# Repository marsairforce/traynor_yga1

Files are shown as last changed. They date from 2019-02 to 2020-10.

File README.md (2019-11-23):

# Traynor YGA1 Guitar AMP

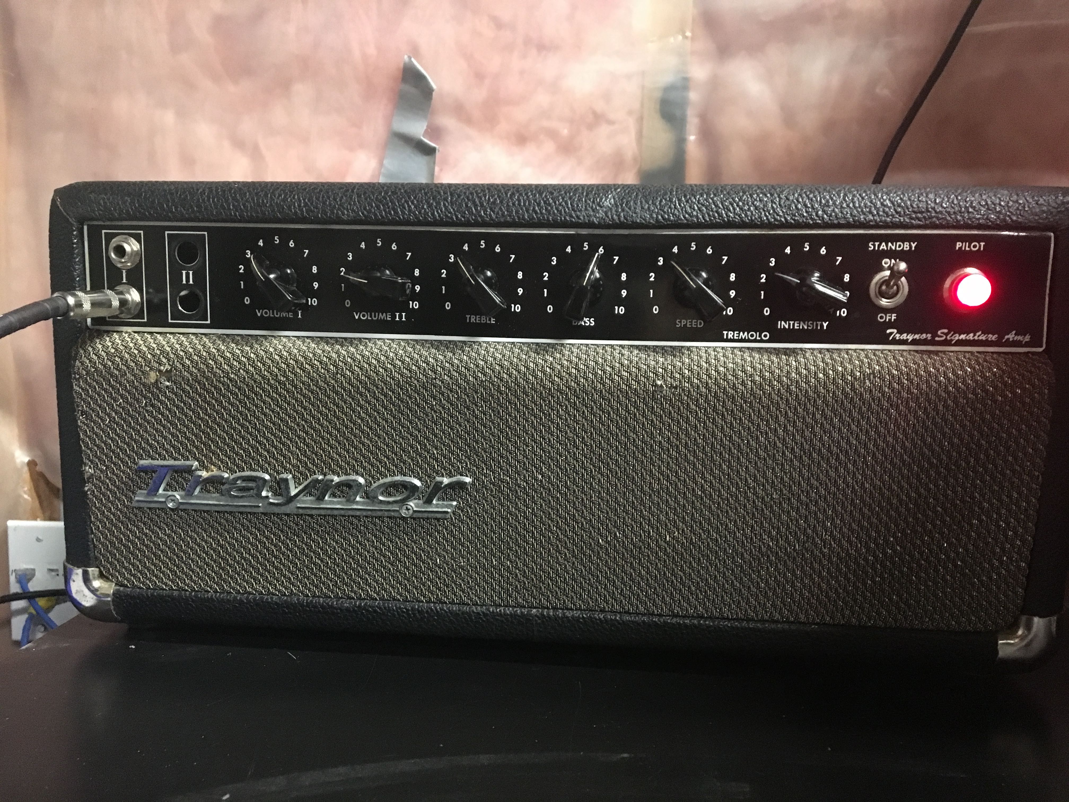
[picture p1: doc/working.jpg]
Working again


This is a project where I restored this old Traynor Signature guitar amplifier.

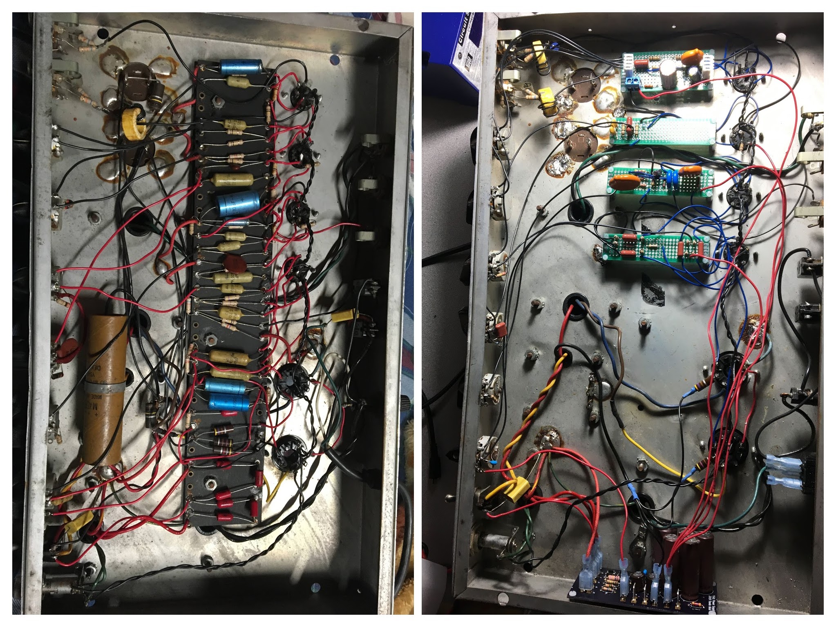
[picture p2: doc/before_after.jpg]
before and after


It was an adventure in learning how vacuum tube circuits work, some history of Canadian music and equipment, humility, nostalgia, and appreciation of finer things.

## Background

I got this in mid 1990's from my boss's nephew, Chris. It had caught fire and burned. The original wires were those 1960's cloth kind of insulation.

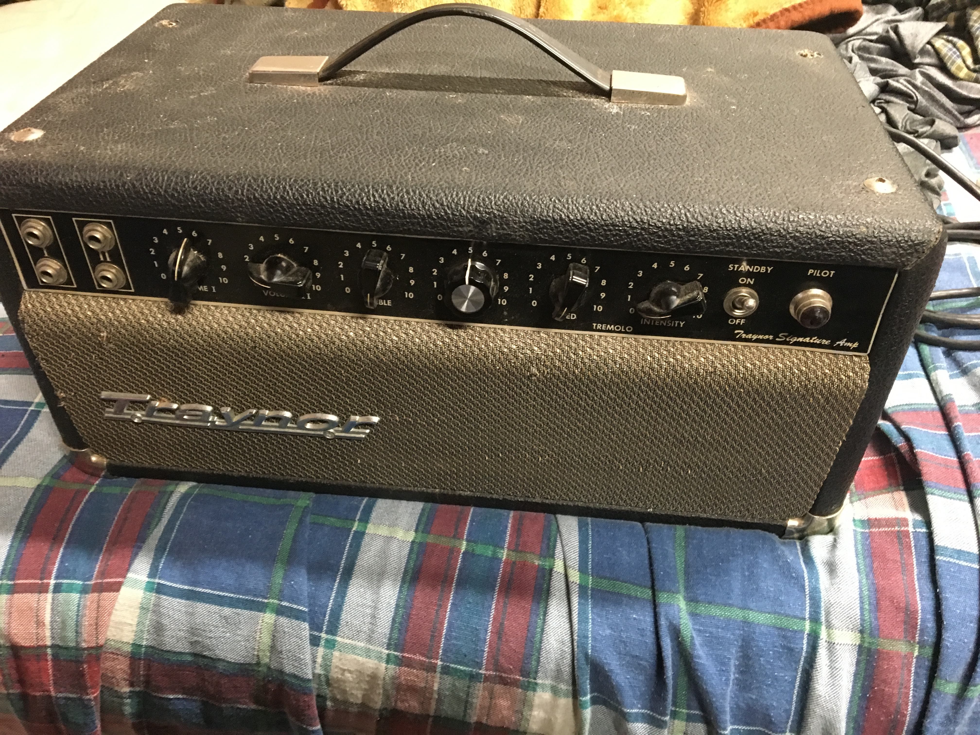
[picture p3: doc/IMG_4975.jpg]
Amp head


I did not understand vacuum tube electronics in depth. Other than they were metal in glass. No moving parts or semiconductors here. Just resistors and capacitors. If I replace all the burnt wires it should just work again right?

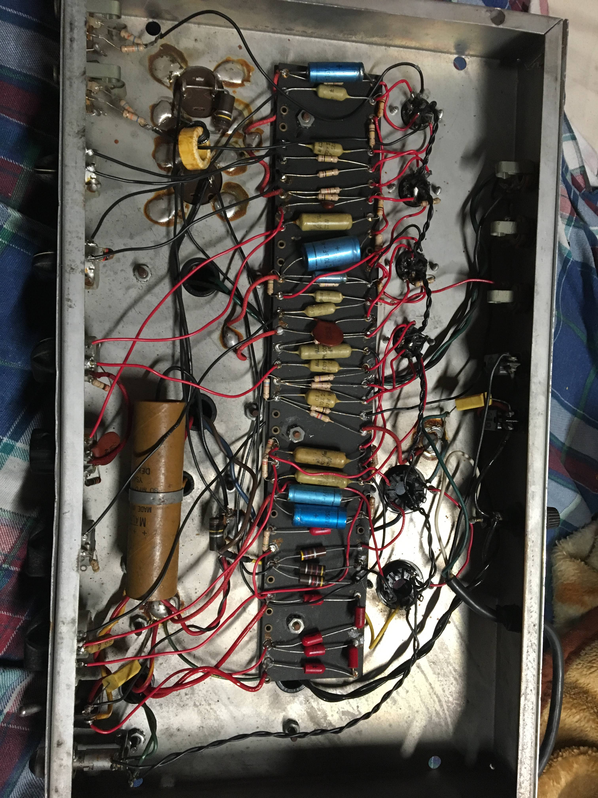
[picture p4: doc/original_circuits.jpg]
original circuit


I used modern wires (for 1990's) to rewire it.

A tube socket was missing a pin so I made a loop of wire and jammed it into the hole. Close enough.

Looking at the wiring I am a bit uneasy with the high voltage DC wires right there beside the input high impedance wires. The old point to point or ladder circuit construction is a lot different than anything I would consider to be a safe design today.

Recent research shows these amps are [basically indestructable](https://reverb.com/ca/news/a-guide-to-vintage-traynor-amps).

I only stopped using it when I stopped playing guitar when busy with university work. I moved away for internship and never returned home. My mom had it burried in the clutter at the house. She passed away, her friend Sandy who handled the estate shipped it to me.

But this is now 20 years later. Now that I am aware of old devices with the old paper style capacitors becoming electrically "leaky" I am afraid to even plug it in, thinking there could be a short and it would just burn the power transformer. Or something else would catastrophically fail.

## My gear

The amp worked well for me. I used it mostly with that Kramer guiter I custom painted to look like Franken Strat. It just sounded good.

I used it with discrete effects pedals to get the tone. And the built in tube tremolo feature was cool sounding. I remember having a Boss compressor pedal, the Boss HM2 pedal. :ater on I had an ADA microtube 200 with a Boss ME-10. I later sold the ME-10 to Chris Davis. Still have the ADA MT-200. That is probably a project in itself to see if that still works.

I had a yorkville bass amplifier. It went with the Ibanez 5 string bass I donated to the highschool when I graduated. But I remember using this with the bass because I had the speaker cabinet to go with the amp.

Unfortunately I did not get the speaker cabinet back.

## Ethics

Do we maintain everything as "all original", preserving the vintage electronics style of the day (the ladder construction).

Or do we create a modern PCB modules, connectors.

Or something in between.

I was amused with the [ship of Theseus](https://en.wikipedia.org/wiki/Ship_of_Theseus) thought experiment here.

At what point does it matter to continue to use this same chassis. I could go all the way and order new power transformer, choke, output transformer, tube sockets, tubes, and discrete components and build a fresh new amp on a new chassis.

Reading into the history of [Traynor amplifiers](https://en.wikipedia.org/wiki/Traynor_Amplifiers). They were originally hacked together by a tech at Long and McQuade to be a cheaper option for their equipment rentals. So less expensive but good enough.  Do I really want to build based on this? Or should I learn what a high end amp design looks like.

In any case at this time I really do not need to mass produce tube amplifiers. Even if I could get good prices on the components, there is no compelling reason to build one as it is at least as expensive as buying one already made and well packaged.

The amp was labelled as "ideal for modifications". It is in the herritage. And being a Canadian, I feel very special to have a piece of Canadian music history to play with.

And then some discussion from [Mr Carleson's Lab](https://www.youtube.com/watch?v=7VBVSEevXaY) sais to replace all the old capacitors, because they are all basically garbage when they age. And this will hurt the reliability of the amp over time.

Since this amp was created to be a regular amp at the time, and is kind of in rough shape. I think I will do my best to make it look nice on the outside (new chicken foot dial).

But for the inside I will replace the power supply circuitry with updated construction.

## Inputs

This amp has 2 input channels. They are mixed after the first preamp stage.

Each input has 2 1/4" mono audio Jacks. They are configured as

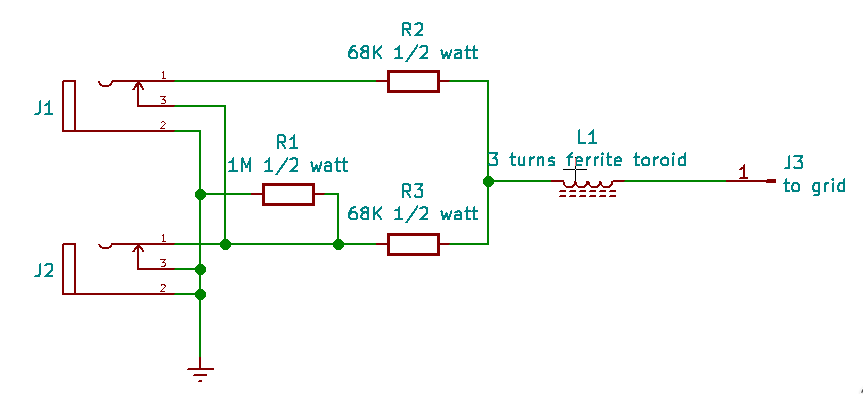
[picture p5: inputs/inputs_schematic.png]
inputs


Some thinking about this:

If we plug something into only J1:

* R1 is removed from switch on J2
* Signal is 1/2 of input because of R2, R3 resistor divider.

If we plug something into J2 only:

* R1 is in use.
* R2 is connected in parallel to R3, because switch in J1 is closed.
* Vo = 1M / (1M + 32K) or 97% of input voltage.

So here J1 is a "LO" inpedience, or line input, and J2 is a "HI" impedience, like microphone.

In our Amp, I put the HI inputs on the bottom.

## Preamp

The preamp stage uses a single 12AX7A, one half for each input channel.

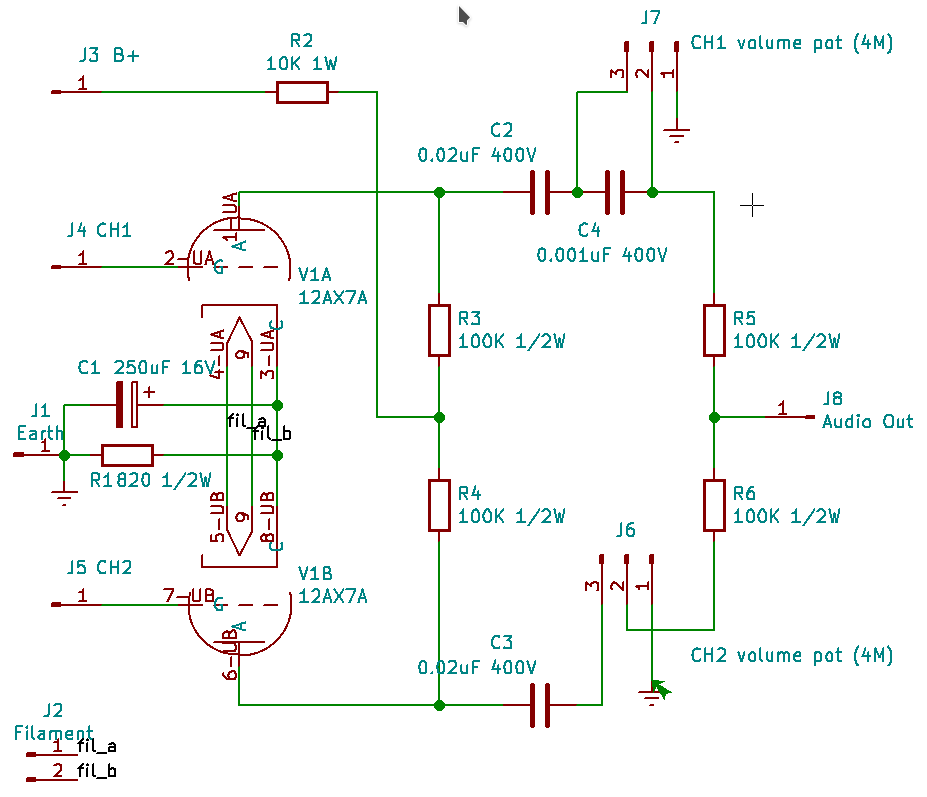
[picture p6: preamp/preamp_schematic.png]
preamp


This configuration is what is referred to as a [common cathode triode amplifier](http://www.aikenamps.com/index.php/designing-common-cathode-triode-amplifiers).

* We can see Channel 1 has the extra 0.001uF capacitor in parallel with the volume potentiometer. This will have the effect of a high-pass filter, or at least it will cut out a lot of the lower frequecies.

> This is actually channel II. At this time when reading the schematic I assumed to be channel I, but on the chassis it is labelled as Channel II.

Using a [cathode bypass calculator](https://www.ampbooks.com/mobile/amplifier-calculators/cathode-capacitor/calculator/), we can see for the values used here on the cathode (250uF, 820 ohm), that the gain is nearly uniform for all frequencies of input.
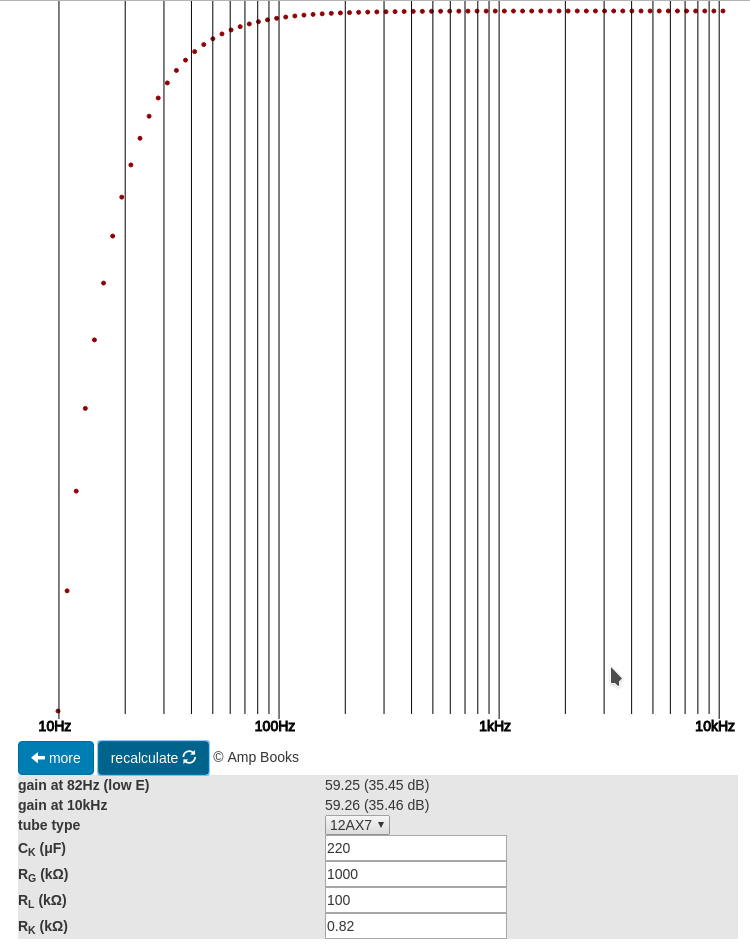
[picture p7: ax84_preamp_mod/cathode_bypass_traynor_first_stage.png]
traynor preamp stage


## Tone

The tone control circuit uses a 12AX7 as another intermediate amplifier stage.

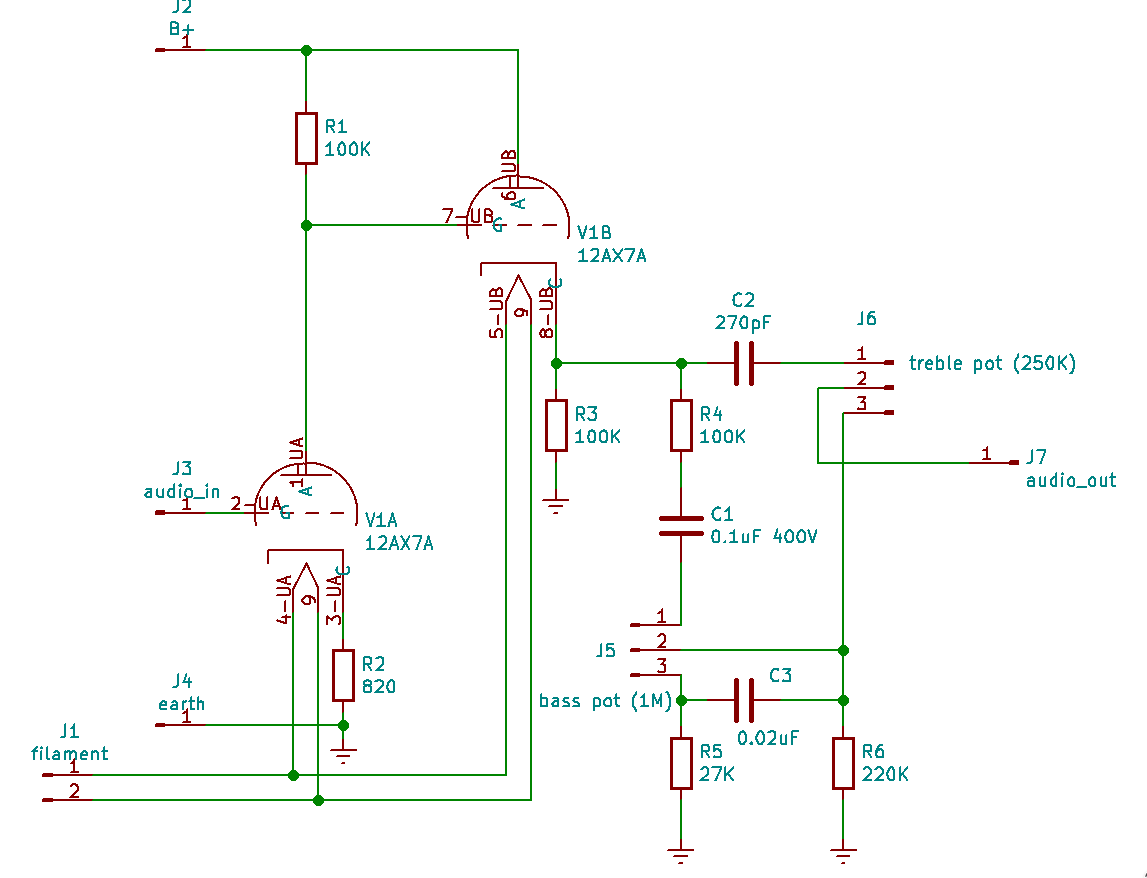
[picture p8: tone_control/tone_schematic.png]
tone stack


This configuration of the two triodes is called a [DC-coupled cathode follower](http://www.valvewizard.co.uk/dccf.html) It is by design built "badly", but this creates a low impedance output to drive the RC network or "tone stack" that manipulates the tone.

## Power Stage

This am is a push-pull amplifier.

Here a 12AX7A is used as a [Schmitt phase inverter](http://www.r-type.org/articles/art-123g.htm)

It also mixes the audio imput with the negative feedback from the output transformer.

The 7027A tubes are used here because they are higher power versions of the 6L6 tubes.

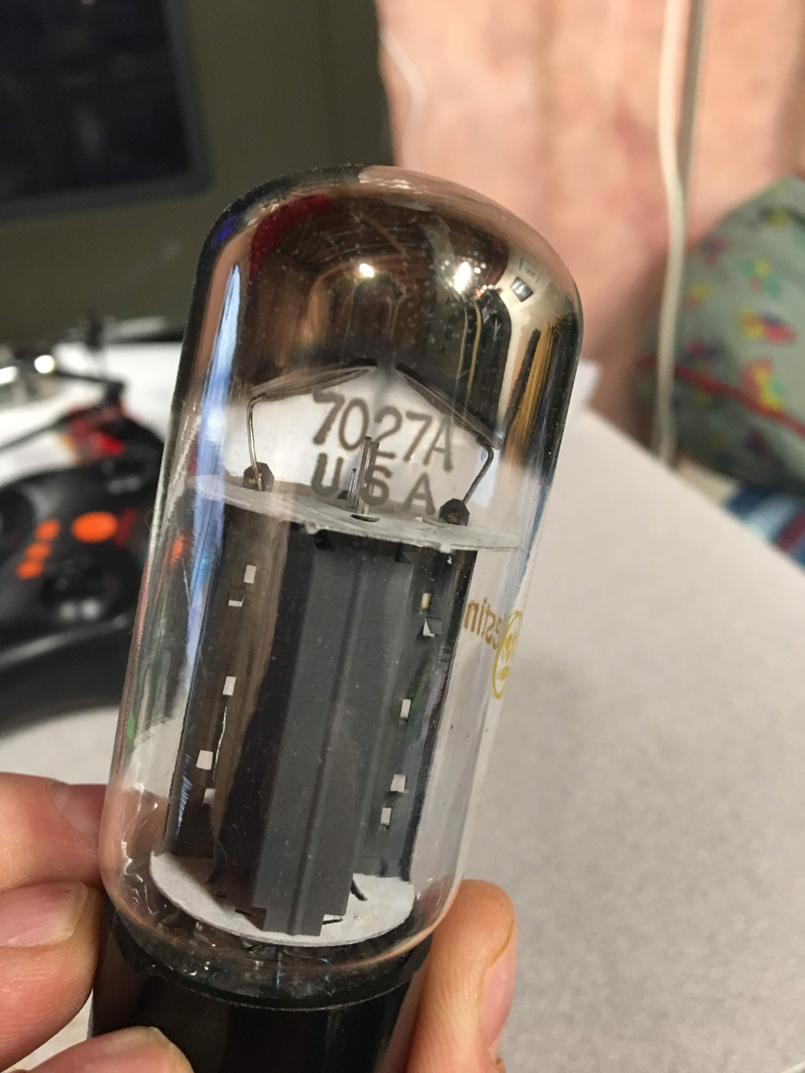
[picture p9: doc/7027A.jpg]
7027A


The 6L6 tubes are beam power tetrodes. They were created to circumvent patents in the pentode design. So beam power tetrodes have the function of penodes, but have a lower transimpedience, which works to make them more linear and have less distortion.

The output from the 7027A tubes is high impedence, so these feed the windings of an audio transformer. Because of the push pull design, the transformer center tab is connected to B+.

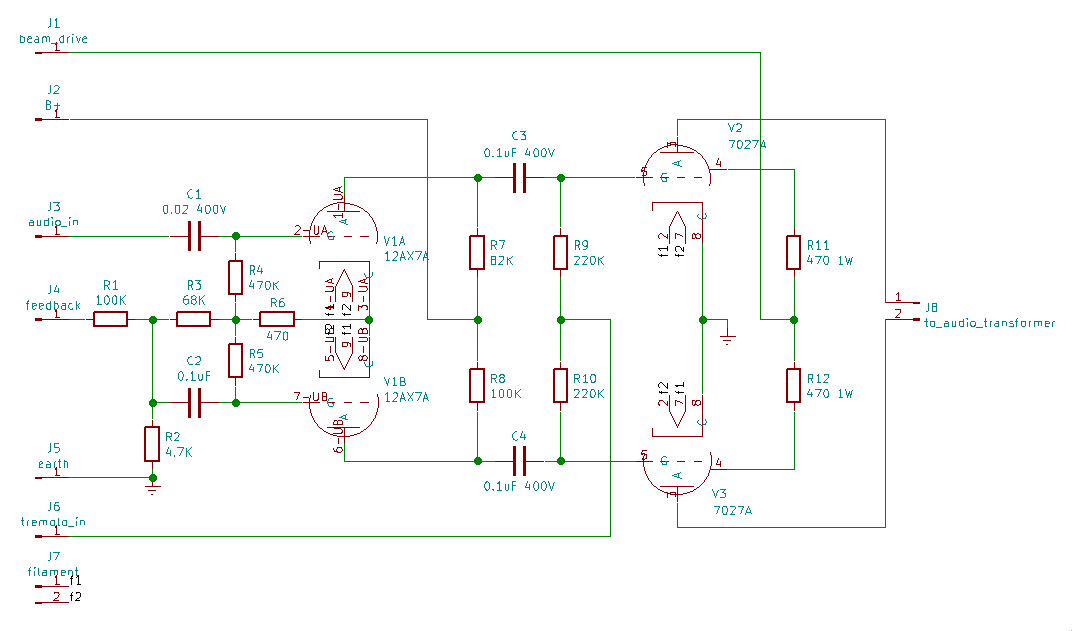
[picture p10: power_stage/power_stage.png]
power stage


* It drives the two 7027A through a capacitve coupling.
* The input from the tremolo oscillator circuit is mixed in.
* Why is R8 100K when R7 is 82K?  The small difference here of 18K?

## Tremolo

The tremolo uses a low frequency oscillator to modulate the audio volume in the power stage.

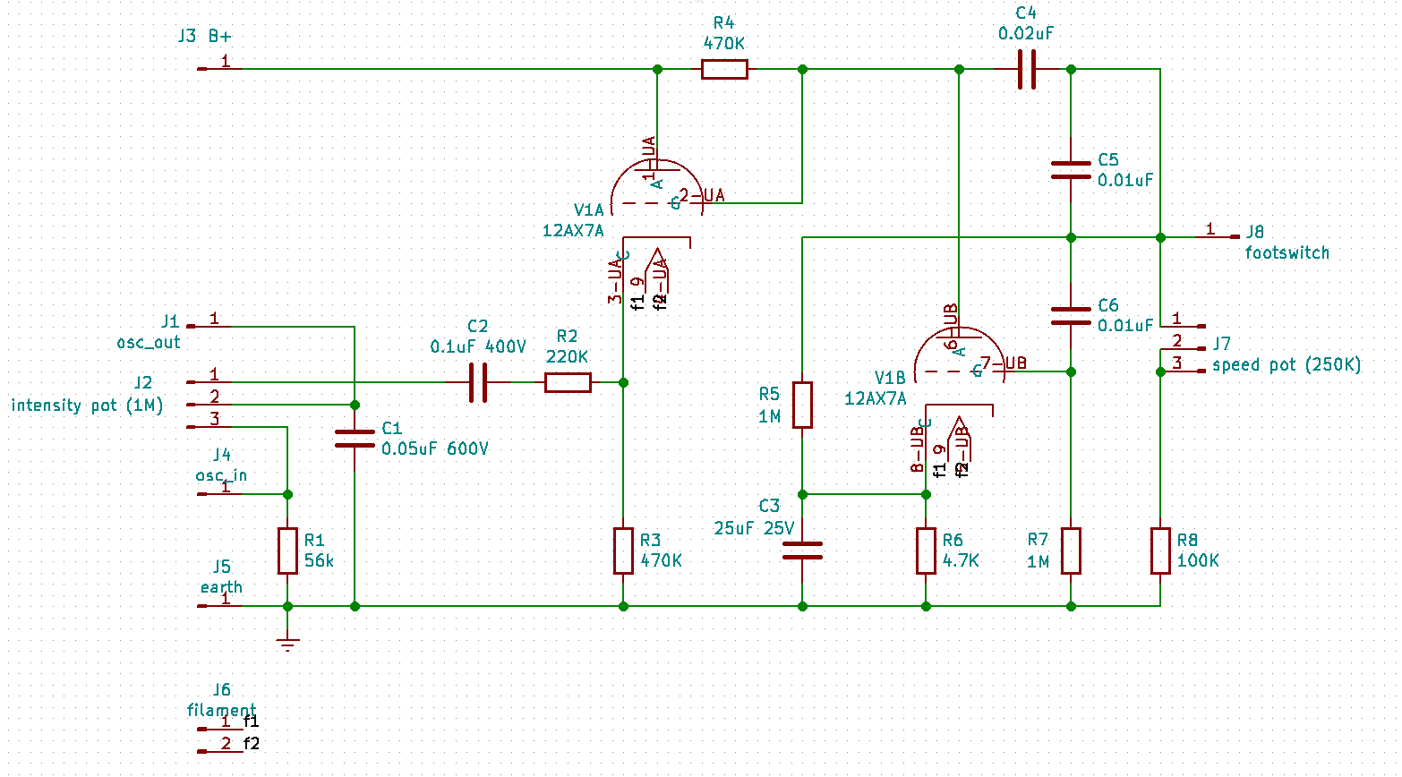
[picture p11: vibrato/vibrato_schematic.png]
vibrato


* I actually put R1 onto the power supply board too.

This looks a bit like this schematic from [popular electronics](http://www.rfcafe.com/references/popular-electronics/build-your-own-vibrato-dec-1957-popular-electronics.htm)

## Power Supply

This is a linear power supply with DC smoothing capacitors and a choke, but no regulation.

The power supply produces about 400V DC at the output of the diode rectifier.

The voltage that gets to the anode of the 12AX7A in the preamp stage is about 320V

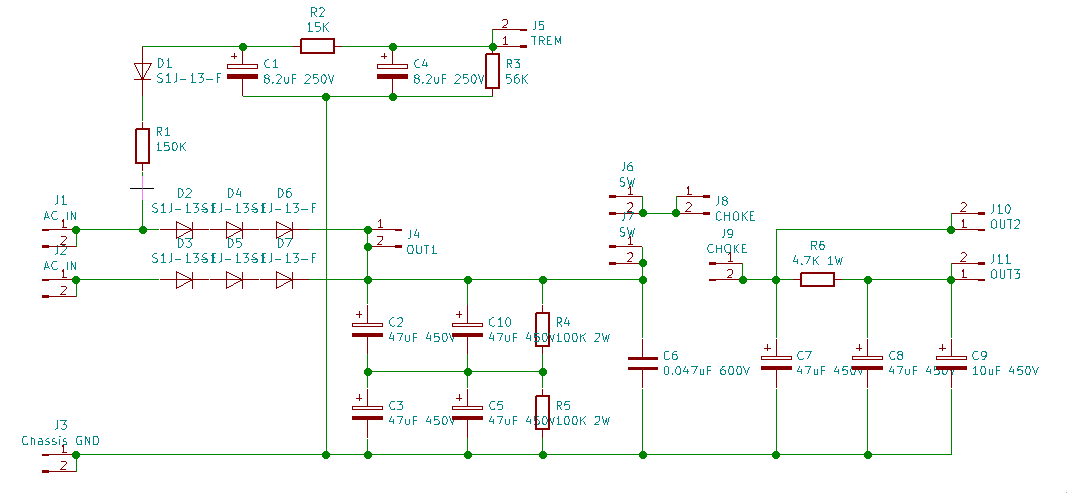
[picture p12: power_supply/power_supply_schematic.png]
power supply


* Why in this schematic is the power to the output audio transformer not after the standby switch. As it is in the original schematic this means the tubes would still be live when in standby with power on. - I later fixed this in my amp.

### Voltages

To measure the voltages I turned on the amp and waited about a minute for them to warm up. Initially the voltages were highter but they stabilize once the tubes are loading the circut. No audio input during the measurement.

* After the choke: 400V DC; 3V AC ripple (This ripple is probably because the capacitors are bad?)
* After the 4.7K resistor, B+ into the tone stack and vibrato: 340V DC ; 0.2V AC ripple.
* At the input preamp after the 10K resistor: 216V DC ; 0.2V AC ripple.
* Voltage into vibrato circuit: -40V; 0.2 V AC ripple.

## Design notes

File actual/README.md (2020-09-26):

# Schematic of current state of the amplifier

I will try to update this to be as current as possible to how the amp is actually wired up.

> Refer to the original schematic PDF when needed.  Where possible component reference numbers were reused.

## Preamp

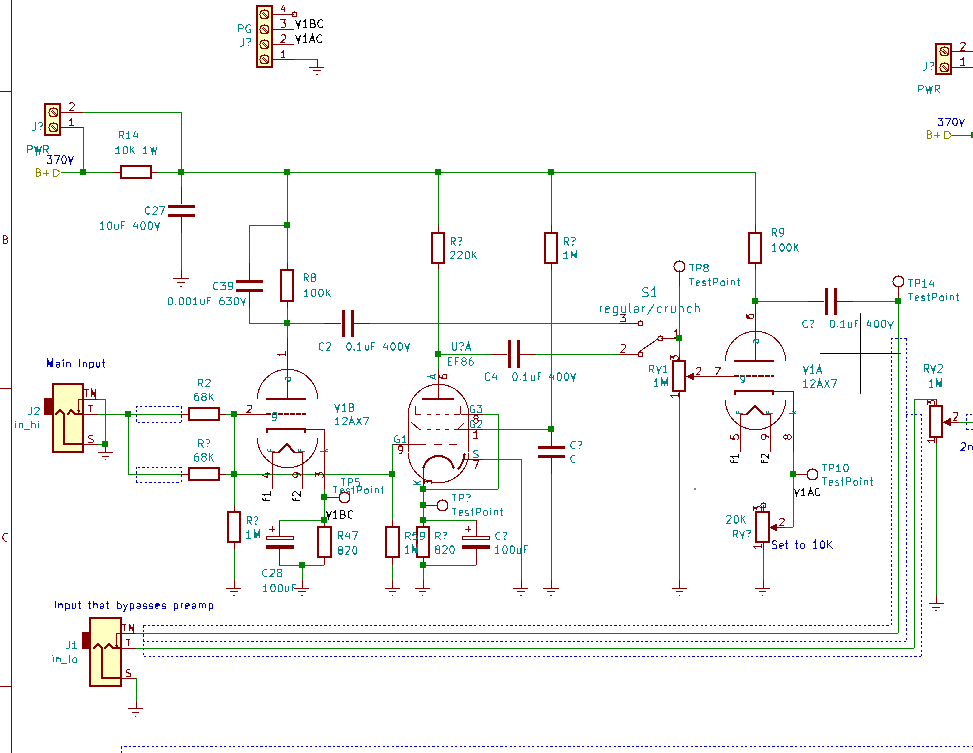
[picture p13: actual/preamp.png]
preamp


Notable changes:

* The input stage is no longer two parallel channels, but only one channel.

* You now have your choise of first stage preamp
  * A 12AX7 based on the original schematic. I added a plate bypass cap to help make it warmer (less high frequencies).
  * An EF86. This has a bit more gain and is a lot brighter sound to it.
* The second gain stage is a cathode clipper type configuration. The adjustable position lets me change the bias on the tube to allow it to distort more. I currently have this at about 2K
* Stock 2M pots for volume were changed to be 1M, mostly because this is all I could find. But also the old values seemed to do cause the amp to do oscillating or squealing when turned up.
* Added 1M grid stop resistor to be right before the input to the tube, instead of before the 68K resistors from the input jack.
* Using RG-178 coaxial wire for sensitive signal paths.

The power supply now supplies 4 additional tubes than the amp originally had. It seems way over sized for what it was designed to handle.

## Tone Stack

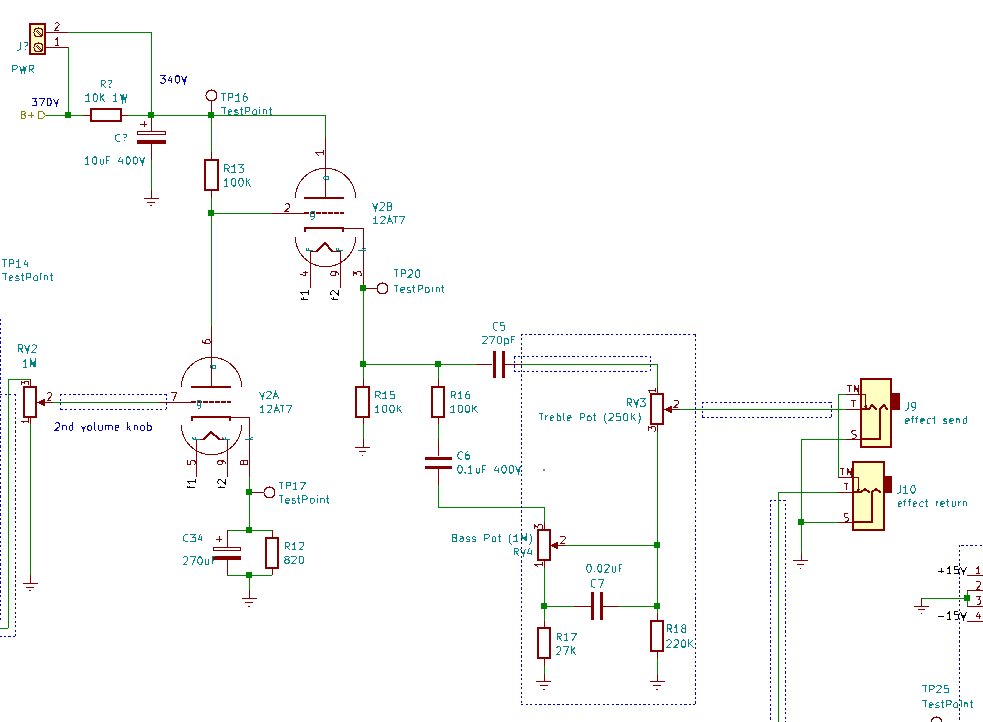
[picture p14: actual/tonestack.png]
tone stack


This is the most part the original tone stack. I just like how it sounds.

* The powr to V2 has been moved to go through a 10K resistor and a 10uF capacitor. I discovered by measuring with the scope there was a to 300mV 120Hz ripple on the power supply. This is as far as I can tell how the amplifier always was. It always had a small AC hum to it. I found I could swap out different tubes in this socket and make it get a bit better. But really what made the hum go away was the extra power supply filtering I added.
* The tube socket had pins 2 and 6 soldered together at the socket, under the filament wires. I was thinking this was picking up some of the noise from the AC filament wire that was right there. Sure enough, just rewiring this socket makes a little bit of improvement on not hearing hum on the speaker. This was another original assembly artifact or bug that I fixed with thea mp.
* There is now an effects send/return jacks. This amplifier did not have his. I like to use it a lot to add a noise gate, or digital delay effects after the preamp.
* The output of the tone stack (effects loop jacks) now goes to the reverb unit instead of the phase inverter.

## Reverb

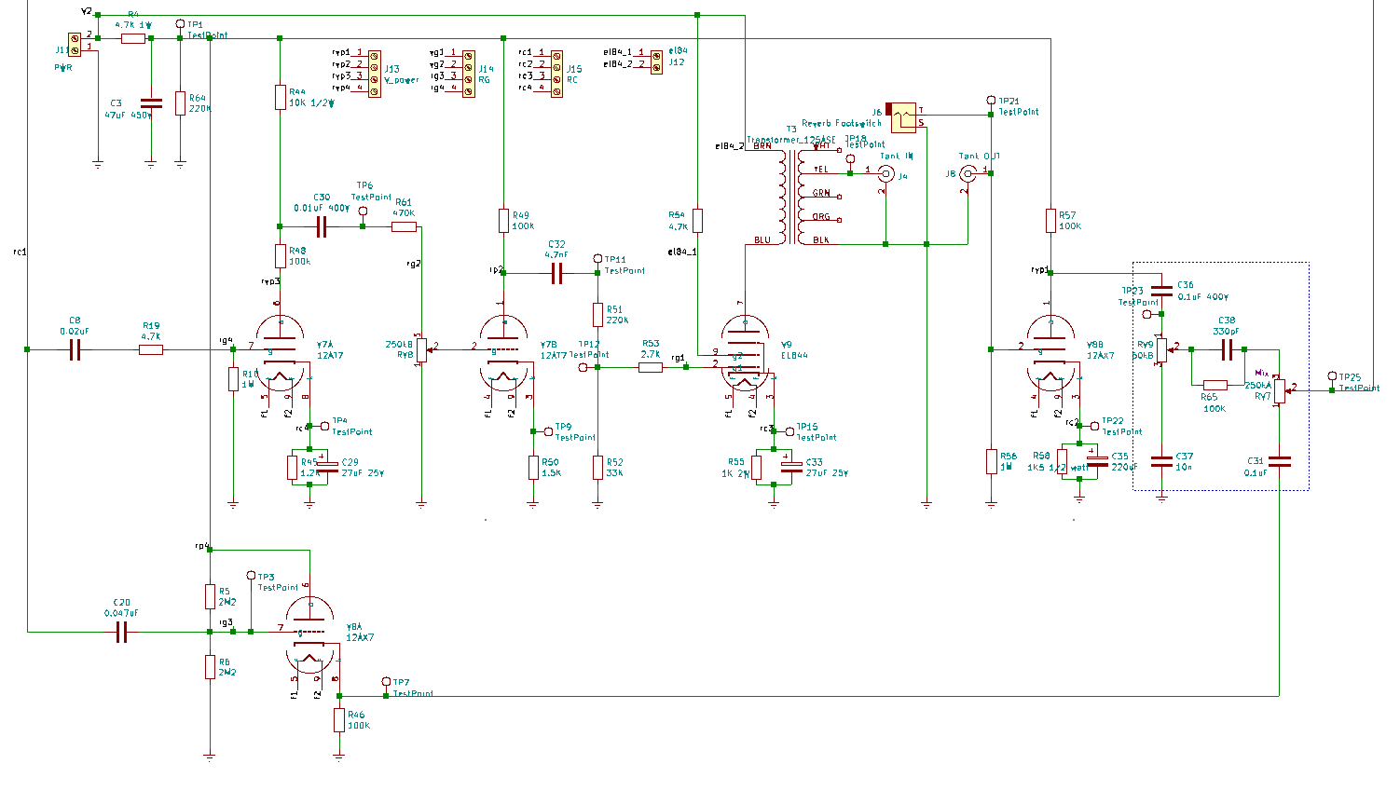
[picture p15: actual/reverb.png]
reverb


This is an entirely new component. The amp originally did not have reverb effect.

I ordered a mod reverb tank from NextGenGuitars. They are right here in Ottawa, great service for having stuff shipped. It's almost as fast as DigiKey.

This circuit is based on a reverb circuit schematic I found on the internet. I think from "Tube Town Reverb Kit".  They specify to use an EL844. I tried an EL84 for fun. I can't really notice a difference. But it kind of feels like the EL84 can overdrive the reverb output transformer, so you can get some intereting sounds with that. For now I will stick with the EL844.

The power transformer in this amp seems to be way over sized and does not even blink when I add 3 more tubes. Which is convenient.

I took some time to wire up the discrete components on its own circuit board module, like the other parts of the amplifier. It is now a hairy wires mess inside. But it works. After some preliminary testing and tracing all the component connections before powering it on, it worked for me right out the door.

I am amused by the complexity. To add reverb, you basically build a mini amplifier, inside your amplifier. I can see why the modern amps use digital modelling circuits.

Though I really appreciate having a tube driven real spring reverb effect. It is so much better to me than a reverb effect pedal anyway.

* using RG-178 shielded wire for the sensitive audio paths, like return from the reverb tank to the regeneration triode.
## Output

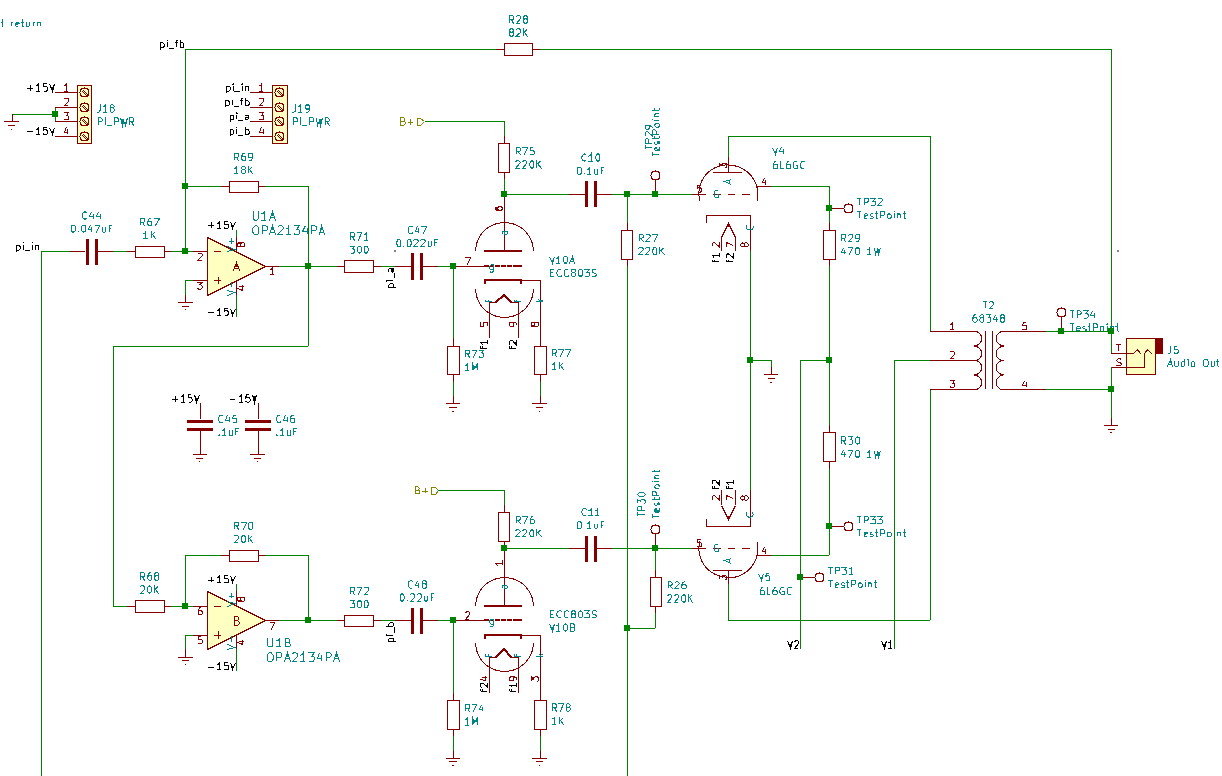
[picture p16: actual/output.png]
output


* Replaced the "long tail pair" tube based phase inverter with a solid state op-amp phase inverter.
  * This required a +/-15V DC power supply. I achieved this using a small DC-DC converter and diode rectitifer attached to the filament supply.

I was having some of that terrible buzz that means the phase splitter is not tracking opposite phases like it should. The values are all the right ones and it appears to be working. But It is likely stray capacatance, or magic that is letting it not operate properly. I am tired of the magic of this too. The op-amp phase inverter is a lot more precise than the long tail pair circuit.

* The annoying buzz or background hum that was always there is now gone.
* Fixed the squealing when gain knobs or tone knobs are up.

> I was chasing several high frequency oscillations since adding the reverb circuit. Having the gain up a bit past mid point, or having the tone control for the reverb on would cause screeching or loud hum and buzzing. Like the phase inverter was not working properly from being loaded.
> I have a feeling some of the noise is coming from stray capacitance from the terribly arranged and too long unshielded wires everywhere.  It is a side quest to make the wires as short as possible.
> It would appear the op-amp phase inverter has helped a lot of these demonic problems now as well!

One thing I do worry about, is if the audio signal is ever hundreds of volts like it may have been in the tube amplifier, that would be ok for the tube phase inverter. But the op amp would get roasted.

I measured the input voltages, and it seems to be the order of a couple volts. So this is likely ok for the levels I plan on using the amplifer.

## Power Supply

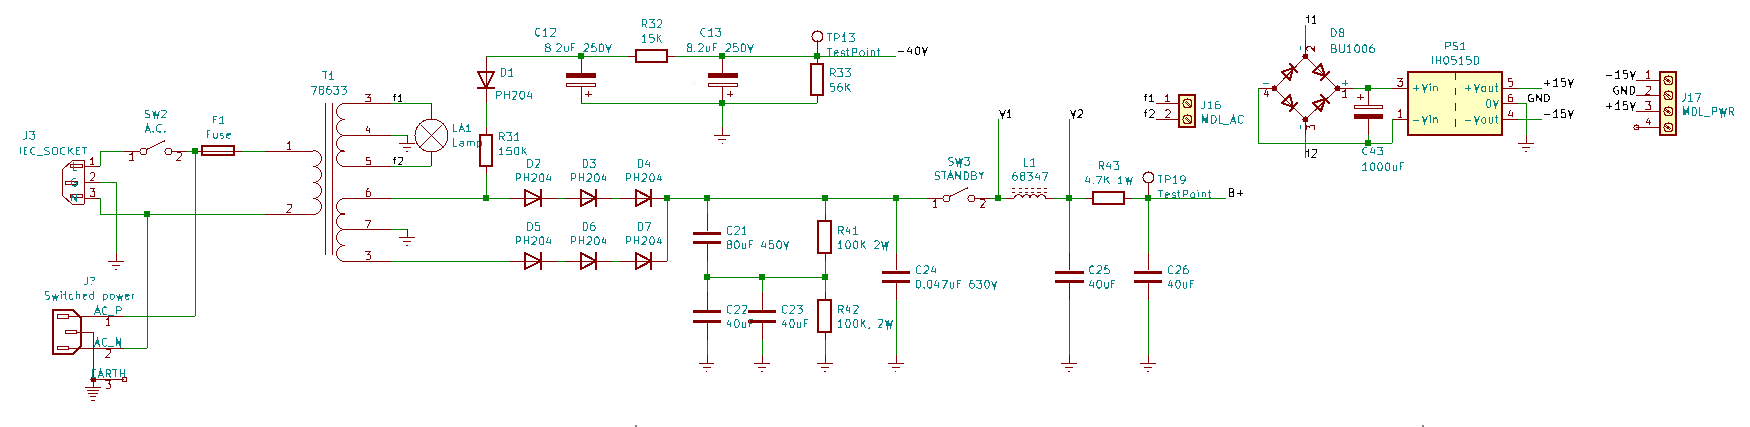
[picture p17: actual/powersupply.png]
power supply


* Removed the "death capacitor"
* Now having the V1 voltage to the output transformer switched. Before it was not switched by the bypass switch.
* I built a convenient custom circuit board, so these high voltage parts are safely tucked off to the side. This was among the first enhancements. The old turret board and chassis mounted capacitors had high voltage wires spread everywhere.
* Added a new module to use the [Recom RS-0505D](https://www.digikey.com/product-detail/en/recom-power/RS-0515D/945-1543-5-ND/2321270) to provide the +/-15V DC for the op amp in the phase inverter, by using the filament supply.
* Moved all the power entry chassis components to one corner. Before they were kind of sprawled over the back of the chassis.
* Added an IEC outlet after the power switch. This will allow me to switch the power to my pedal board from the amp switch now.

## Tremolo

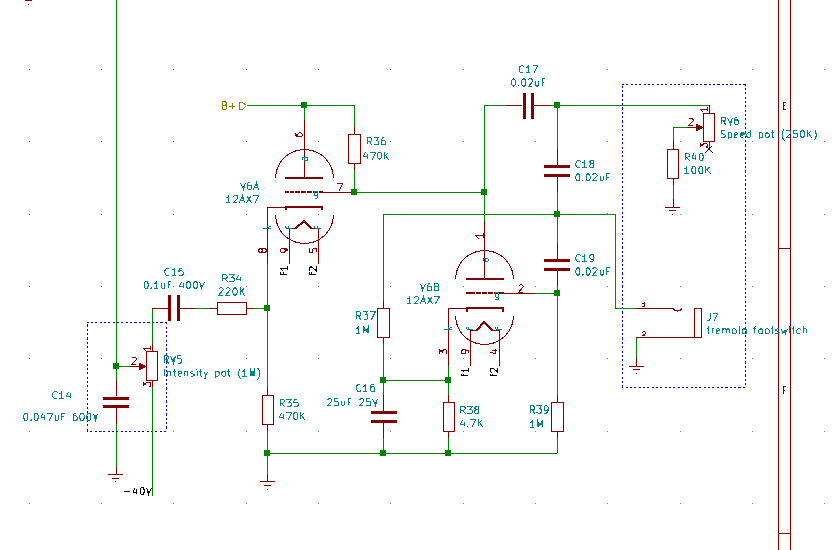
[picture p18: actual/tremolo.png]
tremolo


This circuit has not changed much from the original. I replaced all the parts with new parts of the same value. Except for

* Changed C18 and C19 from 0.01uF to 0.02uF. This has the effect of making the oscillator operate a bit slower. I found before it was entirely too fast to be usable.

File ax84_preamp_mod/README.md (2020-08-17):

# Experimental preamp  

I tried to use the values from the AX84 amp site. 

Where changing the module of the preamp circuit could run each stage of the V1 in series (instead of having the two stages in parallel like it was in the YGA1)

I found this sound to be thing and weak. It went straight from clean tone to undesireable to much clipping and buzzing overdrive, like how an op-amp would sound almost.

This could be a lot because at the time I did this experiement I did not understand the rest of the circuit, and how the way the tone stack and power stage are set up before to work under a high head room clean amp setting.  The large capacitor and small resistor on the cathode of the preamp stage before worked well with this setup.

I ended up taking this module out and putting back the original circuit. I later did do a cascaded input stage option, but with a switch to change it, and then using the existing cathode bypass resistor and capacitor for the second stage.  I still get some oscillations at high gain settings, but it is for the most part usable. 

I kept this folder around for reference and amusement.

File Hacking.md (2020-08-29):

# Hacks and mods

Some of this stuff is ideas. It is anywhere between a wishlist and a blog. See the [status](CHANGELOG.md) file for the a blog kind of list of what was done.

## Test Plan

Before and after making any change I would like to power up the amp and listen to it in different modes to see how the change sounds.

I would like to have some quantative test measurement. Set up a signal generator. Sweep through different input frequencies. Measure the output at different stages.

Connect an oscilloscope at different points of the circuit to see how the wavesform or phase changes would be very educational as well.

> The challenge is to make sure we understand what the circuit components are doing so as to not destroy expensive test gear or get electocuted.

Another challenge is lack of budget for test equipment. Efforts will be needed to design and build a signal generator.

## Differences from schematic

The schematic I found on the web is not exactly how my amp was built.

* C27 is actually after the 10K 1W resistor in the preamp module area. It is not attached to the C26 40uF in the power supply as the schematic shows it is. I believe this is wired correctly and the original schematic is wrong.

## Power cord

The chassis has a power cord coming out the back of it. The end of the plug is all corroded.

But why have a cord attached to it when the style these days is to use [C13/C14 connectors](https://en.wikipedia.org/wiki/IEC_60320#C13/C14_coupler) to accept an IEC cord.

* Update 2019-02-03: done.

## Power Supply

My first project was to replace the capacitors. But to also not worry about preserving the vintage interior of the things.

The power supply schematic:

power supply

Here I included the input part to the tremolo circuit, because it uses the AC line from the transformer with the diode as a half  wave rectifier to create a voltage reference to be passed into the vibrato circuit. It could have gone into vibrato (module). I just wanted to have all of the high voltage things in one spot. Technically this is power supply stuff, as these parts work to provide a -40V source to the oscillator circuit.

The schematic shows those 2 pins per connector because I am using these male metal spade connectors, and this was a hack to have the circuit board render the net list to have me include copper connection to both pins for the connector.

In hindsight I should have placed the beam power 4.7K resistors onto the power supply module.

### Voltages

To measure the voltages I turned on the amp and waited about a minute for them to warm up. Initially the voltages were highter but they stabilize once the tubes are loading the circut. No audio input during the measurement.

* After the choke: 400V DC; 3V AC ripple (This ripple is probably because the capacitors are bad?)
* After the 4.7K resistor, B+ into the tone stack and vibrato: 340V DC ; 0.2V AC ripple.
* At the input preamp after the 10K resistor: 216V DC ; 0V AC ripple - this was measured after I replaced the preamp components with modern ones. But there probably was a bit of ripple before, because there used to be a noticable hum in the output before.
* Voltage into vibrato circuit: -40V; 0.2 V AC ripple.

I would think we want no AC ripple anywhere. I will work to replace the capacitors in the power supply.

I designed a circuit board to hold all of the capacitors and resistors and rectifier diodes. This can be made small enough to put off to the side in the case. Here is a paper print out of the board layout.

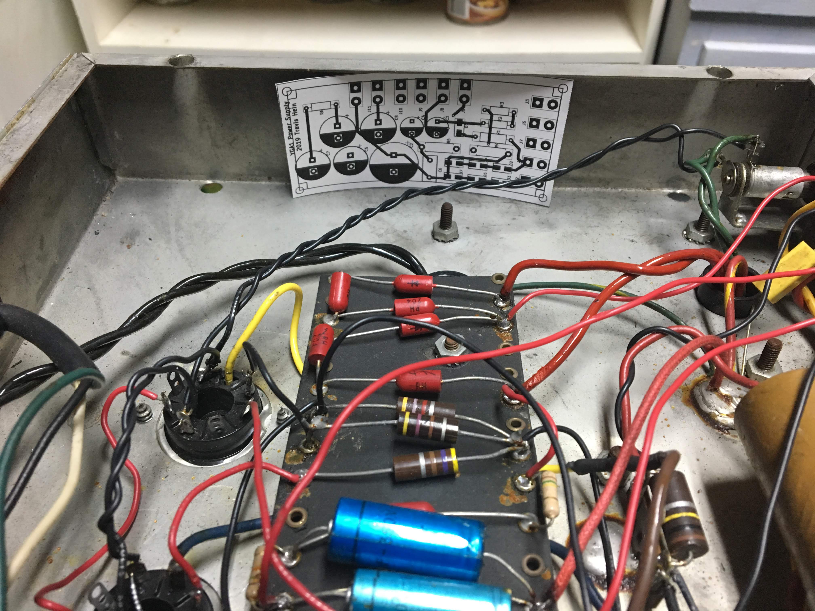
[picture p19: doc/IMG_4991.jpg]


I can then remove the original components. The idea was to leave the rest of the amp in this original construction.

Working more in kicad to get a 3D model:

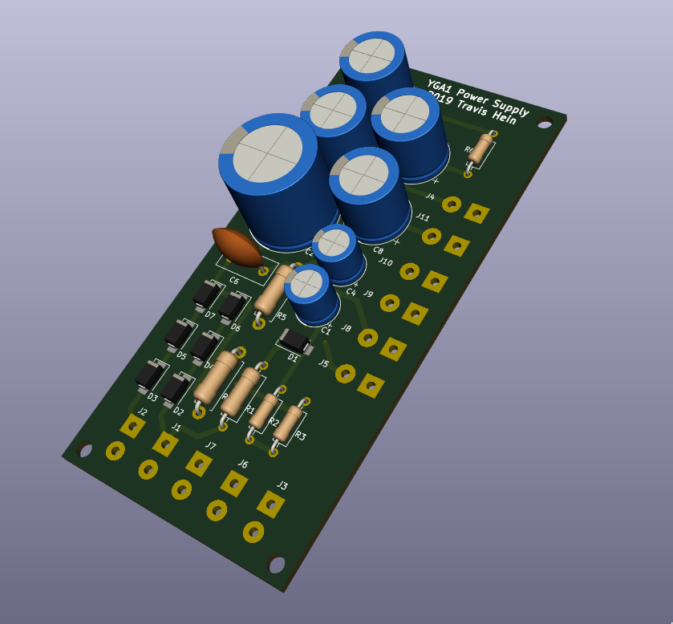
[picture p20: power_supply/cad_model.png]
power supply model


## Preamp grid bias fix

After reviewing the [common cathode triode amplifier theory](http://www.aikenamps.com/index.php/designing-common-cathode-triode-amplifiers), I am questioning why the inputs do not have a 0.02uF capacitor to decouple the grid input, and the 1M resistor on the tube-side of the capacitor for grid bias.

Also these 68K input stage [grid resistors](http://www.aikenamps.com/index.php/grid-resistors-why-are-they-used) should be soldered onto the tube socket, not the input jacks. And the 1M grid bias resistor should be on the tube side of the input, which it also is not.

With this in mind, I created a v1.1 of the preamp circuit:

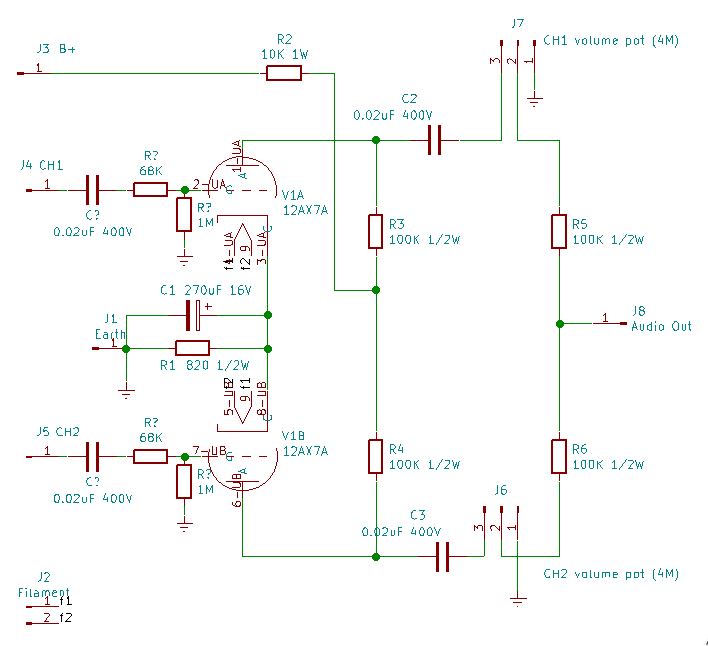
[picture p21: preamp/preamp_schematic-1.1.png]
preamp v1.1


* Added grid capacitor to decouple DC component from input.
* Moved the 1M and 68K resistors from input jack to be soldered onto the tube socket leads (or like super close).
* Removed the 0.001uF tone cap on the Channel 1 signal path. I don't have a need for one channel to sound different from the other channel.

This means the 2 jacks for each channel will go away, We only have a single jack now for each channel. Which is ok really. We never would plug more than one thing into the same channel. And we don't need to have a low/high impedence input.

Testing is needed with effects processor devices. Maybe we keep the two jacks and leave a 68K resistor dividor on the input of the LOW jack,

### Results

I tried this modification.

It sounds ok. There was sound and it was clean. But it had no personality or feel to it. Like there was a bit less gain.

I changed the inputs for channel 2 only. So switching the guitar back and forth to channel 1. the 0.02uF ceramic capacitor I have takes a lot something out of the sound.

Rolling back to the original input for channel 2.

## Preamp input module

Create a small circuit board for the discrete components of the preamp circuit. The green board on the left inside the chassis.

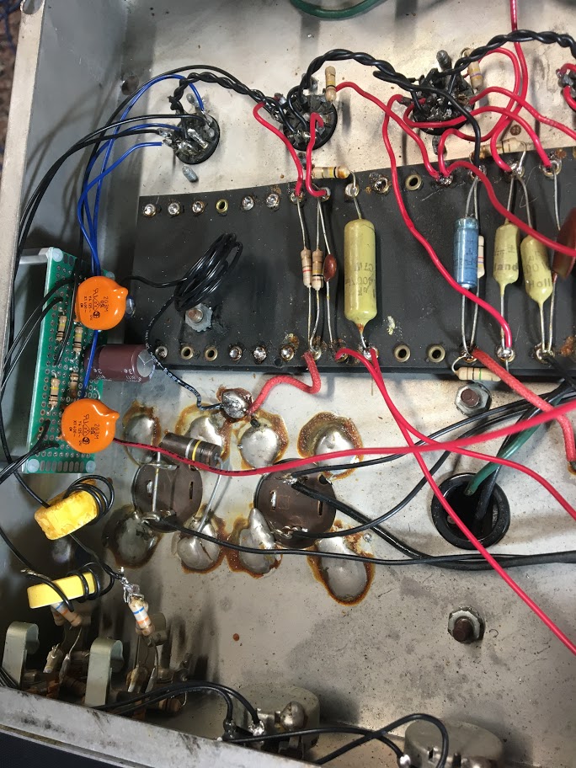
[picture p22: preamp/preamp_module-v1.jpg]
preamp module v1


* grid bias capacitor (250uF) and resistor (820 ohms)
* 10K 1W resistor from B+
* 10uF capacitor.
* 2x 100K resistors to the anodes.
* 2x 0.02uF capacitors to volume pots.
* 2x 100k resistors to audio out.

Assemble the circuit board. Using the usual crude point to point soldering on the solder side of the board. Just the leads of the components to each other here.

Screw it to the inside of the case using standoffs and nylon screws. Use 100 watt solder iron to attach ground wire to chassis.
The extra black wire is in case I want to run this over to the power supply board later.

Connect the grid bias capacitor and resistor. Then power up and test. It continues to sound ok. Not broken anyway.

Power it off. Wire up the rest of the resistors and capacitors. Wires going to the 1st 12AX7A tube and the volume pots.
Remove the old parts and wires from the ladder construction.
Placing the wires neatly as close to the chassis as possible, keeping the wires as short as possible as well.

I depopulated the old components from the ladder board. These are those empty rivets on the entire left end of now. I removed 12 components today.

Turn the amp on, plug it into my computer and test it as a speaker for a bit. It isn't catching fire. So thre is that.

Measure the voltage into the 12AX7A again. It now has 0V AC ripple. Before it was 0.2V AC ripple, which was probably why we were hearing the hum on the output. I think the ripple went away because we have the new 10uF capacitor there.

## Tone Control

The tone control in the amp is pretty basic.

I found this neat looking one http://www.angelfire.com/electronic/funwithtubes/Amp-Tone-A.html#Amp-Tone_Control-3-A-back
More discrete parts. I would need a way to make the tone control modular. To swap out the original  ones with a new one. But I don't see how to do this in this chassis. This mighe be a good project for a new amp design.

## Add a reverb

Actual spring reverb.

## Effects Loop

There is no convenient way to connect the GSP1101 effects processor to this amp using the 4 wire method because there is no effects loop. All I can do now is have the guitar go into the GSP1101 and then the output of the GSP1101 go into the amp inputs.

More thought is needed if we need  this.
I think, yes. because if we want to have the preamp overdrive things to have tube distortion, but have reverb added after the preamp from an effects loop.

# A JCM800 style preamp

See [discussion](https://robrobinette.com/Tube_Guitar_Amp_Overdrive.htm), where having a biased triode to create a "cold clipper" causes more asymetric distortion. The grid resistor of 10k without a bypass cap.  Though this would require another valve than I have. It is not a simple rewire the preamp like I did with the AX84 mod. This is perhaps better suited for its own project, like a stand alone stomp box that can be used with other things too.

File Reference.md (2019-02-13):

# Other sites of interest

* [Aiken amps](www.aikenamps.com) Small guitar amp company.
* [TubeLab](http://tubelab.com/) Dedicated to advancing the state of the art in affordable high end audio.
* [The Valve Wizard](http://www.valvewizard.co.uk/index.html) Website and book on tube amp theory.
* [R-type](http://www.r-type.org/) Vacuum tube history, theory, and museum.

## Calculator tools

* [Plate Bypass Calculator](https://www.ampbooks.com/mobile/amplifier-calculators/plate-bypass-capacitor/)
* [Coupling Capacitor Calculator](https://www.ampbooks.com/mobile/amplifier-calculators/coupling-capacitor/)

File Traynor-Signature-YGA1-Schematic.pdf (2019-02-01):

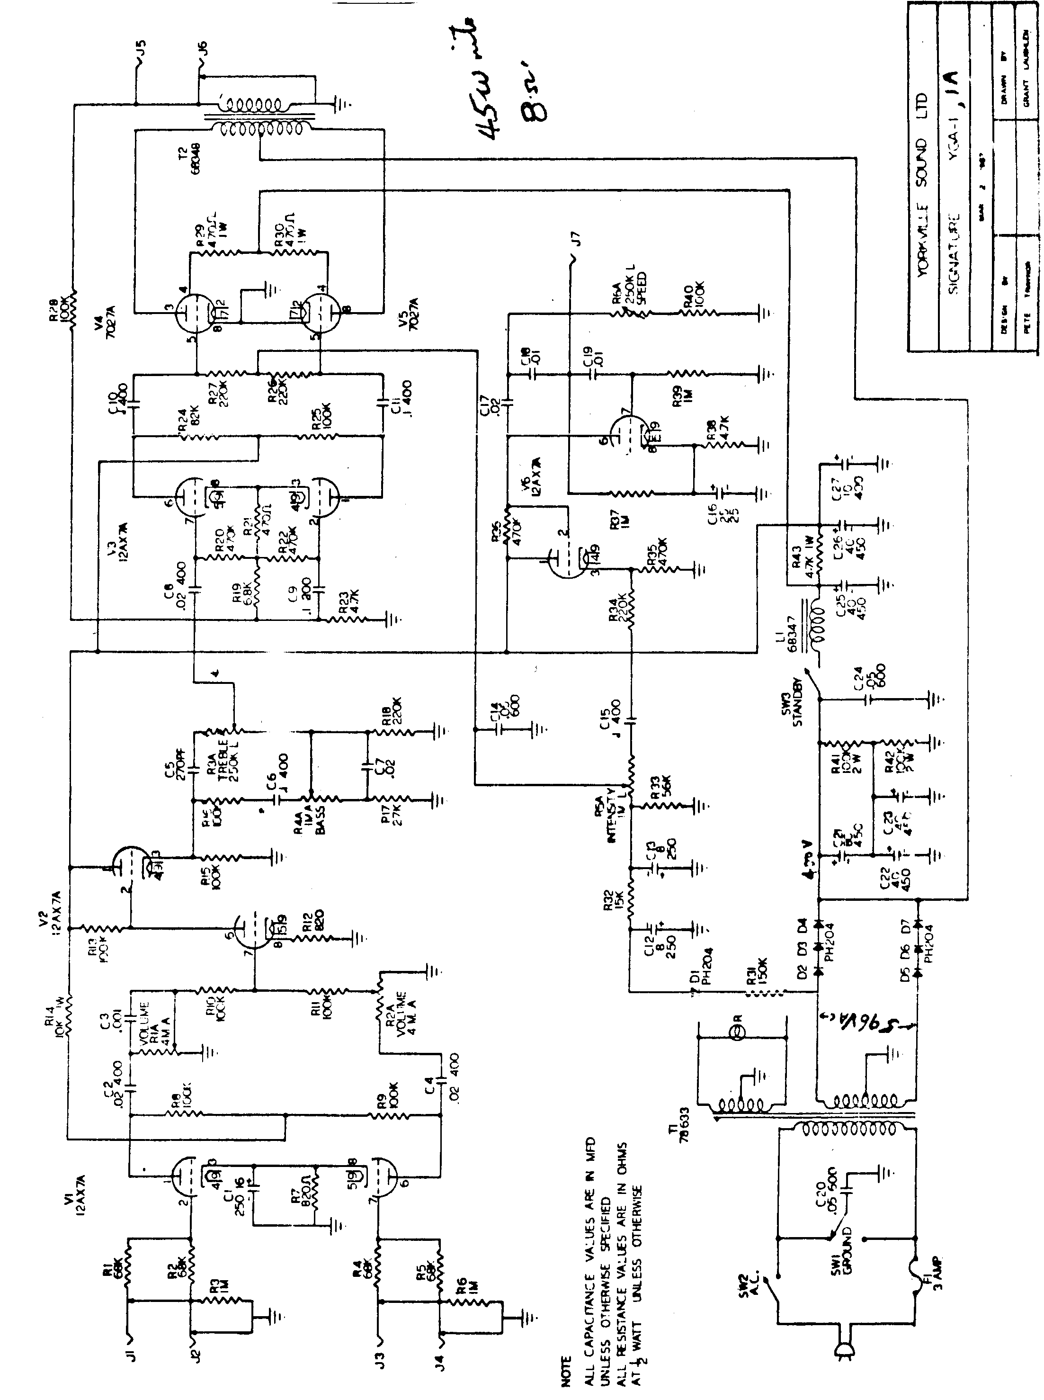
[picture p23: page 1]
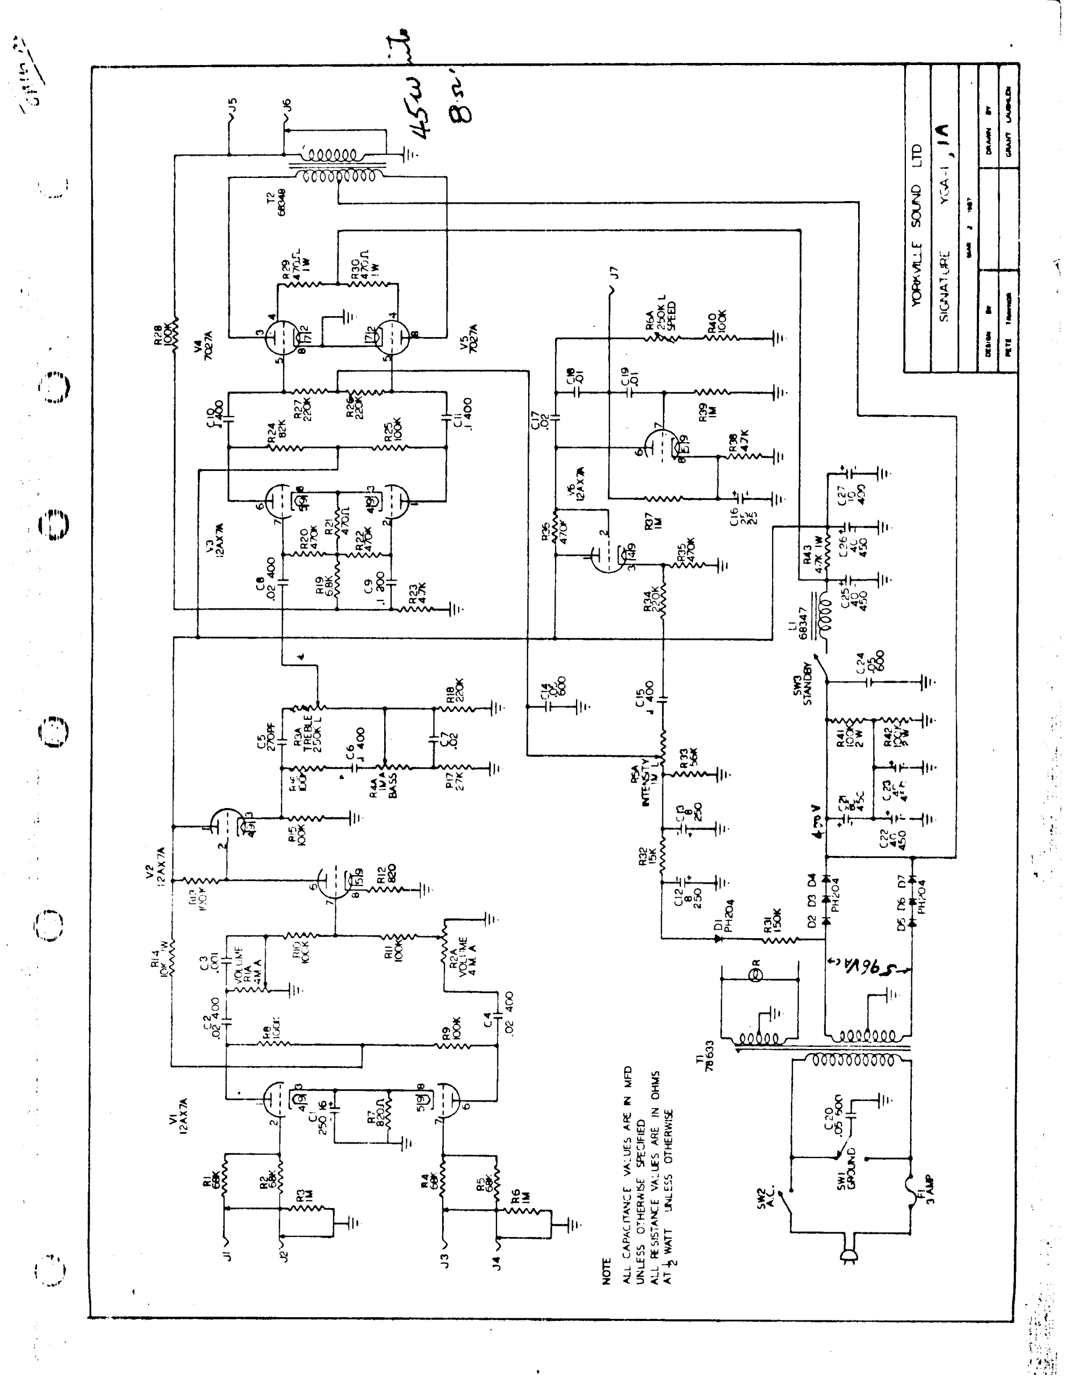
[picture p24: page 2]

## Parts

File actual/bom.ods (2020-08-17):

Component | Value | In Circuit | In Stock | Order#
C1 | 270uF 16V | Y
C10 | 0.1uF 400V | Y
C11 | 0.1uF 400V | Y
C12 | 8.2uF 250V | Y
C13 | 8.2uF 250V | Y
C14 | 0.047uF 630V | Y
C15 | 0.1uF 400V | Y
C16 | 25uF 25V | Y
C17 | 0.02uF | Y
C18 | 0.01uF | Y
C19 | 0.01uF | Y
C2 | 0.02uF 400V | Y
C21 | 80uF 450V | Y
C22 | 40uF | Y
C23 | 40uF | Y
C24 | 0.047uF 630V | Y
C25 | 40uF | Y
C26 | 40uF | Y
C27 | 10uF 400V | Y
C28 | 1uf 16V | Y
C34 | 1uf 50V | Y
C4 | 0.02uF 400V | Y
C5 | 270pF | Y
C6 | 0.1uF 400V | Y
C7 | 0.02uF | Y
C8 | 0.02uF 400V | Y
C9 | 0.1uF 400V | Y
D1 | PH204 | Y
D2 | PH204 | Y
D3 | PH204 | Y
D4 | PH204 | Y
D5 | PH204 | Y
D6 | PH204 | Y
D7 | PH204 | Y
F1 | Fuse | Y
J1 | in_lo | Y
J10 | effect return | Y
J2 | in_hi | Y
J3 | IEC_SOCKET | Y
J5 | Audio Out | Y
J7 | tremolo footswitch | Y
J9 | effect send | Y
L1 | 68347 | Y
LA1 | Lamp | Y
R1 | 68K | Y
R11 | 100K | Y
R12 | 820 | Y
R13 | 100K | Y
R14 | 10K 1W | Y
R15 | 100K | Y
R16 | 100K | Y
R17 | 27K | Y
R18 | 220K | Y
R19 | 68K | Y
R2 | 68K | Y
R20 | 470K | Y
R21 | 470 | Y
R22 | 470K | Y
R23 | 4.7K | Y
R24 | 82K | Y
R25 | 100K | Y
R26 | 220K | Y
R27 | 220K | Y
R28 | 100K | Y
R29 | 470 1W | Y
R30 | 470 1W | Y
R31 | 150K | Y
R32 | 15K | Y
R33 | 56K | Y
R34 | 220K | Y
R35 | 470K | Y
R36 | 470K | Y
R37 | 1M | Y
R38 | 4.7K | Y
R39 | 1M | Y
R40 | 100K | Y
R41 | 100K | Y
R42 | 100K 2W | Y
R43 | 4.7K 1W | Y
R47 | 2.7K | Y
RV10 | 100R | Y
R7 | 820 | Y
R8 | 100k 1/2W | Y
R9 | 100K 1/2W | Y
RV1 | 1M | Y
RV2 | 1M | Y
RV3 | 250K | Y
RV4 | 1M | Y
RV5 | 1M | Y
RV6 | 250K | Y
S1 | regular/crunch | Y
SW2 | AC | Y
SW3 | Standby | Y
T1 | 78633 | Y
T2 | 68348 | Y
V1 | 12AX7 | Y
V2 | 12AX7 | Y
V3 | 12AX7 | Y
V4 | 7027A | Y
V5 | 7027A | Y
V6 | 12AX7 | Y
R10 | 1M | N | Y
R59 | 1M | Y | Y
C30 | 0.01uF | N | N | 65452621
R50 | 1.5K | N | N | 65452621
R58 | 1.5K | N | N | 65452621
R46 | 100K | N | Y
R48 | 100K | N | Y
R49 | 100K | N | Y
R57 | 100K | N | Y
C31 | 100nF | N | Y
C36 | 100nF 400V | N | Y
R44 | 10K 1/2W | N | Y
C37 | 0.01uF | N | N | 65452621
T3 | 125ASE | N | Y
V7 | 12AT7 | N | Y
V8 | 12AX7 | N | Y
R45 | 1.2K | N | Y
R55 | 1K 2W | N | N | 65452621
R3 | 1M | Y | Y
R56 | 1M | N | Y
R53 | 2.7K | N | Y
R5 | 2.2M | N | N | 65452621
R6 | 2.2M | N | N | 65452621
C32 | 4.7nF | N | Y
R51 | 220K | N | Y
C35 | 220uF | N | Y
C29 | 22uF | N | Y
C33 | 22uF | N | Y
RV7 | 250KA | N | N | 65452621
RV8 | 250KB | N | N | 65452621
C38 | 330pF | N | N | 65452621
R52 | 33K | N | N | 65452621
R54 | 4.7K | N | N | 65452621
R4 | 4.7K 2W | N | N | 65452621
C3 | 47uF | N | Y
R61 | 470K | N | Y
C20 | 47nF | N | N | 65452621
RV9 | 50KB | N | N | 65452621
V9 | EL84 (socket) | N | N | #27574 (nextgen)
J6 | Reverb footswitch | N | Y
J4 | Tank in | N | N | 65452621
J8 | Tank out | N | N | 65452621

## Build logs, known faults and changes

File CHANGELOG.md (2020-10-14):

# Status Log

This is the documentation of the amp state.

## 2020-10-14

* Remove the anode bypass capacitors from preamp tubes.  I felt it sounded too dark. It did not have that sparkly crispness I had come used to hearing.
* Adjust RV9 to 2.6K

## 2020-10-11

* Change C20 (capacitor into cathode follow of reverb module) from 0.047uF to 0.1uF.
* Change C44 (capacitor into phase inverter) from 0.047 to 0.1uF.
* Change R1 (resistor into phase inverter) from 68K to 33K resistor.

Hoping to allow more lower frequencies to pass through.

* Change R1 and C44 into phase inverter to be switchable with dual SPDT toggle switch, to use the Hammond 107V audio transformer to couple the reverb stage to the op-amp phase inverter stage.

Investigating how this sounds.

It seems to make it sound a little bit louder. I hear a bit less low end, because the frequency response of this transformer is 300Hz bottom end. I sort of hear a bit of buzzy sound. This transformer is sensitive to magnetic interference from other transformers and AC signals in the chassis. Moving it and touching it changes the noise I get out of the amp.

And the tremolo does not sound as nice. Oddly it cuts abruptly in and out. Like there is less drive or loading to the stage.

Sometimes experimentation does not make a result we like.
Roll back the attempt to try to switch the coupling capacitor to the phas inverter with a transformer.

But leave the shielded wire section from the reverb out to the phase inverter in. Slowly converting all the signal path o shielded wires.
Recycle some of the shielded wires I took out from tonight's experiment to the reverb dwell pot too.

While on the tremolo, it is too fast for me still

* Replace C17 from 0.02uF to 0.047uF. It is a bit slower now. Good.
* Replace the otehr C18 and C19 with metal film caps. I am sure the ceramic ones worked ok. But they were super large and brittle, i broke one before moving things. And I think they are suceptable to temperature changes. I notice the temolo runs a bit faster when the amp is warm.

Tremolo definitely sounds more useful to me now. A bit slower.

* Investigate changing out R9 (anode resistor on V1A, cold clipper valve). Wanting to see if I can help reduce it's headroom a bit.
* Experiment with setting RV9 (cathod clipper adjust) from 2K to 5K.
* Add a 0.001uF capacitor to bypass R9 to try to take down the high frequency shrill a little bit., But now I am worried it sounds a bit too dark.

I attempted to try to put the 107V transformer as the output stage of the 12AX7 tube on the reverb. It is too quiet. Of course, this is only 25K primary. I need ore power, or higher impedance to make this work properly. Oh. well. I was hoping the transformer would better filter out lower reverb frequencies.

* Replace R20 and R21 (network out of reverb unit into reverb mix) with a 1M pot on the back. This lets me fine tune the level. I think this helps me find that spot to get better balance of volume of full reverb but without the small hum sound I was getting. Whatever. I had a hole there in the chassis anyway. And its less hacky than having the resistors and capacitor on the wire. Install another shielded cable. This one goes under the reverb circuit board. Good to get it in while I had it

Put back in the 6l6GC tubes. Figure I don't run it loud enough to burn the nice 7027 ones. These are those Ruby tubes I pulled out of the Traynor YBA-300.

Going to try to use amp for a bit to see if I like having that C41 in there on the cathode clipper tube plate.

## 2020-09-26

Wanting to try an EF86 as the preamp stage. Follow a design from various google.
The thing is, I have 350V going in, so a 10k voltage dropper resistor, that is still 340 ish volts. Which is more than all these designs seem to say 250V.
Probably 250V because that was mains power? The tube seems to be rated for 550V max. so I guess it i ok.
It turns on and doesn't burn up right away. But it is late at night now so I can't evaluate it in all the settings without the attenuator. I swear this attenuator makes fake buzzing sounds on the speaker, so it sounds distorted when really it is not distorted.

Having the ida to wire back the 12AX7 tube, with one element as the original traynor preamp circuit, and the second to be a cold clipper style setup, Where I have a larger cathode resistor. I put in a variable pot, tried it at 20k, 10K.  I am not really a fan of how it sounds. Set the resistance to 2K and will come back to this later.

I put back in the clean / crunch switch, so that I can select between EF86 and 12AX7 preamps. There is a lot more brightness and clarity and gain on the EF86. The plate bypass cap I put on the 12AX7 also helps remove its brightness a bit too. But I am sure the EF86 has more sparkliness to it.

Really happy to have a flexible preamp option.

Put the amp back in its chassis and test it out.

I really do not like the bypass the tone stack switch. I worry that it will cause a higher voltage to reach the op-amp phase inverter, and that will just damage it.
There is not much good tonal gain by not having the tone stack either. It just gets louder. If I had an all tube path, ok, maybe that would be interesting. But I kind of threw out the tube phase inverter feeling the op-amp way is superior.

Take apart the amp and remove that bypass the tone stack switch again. That hole on the bezel is cursed to never get filled I guess.

Put the amp back together. It sound so silent on its own when no sound is coming out. No AC hum from the rectifier diodes bleeding out any more.
Turning the knobs to all the modes. There is a little bit of background hum when I have reverb all the way over. But practically this doesn't sound good and I won't use that.

Only bug I know about is if you turn it off it sort of chirps a couple times. BUt that is not a big deal problem I think.

## 2020-09-25

I have concerns, as I have seen the audio level output from my guitar to be a few volts.

Set up a signal generator and test measure points in the circuit:

* at TP14 V2 (output) of gain stage

Right away I see a bit of 120Hz noise. About 200mv peaks. and the signal oscillates slowly up and down. to have apparent 40 hz.
Ok, what is causing this noise?
Test disconnect the boost converter, pull the op-amp, pull the phase inverter driver tube (amp was oscillating without the op-amp in there)

Still see the noise. Ok, I will have to fix this.

But it looks like when I have an input signal of sine wave, 10mV peak to peeak,
Wait. the usb scope sias the ch2 is 34mvpp. i disagree. Time to get out the Tek scope. I have doubts for the accuracy of this usb hantek scope...

Set up tek scope. When signal generator is set to 25mvPP, i measure 28mmPP. Ok. that is closer at least. Maybe this is very low on the sensitivity for my gear.

Measure TP14 at different amplitudes. Notice I seem to have a gain about 30 with this stage. But not able to make it saturate. I went up to 13v on input, and this was creating 304V to output. Not wanting to burn out my scope, it is rated at 300V on inputs.

Ok, moving on

* at TP17 (output from cathode follower)

I notice this seems to track same voltage, phase, amplitude as TP14. Not surprising I guess, this is what cathode follower is supposed to do.
There is a DC bias of about 150V

* at TP3 (input to cathode follower in reverb)

I connected onto the treble tone knob pin 2 here.

Was able to drive in up to 6v input before this caused the waveform to start to distort.

* at TP25 (input to op-amp phase inverter)

I notice this tracks up pretty high when reverb is off. When reverb is higher it is even higher, like into hundreds of volts. but it must be super high impedance, as the op-amp here loading the circuit, the resulting voltage is about 0.4v when the op-amp is installed.

* at TP23 and TP24 (inputs to driver tube)
* at TP29 and TP30 (inputs to 6L6GC)

I will come back to this.

While set up, I might as well attempt to do a frequency sweep. I have a good load box now, last time I tried this I just had a power resistor.

Had an idea, the noise is likely coming from the power supply, and its poor filtering.
Add a 10K resistor and a 10uF capacitor to the power into V2.
This drops the voltage from 370V to 340V. So the V2 uses about 3mA. or 1.5mA per triode. Yep. That makes sense.

There is now a lot less hum on the speaker. And when I use my scope to probe (after C37) I don't see that 120Hz ripple any more too!!.

Yay for power supply filtering.

## 2020-09-24

Notice the signal wires from the input from the reverb tank to the preamp tube in the reverb circuit. That should also be a shielded wire. Which is also the wire to the chassis for the reverb switch. And finally the wire from the tone stack to the trebble knob.  I now have replaced a few feet of unshielded wire with this RG-178 for the sensitive high ipedance and low signal runs, where noise is likely to be picked up from.  And it seems to have helped. It is a lot less hum than it was before!

Continued learning. Before when I put in the ECC803 as the driver following the op-amp phase inverter, I used

* Rl=220K
* Rk=1K
* Ck=27uF

So. Why these values?  Most likely because I saw some schematic, or used the tube gain calculator. But I did not consider voltages or currents here.  Lets measure stuff.

* The voltage at the plates is 145V.
* The voltage at the cathode is 1V.
* For the 1K cathode bypass resistor, this is 1mA.
* From the voltage drop from B+(370V) to 145V  (225V) over the 220K resistor, also 1mA

Read the [ECC803S datasheet](https://www.jj-electronic.com/images/stories/product/preamplifying_tubes/pdf/ecc803s.pdf). That one is terrible. here [is another one](https://drtube.com/datasheets/ecc803s-jj2005.pdf)

* Nominal voltage is 250V
* A 100K resistor should give a voltage drop of 100V here, and then it should be around 245V.
* Now measure 216V on the plate and 1.45V on the cathode. So about 1.5 mA idle now.
* The max current for these 12AX7 tubes is about 6mA.
* To drive the tube with 5mA, I would likely need a 30K resistor here instead of 100K (a resistor that takes the 370V B+ and drops to 250V, would need 5mA over that resistor).
* I wish I understood how to interpret load line charts to see where we are operating.

I [think](https://robrobinette.com/Drawing_Tube_Load_Lines.htm) having the slightly warmer bias here should help to improve the headroom, by having the operating point more in the middle of the linear ranges. I think having a slightly higher voltage at the plate should help to drive the output tubes a bit harder too.

Investigate, powering the ECC803S from the same supply as what goes into the output transformer.

* Measure this supply to be 400V.
* Va=238V
* Vc=1.58V
* current is about 1.6mA now.
I don't hear any difference in volume.

Actually when I turn the amp out of standby there is an audible "electrical buz noise. Likely as tube is coming up to voltage it creates a few cycles of out of phase signal to the power tubes so we hear the hum.  But we do not hear this when this tube is powered by B+. So put it back for now.

But good to know I can run this tube off the 400V going into the output transformer.

Thinking outloud. The preamp stage will send an audio signal into the op-amp phase inverter. This currently has a gain of 20. The limit of the op-amp is 30Vpp.
The max voltage out of the drive tube will be the gain of this driver stage over 30V.
The 6L6GC tube has a max grid voltage of what the negative bias voltage is, because if it is greater than zero volts, it might enter instability? So this might be about 40V?

But also of interest, the maximum audio frequency input to the phase inverter (output of the reverb stage then), is about 1.5Vpp. And if it is more than this, then we would start to clip at the op amp right. I wonder if this was happening before with the old preamp, where chaining the input stages might cause too much signal to get into the phase inverter.

I guess now with the way it is wired i have the RV2 as the "master volume" to control what gets into the rest of the amp circuit.

## 2020-09-23

I was not really happy with the way the preamp sounds. The original preamp circuit as it was sounds ok. But the crunch mode I put in to feed the two stages together just does not sound good to me. When the gain is turned up it sounds harsh and shrill. And when I use it with the gain lower to get clean tone, I am able to get a bit of that nice "glassy" sound I like. But It also sounds very thin. This is likely because the way I have the first stage wired currently with the 1uF capacitor and 2.7K resistor to bypass the cathode, that Is most likely because it gets more gain after 1KHz.

* Convert the J1, the "lo" input to be a direct connection to input of RV2 (2nd volume knob), that goes directly into V2A (the 12AT7 preamplifier before cathode follower for tone stack.). This will allow me to bypass the preamp circuit all together. RV2 is now a "master volume"
* Wire in the RG-178 cable as the path from output of preamp, through J1, and into RV1. The idea is to have as much shielding from noise as possible in the early stage here. Since we kind of have a bit more signal path length here now.
* Change C34 (cathode bypass cap on V2A for tone stack preamp) from 1uF to 270uF. This is now the same effect as what the first preamp stage used to be. Looking for more gain here, as well as a flatter frequency response.
* Change C4 from 0.02uF,400V to 0.1uF,400V. Looking to have better passsing of all frequencies here.

With this, we are able to completely de-populate V1 (preamp stages.) Completely remove the preamp module and V1 for now.

Going to work on designing a good preamp circuit on a breadboard for a bit.

I noticed before when using the amp, when I turn the reverb mix knob over all the way it causes amp buzzing, like power loss and oscillations.

* Add 68K resistor between the pin 3 of RV7 (reverb mix) and the existing 36K resistor. - I guess I can just make this a 100K resistor. But interested in seeing if this fixes the problem...

That seems to solve the oscillations.

But I notice, when I have the mix knob over on all the way to dry amp, i hear buzzing sound. When I move it all the way wet reverb, i hear a different kind of hum sound.

Disconnect the audio intput to the op-amp plase inverter. It is indeed super silent.

Test jimpering the input from J1 now direct from guitar into the op-amp input. I hear pristine clear sound.

So the part from the phase inverter through power stage is perfect.  The noise is coming some where in the tone stack, reverb.

Connect the guitar into the effct return connector. This bypasses the tone stack and goes straight into the reverb section. Reconnect reverb output to the op-amp phase inverter. Ok. that also sounds really good.

So the buzzy problem is coming from the tone stack?
Replace the 12AT7 with a 12AX7. Ok. In this circuit this seems to work a lot better. No crazy loud hum / buzzing. I wonder if this 12AT7 tube went bad. Will test in my desk audio amp later..

Though this showed me I have a lot less problems without the tone stack. Maybe I should work on replacing this with an op-amp driven EQ as well?
We need V2 in there, that is the only preamp we have with the volume control there.

What if we try to jumper pin 3 (output of cathode follower) of V2, to J9 (effect send). This keeps the valve preamp, but bypasses the tone stack.
No, still hear the hum and buzz. And it still changes when moving the reverb mix knob.

Notice the pin 6 and pin 2 are wired together, but go under the filament supply. Maybe this is just too close to this AC signal and it is picking up the hum from that? This was the original soldering of the socket, I had not changed it all this time.  Disconnect these two pins, wire a wire around them. Also remove the on-socket resistor. Make this be in a wire now. It was also the original 100K resistor. Replace this with a modern metal film resistor.

Leave the 2nd half of V2 disconnected. Jumper a 0.1uf capacitor to pin 6, so it can be connected directly to J9 (output of the tone stack). This bypasses the tone stack all together.
Still wretched hum.
Try swapping V2 with a different tube. Same.
Pull V2 out all together. Ah still lots of hum.
Plug in the effects return. hum goes away. ok something is wrong here.
Finish rewiring the other half of V2. Maybe the floating grid is causing some instabilities here.
Ok, the hum seems to have gone a lot more away.
If I turn the reverb mix all the way over, there is a very faint hum now. But this is likely the lack of quality of signal going to my reverb unit.
But wow, way less hum than I had.  That fucking tube socket wiring was causing a bit of this hum the amp has always had!!.
Any how, no more oscillating or squealing when reverb knobs are turned all ways.
Put back the 12AT7 tube. It seems to work well here.
Continue to add more RG-178 wire along the signal path, from the tone stack components, tube socket to the pots.

At the moment there is entirely no preamp circuit. Guitar into the input works, but is not very loud, even on max volume. This is now like a 500mw bedroom amplifier.
But, I can work on experimenting with preamp designs with the amp not ripped apart, and with the assumption that this amp as it is, is now a clean power amp. At least at lower volumes like i am testing now. That is the tonal character needs to come from the preamp.

From the testing tonight it became clear how I could more effectively bypass the tone stack. By placing a 0.1uF capacitor onto pin 6 of V2 and adding a toggle switch after RV3, before J9 effects send. Go ahead and put that in. Use more RG-179 back to the capacitor on the tube socket.
I don't always want to bypass the tone stack. But at least I can now if I do want to.

## 2020-09-06

While trying to solve an unrelated problem with a bad patch cable I thought the problem was the bug with the missing resistor to ground. Take apart the amp and add an 820K resistor. So that spot on the reverb blend knob is like a fixed gain pot after the reverb recovery tube.

I guess that is it for bugs for now.

## 2020-09-05

* Notice the volume output gets reduced a lot when I have the reverb mix towards the wet reverb signal. I suspect the 50k reverb tone control is attenuating the output from the 12AX7 that recovers the signal from the reverb tank too much. Also this tone knob does not seem to do anything to the tone, except cause undesired oscillations somtimes when it is all the way over. Try to replace the reverb tone stack with a single 1M pot to ground, like the output pot on the gain stages.
* Taking it out all the way does help. But I find I can't turn it up all the way, I get distorted sound. From experimentation find that about 36K is a good resistor to use. This lets me completely remove the pot. That works. I only need dwell and mix.

Happy. This fixed the duck in volume when the reverb was on all the way, and the random oscillations on high gain settings when reverb tone knob was in some not ideal position.

Dammit. Just get it together and notice when the reverb blend is maximum it makes farting oscillations. I guess I need a resistance to ground coming out of the reverb recovery stage to drop the level a bit.  So a new bug to fix next time I take it apart.

## 2020-09-04

* Change the feedback resistor (R28 from 82K to 200K). Before it had helped things when this was lower. But now with the op-amp phase inverter I guess the feedback is different. I felt tha amp was not loud enough, or it lacked in detail and articulation a bit.  I first tried to add in a resonance control, make this a 1M pot. But I found that it does not really make a noticable change in sound. And that 150K is the lowest we can go before it starts to do oscillations at high gain settings.
* Attempted to add a presence control to feedback path. But this caused high pitch oscillations. Undo.
* Change phase inverter op amp feedback resistor (R69) to 20K. I don't know why I had 18K. I think I experimented to find this was about right setting on the gain knob. But I have 20K resisters everywhere else there right. So try it to see if it still works. It does.  This stage now has a gain of 20 instead of 18.

Setting the feedback resistor seemed to help stop the squeal at high gain settings. I need to play more with the settings and see, but it does feel a lot better now.

* Remove the S1 (clean / crunch switch) from the signal path. I basically like having two tube gain stages in series all the time. So I now have 2 volume knobs all the time as well.
* Investigate using the crunch swith to engage some [clipping diodes](https://warpedmusician.wordpress.com/2014/01/23/adding-diodes-to-tube-amps/) after the first gain stage then. I tried them on their own and it was ok. But I don't like how it sounds with my usual guitar sound setup. It almost sounds like a fuzz pedal. Not my thing. Remove the diodes. Something to revisit some other time with something else. At least we tried.
* Delete R62 and R63 (360K between output of  gain stage and volume pots ). This was attempt to stop that whacky oscillations at high gain settings.
* Not entirely happy without that S1 (clean/crunch) switch to allow me to use one preamp stage like it originally was. Or both in series. I feel sometimes the single stage is warmer and has better bass response.  So. undo taking that out.

Kind of a day where I try things and then undo them. I guess a small bit of tidy ups from previous hacking attempts.

For now the amp is really good at clean channel sounds.

## 2020-08-30

Realize I did not put in cathode bypass capacitors to the tube gain stage following the op-amp phase inverter. I don't need these, but any bit more gain that is possible is a good thing I think.  Take apart the amp quickly and put them in and then put the amp back together.

## 2020-08-29

It felt like the reverb signal was still clipping too often. I hear crunchy or distorted sounds coming out when I want clean tone. I think it is the super overdriven reberb signal.
Add a 0.02uF capacitor and a 4.7K resistor in series to the input to the 12AT7 of the reverb drive circuit.
This seems to help it a bit.

Take a look at the reverb tank input signal on the Hantek scope. Observer there is no clipping there under various level settings.

I am now super excited about how this amplifier sounds.
Words to describe it include articulate, superb clarity, excellent responsiveness. It is picking up nuances of my fingers or picking I have not heard before. So now I need to work on improving my playing abilities to make use of these new features.

Put the amp back together into its case.

## 2020-08-28

* Install female IEC power connector after the switch, so I can plug in my pedal board to the amp and have it controlled by the amp power switch. One less stupid cord on the floor now.
* Remove the variable resistor I had in series with power tube screens. It was not doing anything.
* Remove the variable resistors I had to the power tube grids to attempt to bias them. They do not do anything.
* Remove the high voltage test points. Repurpose 2 of the jacks as sensors for the grid to the power tubes, so we can analyze the phase inverter output.
* Try to put in 6L6GC tubes, instead of the 7027A ones that I had in there. Yep, they seem to work Ok. I am interested to see if the slightly lower power ratings of the 6L6GC help them to enter break up a bit easier.

Maybe it was the cleaning up the wiring and the adjustment pots that did nothing, but it feels a bit less buzzy now again!

Have the idea to try to build a solid state phase inverter using op-amp. This will require a +/- DC power supply. Have the idea I can use the small DC-DC converter I have with a bridge rectifier and filter cap to get this from one of the tube filament supplies.

Assemble a small module board that is this op-amp DC power supply from tube filament. It seems to work as expected.
Use a signal generator of 1kHz and 5Vpp I am able to see the output waveform using the Hantek USB oscilloscope, and it is indeed inverted phase and the same amplitude. Experimentally I am able to drive this up to the power supply rails. I find that a 25K pot is enough to make the 5V signal not quite clip. The Traynor YBA-300 schematic used a 100K pot. Then again that was likely line audio level. I will have to measure this again when I get it into the amplifier.

Here I am using the OPA2134 op-amp. I believe it can provide enough current that I do not need to use a tube to buffer it to the power tubes. I guess we will need to try it to see. I added a 1K resistor in series with the outputs.

Trying to measure the waveform from the existing phase inverter on the Hantek scope. I find when I use capacitors on the same breadboard as the test op amp, the parasitic coupling is enough I hear the 1kHz test signal in the amp. Neat. And because I am tapping into the power tubes, I can basically drive output out of the amp independently of the volume controls. Try a separate bradboard. I need to use capacitors on the end of the probes because the Hantek apparently does not have an AC coupling option. And the amplifier has a -40VDC bias on these connections from its phase splitter into the power tubes, so i need to use funky scale on the screen to see the scope trace.
But having a hard time to see a good signal. I can see one half of the guitar signal, but not the other half. It is almost a flat trace. It might be the power tubes are loading it too much to see it?  Try pulling the power tubes and measuring again.
Still only seeing the signal going into V5 (2nd power tube), not V4 (1st power tube). Check the wiring in the amp.
Check the connection. Use a probe on the signal generator on pin 6 of V4 (output from phase inverter tube) and see the signal is getting to the pin5 of V4.
Odd. It must be the tube is loading the circuit so I can't even measure a voltage change?
I am having a hard time getting a good signal. But when I turn up the tremolo I can see two sine waves of different amplitude and not shifted 180 deggrees at all. This is consistent with what I hear with my hears, the terrible buzzing problem. I have no interest in trying to investigate or adjust this long tail pair circuit.
I have a feeling some of the squealing and oscillations I am having are due to the stray capacitance and resistor networks in this tube phase inverter schematic.

Try to connect my op amp phase inverter by wiring the output from the reverb to the input to the op amp circuit on breadboard. Then wire outputs to the plug connectors. Disconnect the pin 5's from the old phase inverter that was going to power tube.
I don't like having wires coming out of the chassis, but this op amp circuit is still on a breadboard. And it is all audio level signals here.

It works!. Getting distortion at high gain, but this is because of likely not having the feedback connected. Lets test connect the feedback resistor.
It seems to be ok with feedback resistor in place. Doesn't not work anyway.
Put the tremolo oscillator tube back in. Tremolo seems to work ok too. And not having the terrible background buzz. There is a tiny bit of course. but this is normal.

I have nice sound. I can see the phase and inverter phase things happening on the scope when I connect to the output from the op-amp. The audio signal is perfetly out of phase and same amplitude. There is a bit of random buzzing noise. But I think this is just noise in my room and computer and lights and test equipment. The long unshielded wires that carry the audio signal are coming out of the amp. They probably work like antennas to pick this noise up.

The only issue is now with just the op-amp phase inverter the amp feels "too quiet". Maybe we do need to have a tube buffer then?
Since we are this far into it, lets try to repurpose the old phase inverter tube for a driver buffer tube.  Remove the phase inverter module board I had in there before. So I can always undo this later if I need to. Rewire the phase inverter tube socket to be a pair of triode preamp. I again borrowed the values from the Traynor YBA-300 schematic. Here I think the setup is for a gain of at least 50. So moderate gain.

Discover the gain knob is not really useful or needed. I found through experimentation having it at 25K causes random oscillation effects. But keeping it around 18K at the most seems to be pretty stable and good enough volume. So replace the pot with a 18K resistor. I assembled the phase inverter module all with screw terminals as the reverb module. That is such a convenient and good idea. So i just stuff a resistor into the screw terminals that were to go to the pot.

Mount the power supply board into the chassis. At first I had a short circuit on the DC+ output from the diode rectifier. This is because I put the parts too close to teh edge of the board, did not consider standoff space. And I dumbly put the positive voltage pin in the corner. I should have put the ground around the perimiter of the board. Always something to learn. I just removed the one standoff. The board will be fine with three. The power transformer is a beast. It kept putting out about 4V when it was loaded up from a shorted out rectifier diode. The diode bridge got pretty hot. But i heard it making crackle sound and smelled it before i left it on very long. I think it is going to be ok anyway.

* Replace the 12AT7 in the phase inverter section for the ECC803S it was before. Now that I have the op-amp phase inverter I can benefit from having the slightly more gain in the output into the power tubes.

Test the amplifier now. It is whisper quiet. That buzzing and clicking I had intermittantly when it was on the breadboard is now gone. I figured it was just the wires working like antenna to pick up noise from the room.

This amplifier is now almost as quiet as my YBA-300 amplifier. And I have the same satisfaction I have when I fixed that amp. Really the phase inverter was likely problematic forever here. Replacing this is the biggest improvement to this amp so far.

And now I have a good size DC power supply in this amp to power op-amps. I can tinker to add other op-amp based circuits. Like active EQ. Though I am running very low on space. Stuff is going to have to start coming out before we can put any more in.

I am considering the work and changes for this amp to be complete for now. Though I am going to leave it apart this weekend, in case there is any tinkering ideas. Because lately every time I put it back together it is not even a day and I am ripping it apart again.

## 2020-08-26

* Try adding a 68K resistor in series between (output of reverb) and input to phase splitter. Trying to get rid of higher gain squeal problems. That seems to actually help a bit. But I just can't use the reverb tone knob at all. Might remove it later then.
  * Having this resistor in seems to make the amp sound like there is a blanket over it. Not liking it. Remove it.
* Try adding grid bias adjust resistors to inputs of V4 and V5, the [two bias adjustments configuration](https://www.apexmatching.com/why-should-i-match-my-tubes-technicians-explanation). This also will require us to put test plugs up on the HT wire. The things we do for science. Measure the resistance and then the voltage drop through the transformer to infer current.
  * This seems to be bad for this amp. It runs the tubes about twice as hot (you can tell by the smell too). And the tremolo circuit seems to bust. Undo the ground connection on the new bias resistors, so they are still in there in series with the 220K resistors, but I don't think they are doing anything. I might remove these pots later then sometime.
* Experiment with adding a 500K pot in the feedback loop from the output. It sounds a bit louder and crunchier when this resistor is larger. But I also like how nice it sounds when this value is low. I tried making the feedback small, 68K, and that even sounds good. So put it back to 82K and remove the pot. (R28 used to be 100K)
* Try to remove the reverb tone knob. Nope. It squeals more. The oscillations are somehow controlled when I adjust the tone stack. So maybe the feedback needs to go earlier into the amp stages.
* Experiment to add a 100K resistor in parallel with C38 (connecting to the reverb mix knob). It seems to help a bit. or do nothing. Which ever.

So a couple things that did not make a difference. But I guess this is how we learn too.

I hear when testing, it is possible to overdrive the reverb, and I am hearing a bit crunch from the reverb in clean tone. That is a neat effect.

* Try to swap out the phase inverter (which was ECC803) to a 12AT7. Lower gain to the power tubes. Trying to see if this removes squaling problem. It does not. but it seems to still sound ok.

## 2020-08-22

* Swap out the 12AX7 in V2 (tone stack buffers) for a 12AT7. I can't tell entirely if it is helping remove some of that squeal oscillations. But it doesn't not work and seems to sound ok. So going to try leaving it in there for a bit. I did have a JJ ECC83 tube in there before.
* Swap out the Sovtek 12AX7 in V1 (preamp) for the JJ ECC83 I took out from V2. That seems to again improve the sound character and reduce the squaling.

## 2020-08-20

Assemble the discrete RC components on the circuit board and where it makes sense on the chassis.
Using screw terminal connectors to interface between the board and the chassis. Update the schematic with these connectors.

Use a multimeter to probe the circuit and verify things are connected to where they are supposed to be.

Wanting to test the components rather than hooking it all up at once. Added 34 test points to the schematic. Can work on measuring and documenting voltages and observing and learning wave forms. Some are high voltage so need to be super careful.

* Test 1: Populate just the V8 tube of reverb unit. Hook up the audio from the FX return through V8A, through RV7 to power stage. Populate just V8 12AX7 tube. Expecting the amp continues to work and produce sound.
  * Ok. I do hear amp audio. When I turn up the level for reverb I do hear high frequency oscillating though. Pretty sure I should not. Notice when things warm up the squealing goes away.

* Test 2: Still with only the V8 tube populated, hook up a signal to the reverb tank return connection. Expecting to be able to hear that on the output.
  * Ok. Plugged guitar into the reverb tank return. Able to hear it and control its volume level with the reverb mix potentiometer.

* Test 3: Populate all tubes. Connect a speaker instead of the reverb tank. Expecting to hear the sound from the reverb circuit output.
  * Ok. I hear audio coming out! It is not overly loud or overly distorted. But I hear it. Kind of tinny. But it is there.

* Test 4: Connect the reverb tank. Expecting to have reverb effect work.
  * Ok. I hear sweet reverb sounds. Nice!

Mount the reverb tank. Put the amp back together.

While putting the kids to bed. Have the thought. Hm. Maybe the T3 reverb drive transformer should be connected directly to V2, instead of following the 4.7K resistor, so it operates V9 at a slightly higher voltage. And then the R54 (4.7K screen resistor) should also go to V2.  Dammit. How come I didn't realize that before. Update the schematic. Take apart the amp. Move (1) small wire a little bit over on my reverb driver circuit board. Test it. Ok. yea. There is a lot more reverb now! That is better.  Put the amp back together again.

Making small RCA patch cords to connect reverb tank to the amp chassis in the case. This is meaningful for me since I am using what is left of a RCA patch cord that I used to connect the Apple IIc computer to the television when I was a kid. I started to use it as shielded wire when working on guitars. So more personal history put into this amplifier.

## 2020-08-18

Digikey parts and NextGen Guitar tube sockets arrived today!

Rough in the parts on the chassis for the reverb circuit.

* Install V9 (EL84 in reverb circuit) tube socket.
* Move the fuze over closer to the power switch. The back panel now has more room to put potentiometers.
* Cut out a rectangle of sheet metal and screw it over the hole where one of the chassis can capacitors used to be.
* Install the RCA jacks to connect amp to the reverb tank on this new sheet metal plate.
* Mount J6 (reverb footswitch jack) into the hole where the power switch used to be.
* Mount the 3 reverb control potentiometers into the (old fuze hole, a new hole, old ground switch hole)
* Print label maker labels for the new knobs and connectors.
* Dry fit a small circuit board on standoffs to be used for the discrete components.
* Connect the driver transformer to the connector and to the tube socket.

## 2020-08-17

* Install tube sockets for the 12AX7 and 12AT7 tubes for the reverb circuit onto the chasis. Wire up the fillaments.
* The tremolo was "too fast". The slowest setting was about all I could use, but still too fast. Change C18 and C19 from 0.01uF to 0.02uF. It is a much usable range of speeds now.
* Change C8 (input to phase splitter from tone stack) from 0.02uF to 0.047uF. I think its a bit more "bassier" now.
* Experiment with a 500K pot instead of the fixed 100K resistor. Find the variability of the pot does not effect the sound as much. But having this value larger allows the sound to break up easier for sure. Change R8 from 100k to 220K.
* Update schematic. R24 and R25 are actually 100K trim pots in series with the resistors, I put in to get exactly 84K and 100K values.

Trying to reduce the oscillations I am getting when turning the gain knobs all the way up.

* Add 1K grid stop in series to input of 2nd stage preamp.
* Install a 360K in series with 1st and 2nd channel gain knobs. This seems to be the min resistance on the pot to prevent squealing when the pots are turned up more of the way. This didn't help.
* Try to install 0.001uF capacitors in parallel with the plate resistors on the preamp stages and cathode follow 100k B+ resistors.
* Swap the wires from the tubes to the output transformer (changing phase might change feedback properties?) That made it horribly worse. Put them back. And fix that scrap of solid conductor wire that was hacked onto the wire to be a tube socket lead.

I still get high pitch squeal when the gain knobs are turned most of the way up. Some kind of stray capacitance with my sloppy wires probably. But I think it is a bit better. It does not have that cut power and do a sort of hum effect, which was likely from very high frequency inaudible oscillations.
Ill leave this for now. Practically I won't crank out the gain knobs anyway right.

## 2020-08-15

Take apart the amp. Create a full updated schematic.

* fix the output transformer mounting. The bracket was bent since I got it so the transformer was kind of angled in how it was sitting. Loosten the bolt and bend the bracket. It sits flat now.
* Remove the old capacitors that were on the chassis. Wanting to make some space for the parts for the reverb circuit I am planning to add.
* Remove the switch to bypass the tone stack. It doesn't really work well or do much for me.
* Put in a separate cathode resistor and cap for the first crunch stage. I went with 2.7k and 1uF.
* That tube socket I replaced before is cheap Chinese crap. The bracket does not hold the socket very well. Find the nextgen.ca site has tube sockets. Get a bunch of these. I will need some 9 pin ones to mount the EL84 to drive the transformer to the reverb tank. I will replace the 7027 8 pin socket too when these come in. Feeling frustrated I didn't look at nextgen.ca before, that I found amplified parts.com in the US, where the cost after currency exchange, shipping, and duty, will be more than what it would have been to buy from canadian store. Also, the month or more it took to arrive. So pissed off and not going to buy stuff from US vendors any more.
* Update symbols on schematic to be more recent tube symbols.
* Update actual schematic to use part numbers of original schematic where possible.
* Draw schematic for reverb driver

* Test power transformer to see if it can power fillaments of 3 tubes (12at7, 12ax7, el84) for reverb driver circuit.
  * Wiring these 3 tubes up to my power supply, they draw 1.5A at 6.3V
  * It looks like the modern part number for the 78633 power transformer is the Hammond 291JX. This seems to be rated at 2.5A for the fillament supply.
  * There are currently 4x 12AX7 tubes. Each one of these seems to draw 0.17A each. A 7027 tube draws 0.93A each.
    So, (0.97*2) + (0.17*4) = 2.62A. That is already more than what this (modern) part is rated to supply.
    I would need this transformer to supply 4.5A fillaments. I think the new replacement part is not the correct one for this.
    Experimentally test jumpering the 3 tube fillaments to the power transformer. It seems able to turn them all on and able to make sound, not browning out. Not buzzing badly. Looking on digikey. Most similar transformers are rated at 3.5A
    I can't find a spec for this transformer. It is probably over sized for this application.
    I figure I can try to use it, and if I burn it out, it looks like [this](https://www.digikey.ca/en/products/detail/hammond-manufacturing/270FX/455411?s=N4IgTCBcDa4OwAYBiANEBdAvkA) is a repacement that is rated at 5A fillament.
* Add 1M grid stopper resistors to the inputs of V1A and V1B. Before these were on the input jack side of the 68K resistors. I feel these should be right up as close to the tube as possible. Also, because we now can switch which preamp stage the input is connected to, we now require a separate grid stopper resistor per tube.
* Change out the two 100 ohm screen current adjustment resistors. Notice on the schematic how the V+ kind of Tees into the middle of the two resistors. In practise I seem to have one of these all the way zero'd out and the other one about a third to mid way. So if I just have the wiper connected to V+ and one leg of the pot to each fixed resistor, Then I can achieve the same effect but with one knob. The pot is rated at 2 watts. I only use about 1 watt here, per tube, so this should be ok. If it breaks we can always put it back how it was before without the adjustment pot. I am not entirely convinced this makes an audible difference. Just having the same screen currents into the tubes allows the tubes to wear about the same, not having a slightly hotter tube.
* Compute a list of parts I need to build the reverb tank driver circuit, send off a DigiKey order.

## 2020-04-??

* Convert two input channels to a single input channel
* Use the second pair of inputs as an effects loop
* Add a toggle switch to allow us to cascade input stages in series if we want to
* Add toggle switch to allow to bypass tone stack
* Move the AC switch to the corner out of the way.

I know I took pictures. I can't find them now.

## 2019-03-11

Take apart the amp.

* Remove the trebble cap in parallel with the 220k resistor from the output of the first stage. I found it was just way too bright.
* Experiment with using a larger resistor, and a variable resistor for the cathode bypass resistor on the second stage. It didn't seem to make much of a difference, so take it out. End up leaving in the 820 ohm resistor i was playing with, instead of the 1.6k resistor for the second stage. It has the effect of moving up the frequency vs amplification curve a bit. So the amp continues to have a bright sound to it.
* Experiment with removing the resistors between the amp stages all together. This caused high frequency squealing, oscillation Put them back in. Really having these in here is a voltage divider, which halves the output from the first stage, which is likely why we can't get a strong overdrive with this.
* Put back the original preamp tube. I didn't like the hiss noise I was getting. it is silent again. Now I just can't crank the first gain up all the way.
* Notice the schematic for the ax84 preamp mod had the units of the tube backwards. It was not as I had built it, so it was confusing to read the schematic. Fixed.

Continue to be happy with the tonal variations I can get in clean tones with this amp.

## 2019-02-28

I changed out the preamp tube with one I had in my electronic junk bin. This one has slightly shorter plates. For what ever magic ass reason this other tube does not have the high frequency oscillations. I notice a bit more hiss and background noise like hum and crackles when the first gain is higher. I think perhaps trying different preamp tubes. I have some coming in from aliexpress. So wait and see. Maybe some good expensive ass one from tubedepot if that doesn't help. I hate the shipping though.

Changed out the 7027 tubes for a new set I ordered from tubedepot before. The new ones are a bit taller. So i can't have it mounted on my desk out of its case anymore I guess.

The new tubes are super shiny. And seem to operate not quite as hot as the old ones. I don't have any setup to check or adjust their bias. But they sound ok. And subjectively they both seem to get the same amount of hot, so not having one loaded harder anyway. Probably.

Decide the sound of the amp is good enough. It works. It plays very brightly. Sounds good for both guitar and bass guitar. Really to improve it more I would need some better speakers. I just have shitty old home stereo system "house party" speakers. Good enough for making noise when people don't care, but not a good speaker at all. When I can stop tinkering with the electronics in the amp I can focus on practicing to make music more too.

Put it back together in its chassis for now. Clear off a spot on a table for its new home.

working again

## 2019-02-27

DigiKey parts came. Happiness!

Assemble the preamp module
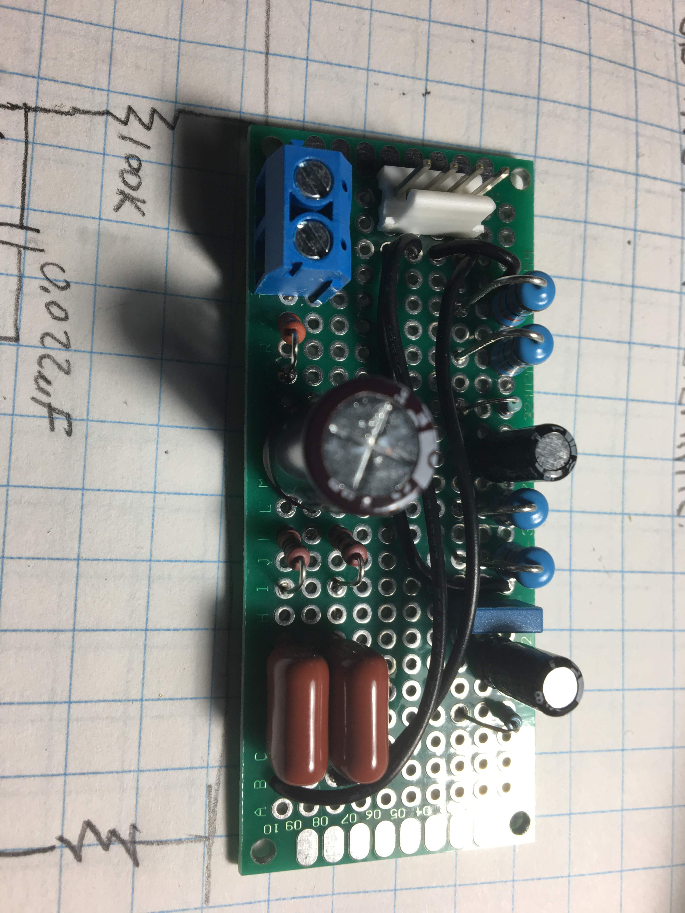
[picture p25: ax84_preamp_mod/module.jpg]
ax84 preamp module


Get it wired in nicely. Try it out a little bit (but it was after kids in bed so not very loud or long).
I just plugged the guitar directly into it.
It is a lot tinnier sounding, less whole bass sounding it was before. But I have a lot of variation with the tone controls on the amp and on the guitar.

I was able to get some crunchy overdrive sounds. I noticed the volume pot is a little scratchy. And there is a weird spot where it seems to be some kind of resonant spot. You hear it sort of cut out and very high pitch hiss.  I have theory this is because the pots are 4M and not the 500K the schematic called for. I just used the ones that were on the chassis, but maybe I should have replaced them. Something to add to the next digikey order. In the mean time I will try to play with this a bit and see if I can find some good settings from it.

## 2019-02-26

Have the idea to replace the preamp circuit with one based on the [AX84 High Occtane](http://www.ax84.com/hioctane.html) amp.

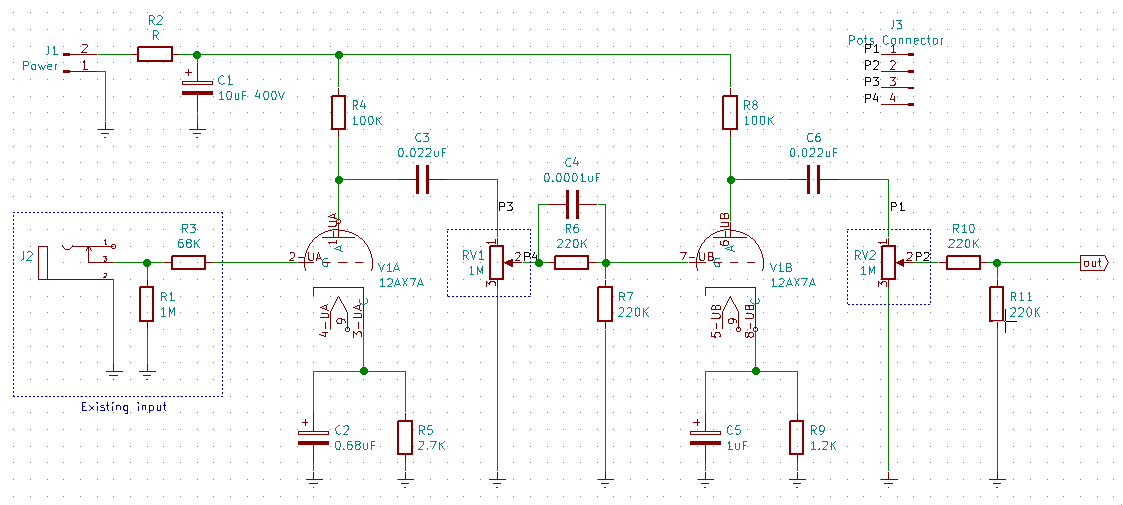
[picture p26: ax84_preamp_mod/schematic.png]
preamp mod schematic


Here I am just replacing the preamp part, up to the cathode follower before the tone stack.

It will

* Replace the preamp module board.
* Remove the channel II input.
* Add a 1 uF capacitor to the cathode of the tone stack cathode follower.
* The 0.68uF capacitor on the first stage of the preamp
* The 1 uF capacitor onthe second stage.

We will lose the two separate input channels. But I don't need thse anyway. The second channel becomes the second stage in this new single channel. The existing volume knob on the front of the chassis is thus used. We will have holes where the channel II inputs used to be.

The attempt to use a connector on the preamp module before to connect to the tube does not work.

* This did not consider the separate wire for each cathode. Before both cathodes shared a single resistor and bypass capacitor. But these now are differnt.
* It did not consider the second grid input, which used to be directly wired to the input jack.

No matter. Removing and replacing the module is still the order of changing 6 wires. If we ever decide this mod is not useful and wanted to go back to the original configuration we can just rewire up the old preamp module.

I need to 16 resistors and capacitors. Of course I do not have all of these. Place a DigiKey order.

I think this will have a higher amplification for higher frequencies, providing a treble boost type of effect.
Based on the [cathode bypass calculator](https://www.ampbooks.com/mobile/amplifier-calculators/cathode-capacitor/calculator/)
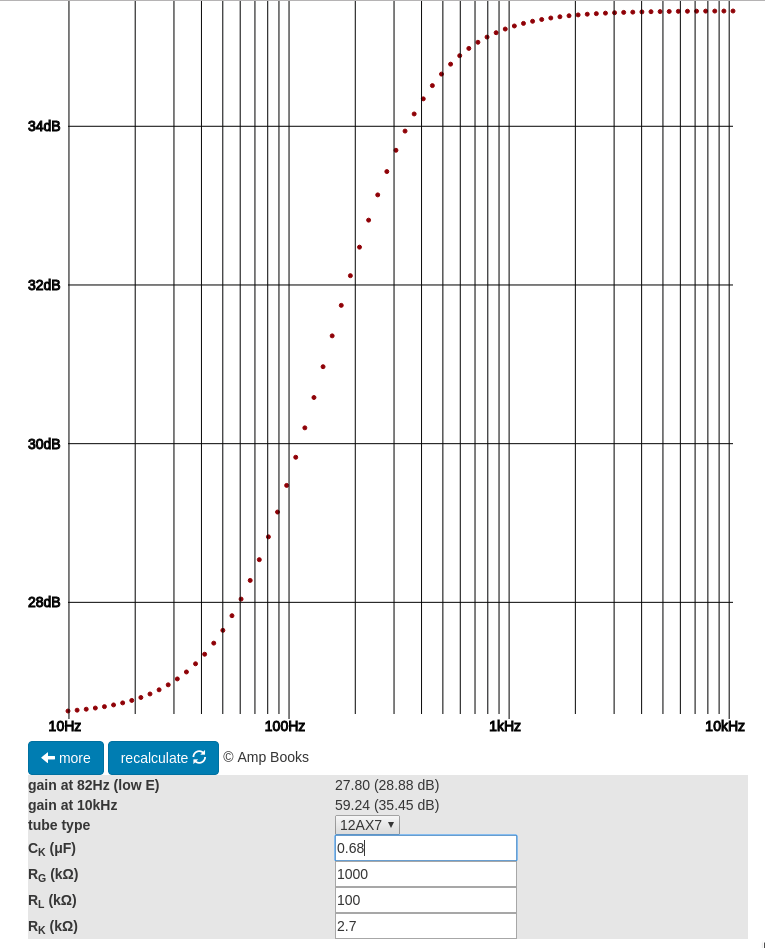
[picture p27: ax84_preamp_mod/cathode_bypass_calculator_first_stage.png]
first stage amplification vs frequency


The second stage has a similar curve, with the (1uF,1.2K) cathode bypass, but with a 83Hz gain of 36 instead of 27.

I believe this is why it sounded bad before when I experimented connecting the first stage of the two channels together in series. The configuration of the Traynor preamp is pretty flat amplification over all frequencies.

traynor preamp stage

So boosting the low frequencies as much as the highs makes everything sound just buzzy and muddy.  Some [youtubing](https://www.youtube.com/watch?v=wkhmDEKeaBU) I have done lately seems agree that a trebble boost is preferred for good overdrive sounds.

Unwire the old preamp module and install new wires to the tube socket to be ready to assemble the parts when they come in.

## 2019-02-22

* The power supply boards arrived from OSHPark in the mail today. Assemble the components onto a board and install the board into the chassis. Remove the rest of the old ladder circuit.
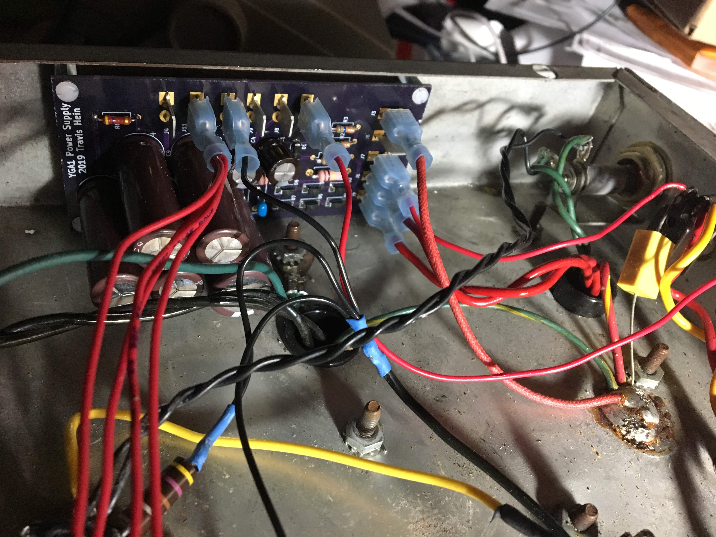
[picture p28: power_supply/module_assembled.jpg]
assembled power supply
 

There was a problem where I drew the schematic wrong. The polarity of the 8 uF capacitors was wrong. I put them in the correct way. Fixed the schematic.

I realize as assembling it some of the connection points did not take into account the chassis wired things.

* The second pole of the switch goes straight to the inductor and the centre tap of the output transformer.  The 400V out is also just off the return wire from the choke. So there are three spade connectors not populated here.
* The resistors to the output tubes should have been included on this circuit board.
* There should be more connectors for the 340V outputs. As there are four wires, one to each of the tube modules.

Update the schematic with these changes for next time

This is now all of the original circuit and components. We have modules for everything now.

## 2019-02-13

* Removed the "death capacitor". That 0.05uF capacitor between the mains hot and neutural. Left the switch in the chassis disconnected for now. Watched a bunch of Uncle Doug Youtube channel. He explained a bit that these capacitor and ground select switch are an artifact from before there were three wire ground wires. And I already have good low buzzing sound from the ground chassis.
* Change the configuration of the hot wire to go through the fuze, then to the switch. Instead of the fuze attached to the neutural.
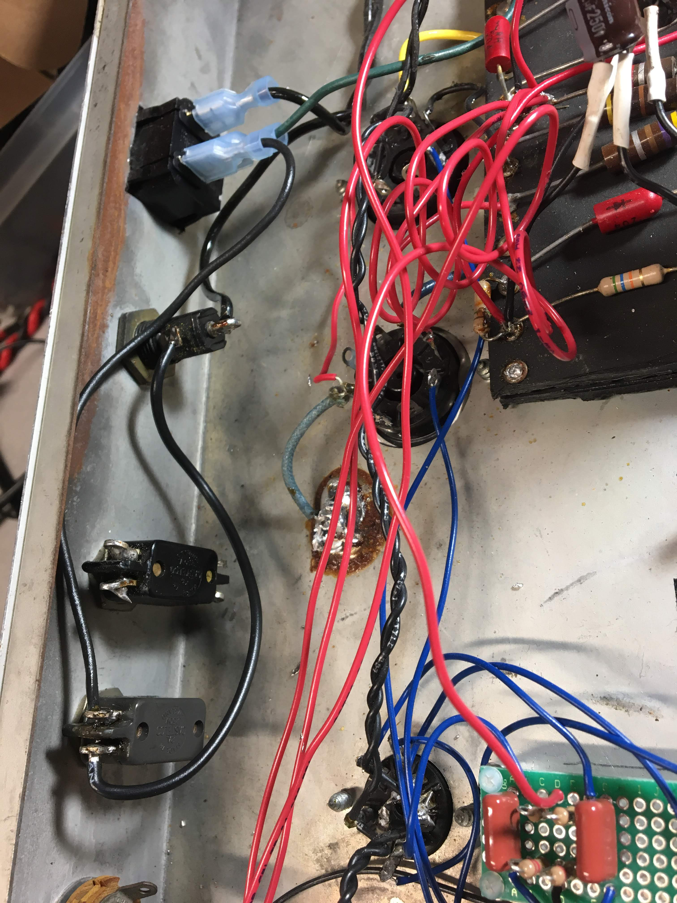
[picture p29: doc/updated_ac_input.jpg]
ac wiring harness
 
  Using the spade connectors on the IEC connector. The ground wire now goes to a round eyelet connector on a bolt with lock washer, instead of soldered to the chassis. The AC input now feels a lot less whacky to me.
* Updated the schematic for input module.
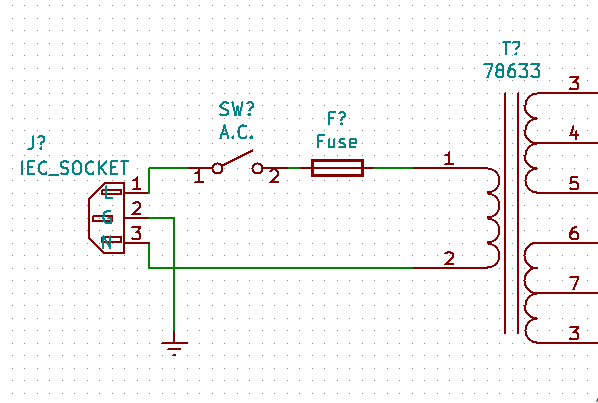
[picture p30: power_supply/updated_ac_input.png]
updated ac input
  
  I started a schematic to have all the parts on one sheet like the original schematic.
* Put some connectors onto the preamp module. Before it was just hard wired in.
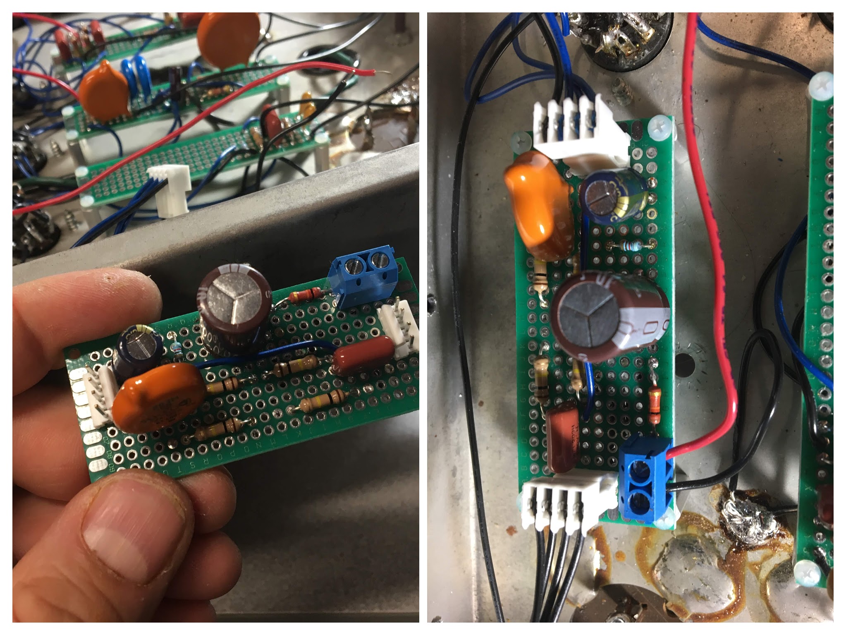
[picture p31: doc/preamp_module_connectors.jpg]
preamp module connectors
 
 This will allow me to experiement with different configurations of input preamps. I have some ideas to use both halves of the first 12AX7A tube in series to get overdrive sounds. But not wrecking the original configuration (allowing me to change it out for testing and put it back).

## 2019-02-07

* Replace the output stage with new components and a module.
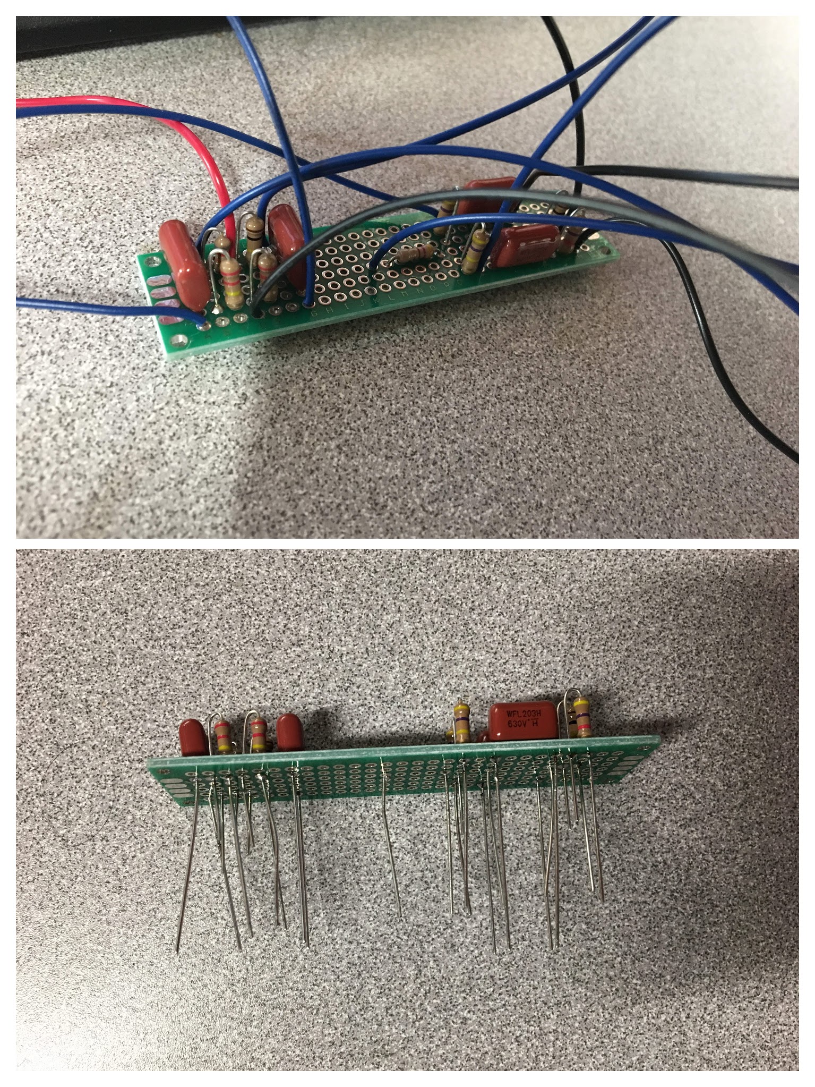
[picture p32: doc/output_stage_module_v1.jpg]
output stage module
  
  The only thing left now is the power supply. still waiting for the circuit board to come in from OSHPark.
* Replace the broken 7027 8 pin tube socket with the new one I orded from tubedepot.com.
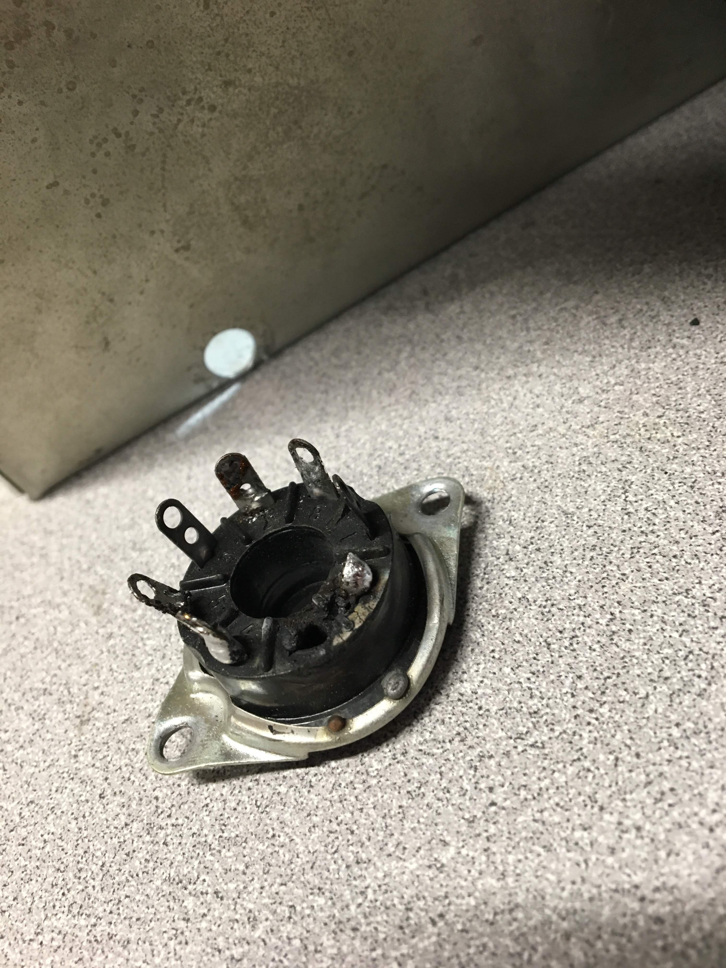
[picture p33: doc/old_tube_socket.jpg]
old tube socket
  

## 2019-02-06

* Build the tremolo circuit onto its own module board. New components of same values. Remove the old components and ladder board to make space.
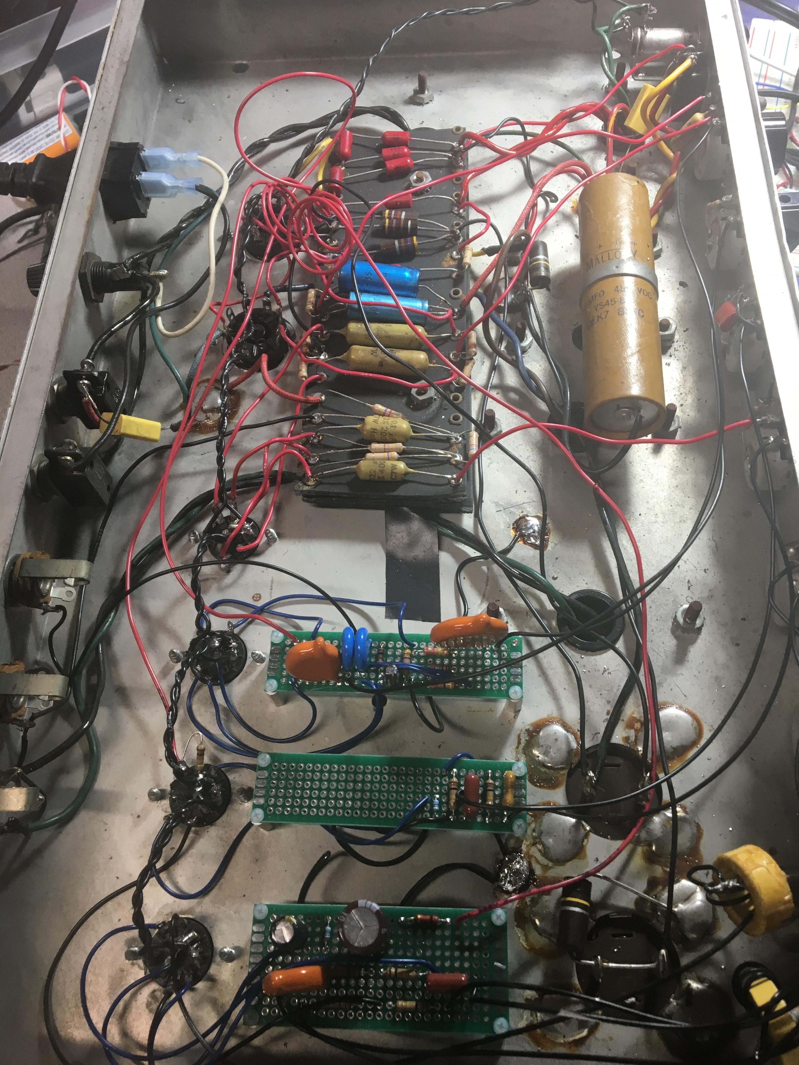
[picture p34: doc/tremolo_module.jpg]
tremolo module
  
  It is the third from the right (or the left most) green circuit board.

* Parts from TubeDepot arrived today. Had to pay stupid duty at the door. Something to remember. Have new tube sockets to put in sometime. And a new chicken foot knob.
* Install the chicken foot knob. Remove the round knob I had used since i got it as a place holder. Now all knobs are chicken feet. It is a little bit smaller but still of the theme I guess. i knew I should have ordered all new knobs to have them look the same!

## 2019-02-05

* Second order of parts arrived from DigiKey.
* Replace the 0.02uF ceramic capacitor on CH2 with the 0.02uF metal film capacitor. Leave CH1 as ceramic one for now. Wanting to see if I can notice any difference.
* Discover volume knobs are not lined up. The chicken foot handle is not the same orientation on CH1 as CH2. Adjust. I was thinking CH1 had more gain because it shows volume at 0-1 where CH2 needed 1-2.
* I do notice CH2 is still a bit scratchy when changing cables. Likely oxide or dirt on the connectors in the jack.
* Try to clean the input jacks with Q tips and alcohol.
* Notice the chicken foot knobs are super crusty too. Take them all off and clean around them with Q tip and alcohol.
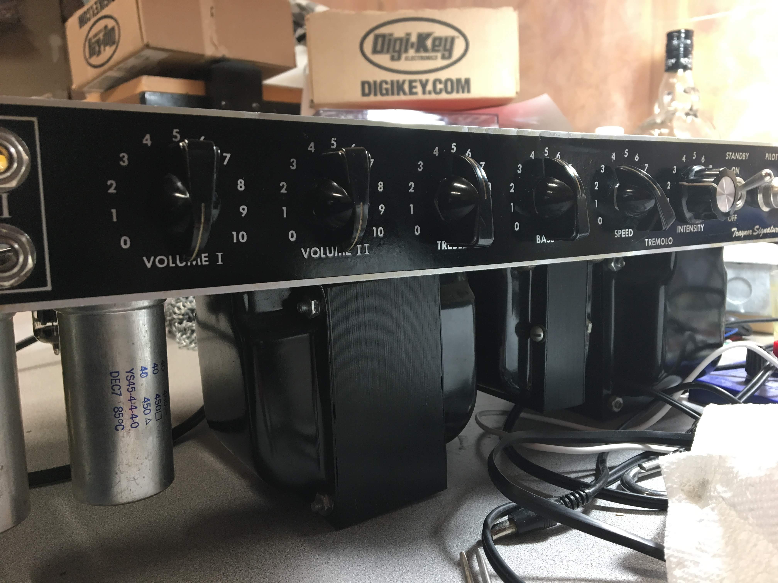
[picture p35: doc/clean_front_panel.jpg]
clean front panel
  
* The cleaning made the treble knob super hard to turn. Like the alcohol got in there I guess and made it sticky. Use a tiny bit of WD-40 on the shaft. Good to go again.
* Replace the ceramic cap I previously put onto the bass knob with a metal film cap. Also replace the resistors now that I have the parts.
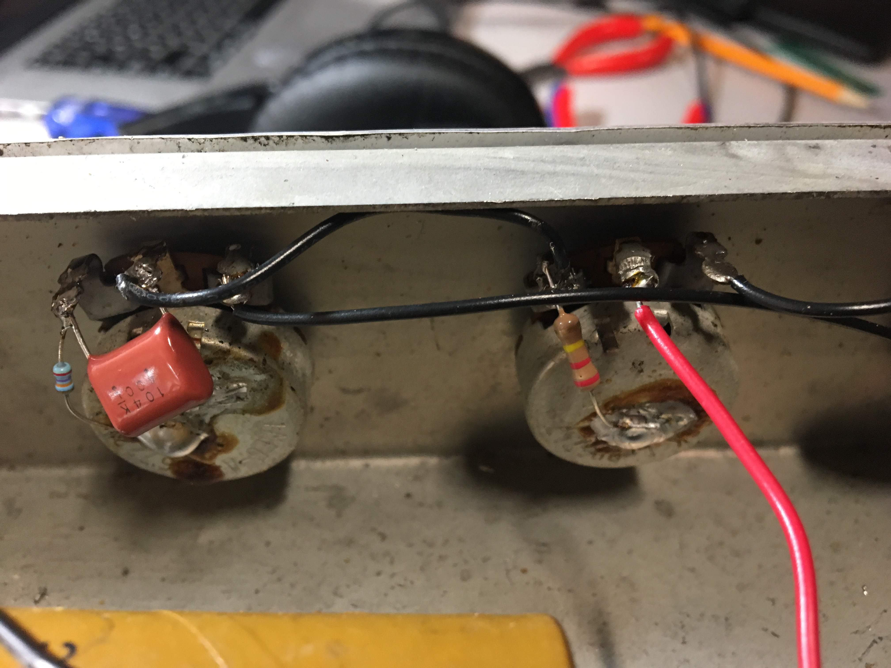
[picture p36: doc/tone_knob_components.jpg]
tone knobs
  
* Build the tone control components onto a circuit board.
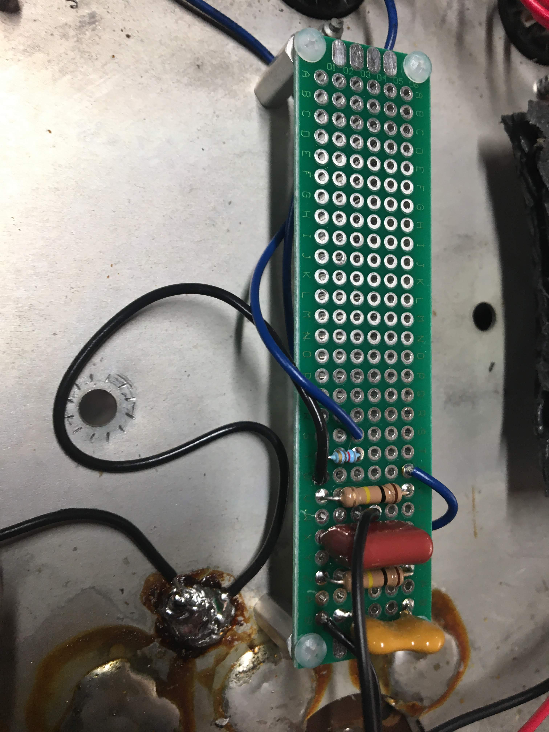
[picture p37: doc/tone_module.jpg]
tone control module
  
* Now we are at the point of needing to remove some of the original ladder board to make room to mount this.
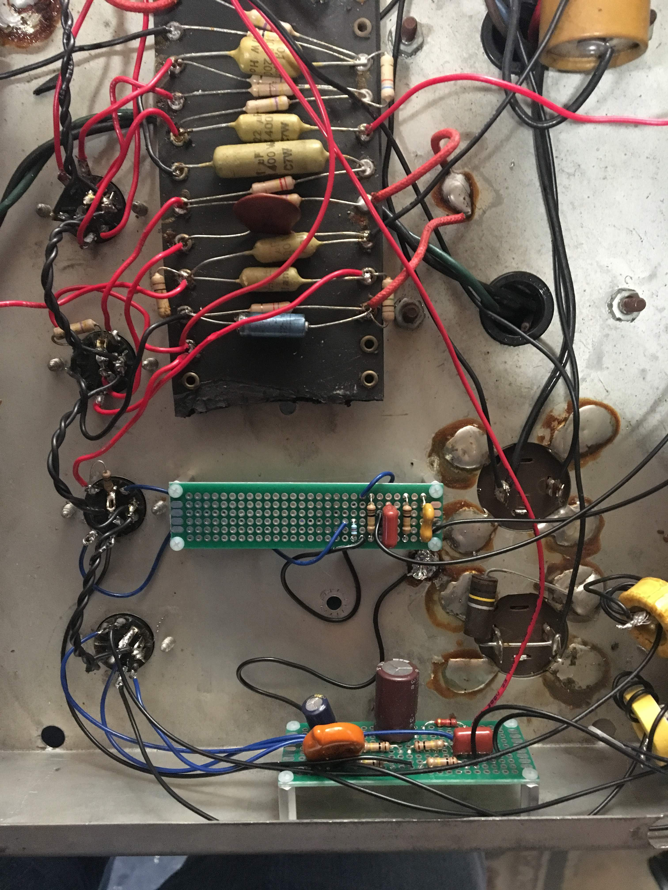
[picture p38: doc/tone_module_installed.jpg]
tone module installed
  
  Also of interest here we can see the metal film capacitor for CH2 on the preamp module.
* Test playing a bit. It continues to sound bright and warm. Have to stop to put the kids to bed.
* Move the preamp module from the side to the bottom.
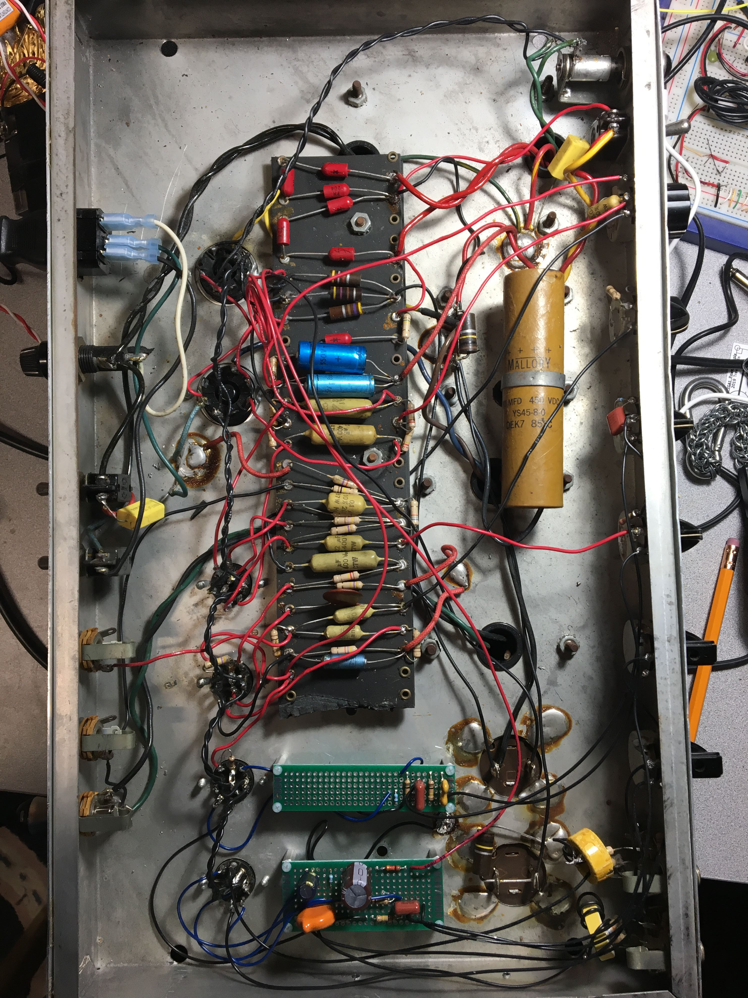
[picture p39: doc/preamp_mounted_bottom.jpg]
preamp on bottom
  
  I was worried sliding it into the case would break the screws on the outside of the metal chassis.
  Also it kind of looks all whacky haing circuit boards all different orientations.

## 2919-02-03

* Install the IEC power connector.

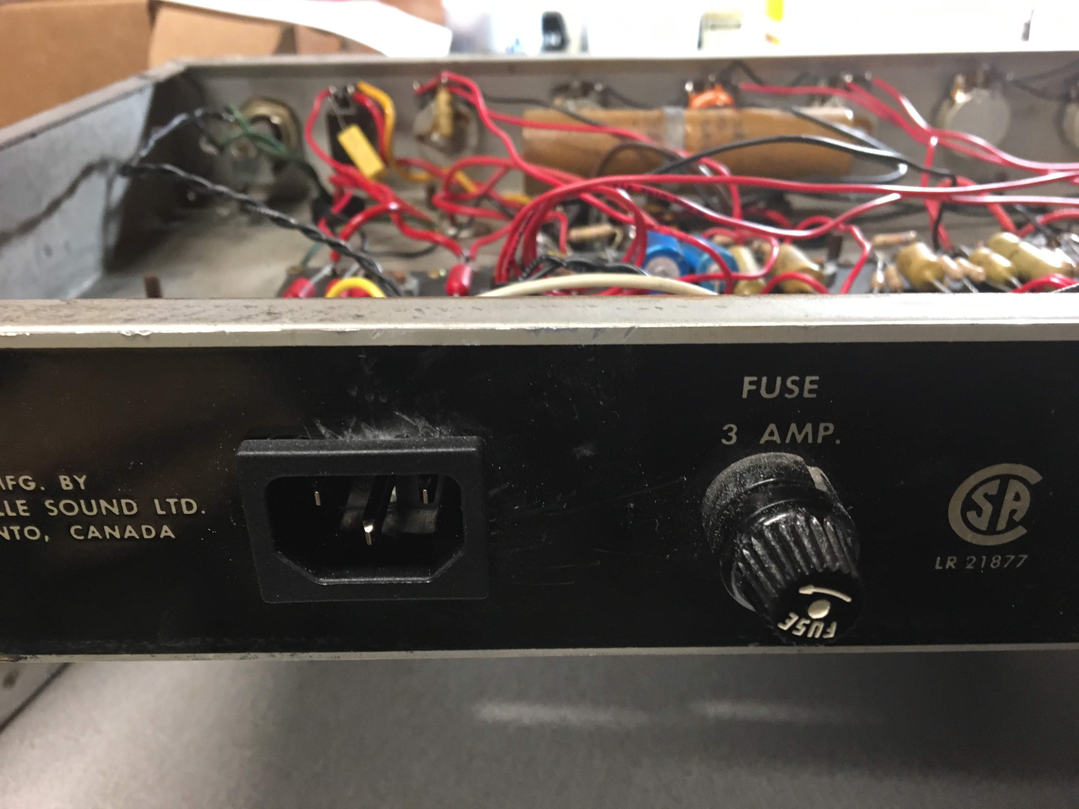
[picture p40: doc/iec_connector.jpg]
iec connector


## 2019-02-01

* Review schematic against actual construction in more detail. Discovery the switch was not wired correctly in my amp. Fix it.
* Start an "actual" schematic to compare what is in my amp vs the published schematic, and the individual module schematics I made for learning.
* Organize my thoughts for things to try to hack in a hacking.md file.
* Build a module for the preamp circuits.
* Fix the bass tone stack capacitor on the amp.
* Experiment with capacitor coupled input. I didn't like the sound, undo it.

I disconnected the power transformer from the diodes and hooked up a 12V AC power transformer. Wanting to test to see if there are any shorts in the capacitors. Or if there was any ripple on the DC voltage.

* The inputs to SW3 were wrong. It looks like the DC +V to the output audio transformer and C24 was wired up after the switch, instead of before the switch as it should be. The choke was wired up to the output of the diodes instead of after the switch like it should be. I believe this to be a manufacturing error. It is still functional the same. Only you end up having more of the circuit energized than you should. I fixed this so my amp matches the schematic.
* I now think the drive to the output audio transformer should be on the other side of the switch? I can change this from the circuit board I am planning to make by having the audio transformer center tap connect to the switch where the choke does. This just makes a lot more sense to me to have no high voltage in the circuit when in standby.

Things looked ok so I put the main transformer back in and plugged it in and turned it on. Plugged it into my room speaker and plugged guitar into it.

The amp works. Not nearly as buzzy as I would like it to be.
Some things to look into.

* Volume is scratchy. This is possibly because input jacks are loose still.
* I really don't like that brightness mod on chanel 2 (C3 on the original schematic).
* The 7027A's get pretty hot. It smells like dust burning after it has been on for about 15 minutes.

Turn it off. Put the younger two kids to bed. Come back. Test there is no left over voltage on capacitors. I think R41 and R42 help for this.

* Desolder the C3 tone cap. Discover the wire to the channel 2 volume knob was bad solder joint. That probably will help scratchiness too.
* Discover the C7 on the tone stack, on the back of the bass pot was broken. That is probably why the bass knob wasn't really working. Change this out for one of the new 0.02uF capacitors.

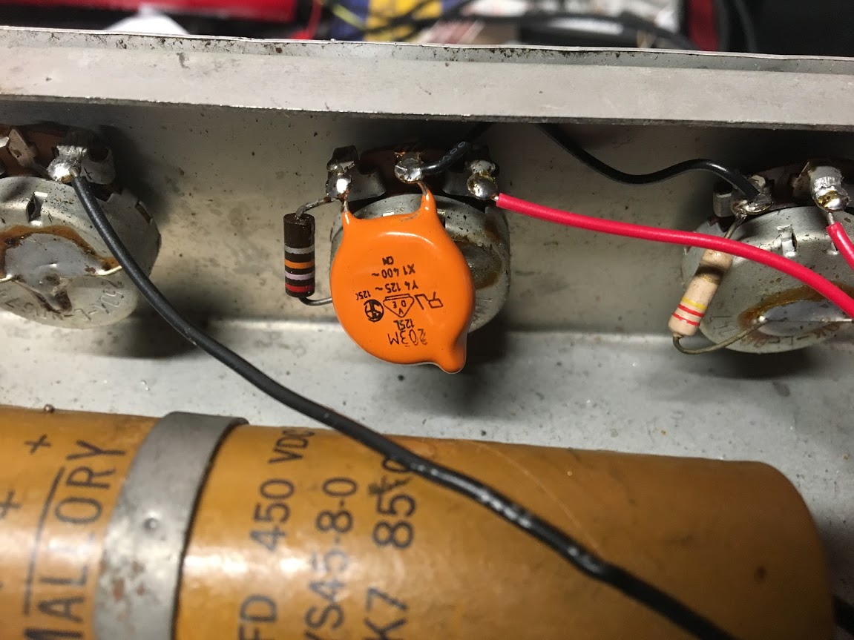
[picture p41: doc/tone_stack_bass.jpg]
tone stack bass


It sounda a lot better. Not as scratchy. And there is a lot of bass response now.

### Preamp input module

Create a small circuit board for the discrete components of the preamp circuit. The green board on the left inside the chassis.

preamp module v1

* grid bias capacitor (250uF) and resistor (820 ohms)
* 10K 1W resistor from B+
* 10uF capacitor.
* 2x 100K resistors to the anodes.
* 2x 0.02uF capacitors to volume pots.
* 2x 100k resistors to audio out.

Assemble the circuit board. Using the usual crude point to point soldering on the solder side of the board. Just the leads of the components to each other here.

Screw it to the inside of the case using standoffs and nylon screws. Use 100 watt solder iron to attach ground wire to chassis.
The extra black wire is in case I want to run this over to the power supply board later.

Connect the grid bias capacitor and resistor. Then power up and test. It continues to sound ok. Not broken anyway.

Power it off. Wire up the rest of the resistors and capacitors. Wires going to the 1st 12AX7A tube and the volume pots.
Remove the old parts and wires from the ladder construction.
Placing the wires neatly as close to the chassis as possible, keeping the wires as short as possible as well.

I depopulated the old components from the ladder board. These are those empty rivets on the entire left end of now. I removed 12 components today.

Turn the amp on, plug it into my computer and test it as a speaker for a bit. It isn't catching fire. So thre is that.

Measure the voltage into the 12AX7A again. It now has 0V AC ripple. Before it was 0.2V AC ripple, which was probably why we were hearing the hum on the output. I think the ripple went away because we have the new 10uF capacitor there.

## 2019-01-31

* Adjust board layout to give more spacing between mounting screws from power terminals.
* Submit v1.0 design of power supply board to OSHPark.
* Realize I didn't order enough capcitors. I need 2 more 47uF ones. I also realize one capacitor was missing its footprint on the schematic so did not get onto the board. Now I might have to hack this up, add a capcitor loose with wires or something.
* Fix the schematic to have the missing cap. Also replace the 100uF with 2x 47uF in parallel. This is symetric with the lower end of these.
* Create a schematic in kicad for inputs.
* Analyze the inputs. There is a HI and a LO impedence input.
* Create a schematic in kicad for preamp.
* Analyze the preamp. CH1 has a high-pass filter built into the audio path, but channel 2 does not.
* Create a spreadsheet to inventory the parts in my schematics and reference the original schematic. Also to keep track of what parts I need to order.

## 2019-01-26

* Capture power supply schematic in kicad.
* Add input part of tremolo circuit to the board, since this is 5 discrete components attached to the high voltage AC line from the transformer.
* Order discrete components from DigiKey

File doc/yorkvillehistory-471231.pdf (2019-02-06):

Yorkville Sound History
1963 to 1991
Published Feb 20,2002
Written by Mike Holman
Foreword
People have been hollering or beating or blowing on things for ages, and whatever passes for music at any point in time seems to be louder than last generation’s version. Things got very loud through the eighteenth and nineteenth centuries as orchestras grew, sometimes to immense proportions. But then came the nineteen-twenties and jazz. Small bands became de-rigeur and vocalists became strangely less vocal. Fortunately the “electric loudspeaker” had been invented just prior to the twenties as had the amplifier and microphone, hence was born the science of voice amplification, dubbed “public address” by person or persons unknown. So there was some relief for vocalists of the day, but not a great deal. Early PA systems weren’t much of an improvement on Rudy Valee’s megaphone, and they failed to get much better for the next three decades which flew in the face of improvements ongoing elsewhere - movie theatre sound systems for instance. It would be nearly fifty years before theatre-quality sound made its way to the live music stage.
Rescued from its home on the range by Gibson designer Lloyd Loar, guitar became a regular part of jazz in the nineteen-twenties. The instrument went through a brief growth process with new models getting progressively bigger and louder. But when jazz bands grew into orchestras and guitars could grow no more, they had to be amplified. At first this was done with a microphone and a modified radio, then with Adolph Rickenbacker’s magnetic pickups and a guitar amplifier. Thanks to lagging electronic technology, early guitar amps would also struggle to put out enough sound for a long time.
In the mid-nineteen fifties, rock and roll emerged and changed music technology again. Upright bass soon gave way to electric bass which begat the bass amplifier. The electric piano was born and it had to be amplified. Guitar amplifiers developed more power -these were high-voltage times.
I recall watching the Dorsey Brothers TV show one cold evening in January of 1956. Somebody named Alvin or Alvis - couldn’t make out the name - gyrated across our little black and white screen, hollering indiscernibly as I and countless other teens in front of countless other little screens watched in astonished bemusement. Eventually some of us picked up a guitar or bass or whatever and hordes of small bands were born. I was in one of them, Pete Traynor in another.
Jack Long was in his mid-twenties when rock & roll happened. A U. of T. music graduate and trumpet/bass player, Jack was already involved in music full-time. He and his wife Carol who plays piano and sings had been working together in nightclubs from Montreal to Hamilton. Now Carol was expecting their first child and it was time for them to settle down. Jack decided to retail musical instruments and that, as they say, is where our story begins.
Mike Holman

HIISTORY
1956 - 1958
Jack Long opened a small music retail/teaching operation in Toronto, J.E.Long Music Co., in 1956. A year later, he and his friend Jack McQuade - now his partner - opened a shop at 803 Yonge Street in Toronto and named it Long & McQuade Musical Instruments.
Despite Toronto’s vast urban sprawl, Yonge is still considered the city’s version of "Main Street" and has the distinction of being the world's longest such thoroughfare at around 1,400 kilometers (Yonge St. a.k.a. Highway 11). Back in the fifties, the southern stretch of Yonge was home to most of Toronto's hottest nightclubs and major music stores. Long & McQuade Music was thus a little off the beaten track, up on the east side of Yonge just across from the terminus of Yorkville Avenue and walk-in trade was somewhat limited at first, but that wouldn’t last.
While Jack McQuade concentrated on selling and playing drums, Jack Long shouldered the role of general marketer. One of his ideas was to stock a good selection of high-quality electric guitars and amplifiers, something the more established competition was slow to do. But then they were also slow reacting to the huge youth market that was springing up. Instead they stocked a majority of cheaper guitars and amps "for the kids" and kept a minimal stock of good stuff locked behind glass or adorned with Do Not Touch signs, presumably awaiting grownups bent on forsaking the mortgage payment in favor of a Les Paul.
Jack's abiding interest in young people - he and Carol have six children - would continue to guide his marketing approaches right up to the present. Back in the fifties when other music stores were cold-shouldering anyone under the age of twenty-one, Long & McQuade were spoiling them. This tended to leave youthful customers babbling about the place to anyone who'd listen then dragging them there to show it off. No wonder - Jack was like Santa. He’d even lend brand new, high-quality guitars and amps to aspiring musicians for try-outs - at home (no Hands Off signs here). Of course he also loaned things to friends who might be in a spot and needed the temporary use of something, so good will was being spread around evenly, just not very profitably.
1958 - 1963
Two years had passed and both Jacks were still playing at night, Long on trumpet or occasionally bass, McQuade on drums. Enjoyment aside, playing put food on their tables and roofs over their heads since whatever the store earned was going back into the business. Consequently Jack Long often found himself casting about for cash flow boosters, one of which was the idea of charging a few dollars for lending things out. The amounts would have to be small enough not to offend customers, but anything would help, and help it did. Jack had inadvertently sewn the seeds of Canada's first music equipment rental operation. In later years it would grow to mammoth proportions and affect the future of much more than this one operation, but for now things went slowly. Jack found himself frequently covering for Jack McQuade whose hectic playing career was now keeping him out of the store for much of the workday. This meant the good Mr. Long was putting in ten to twelve hours at the store and playing until late at night six days a week. And when the twins, Jon & Cathy arrived, he found himself getting home from the gig in time to help with the 2:30 AM feedings. Ah, parenthood.
All in all, life had become a serious grind for Jack. Things would have been a little more bearable if the store were paying off, but sadly it remained a profitless effort sponge. Tired and discouraged, Jack finally sold out his interest in 1960, hired a helper for Jack McQuade, a drummer named Fred Theriault, and left for a life of comparative normality in the real estate business.
Our story might end here but for the fact that Jack wound up back in the store regularly and in time concluded that working there would be more enjoyable than selling real estate if he could actually get paid for it. After a year or so he’d managed to save up some money and could buy back his portion of the business if a suitable financial arrangement were made. It was and thereafter Jack Long was back to stay.
Rentals had continued their gradual growth in Jack’s absence with amplifiers proving to be among the most popular items. In many cases, young guitar and bass players were blowing their meager bundles on instruments leaving amplification as an afterthought. Then all they could afford was a toaster-sized squawkbox suitable for practicing but not much more, so when they finally emerged from the basement or garage to play that all important first gig, the kids were making a bee-line for Long & McQuade to rent decent amps.
Reportedly the competition were becoming convinced that L&M was about to go out of business - “How can kids be trusted?”. But young musicians turned out to be very reliable renters. Many older guitarists and bassists gravitated to amp rentals as well, thus Long & McQuade's amplifier inventory was constantly becoming more substantial. Despite that, customers were sometimes being turned away because there was nothing left to rent, at least nothing that worked. Death, taxes and repairs, it seemed, were inevitable.
The store's electronic repairs initially went to an outside shop. Then in 1962, Jack was approached by a would-be serviceman who wanted to rent space at the back of the store to fix TV's, radios, etc. for residents of the posh Rosedale area nearby. He also agreed to help out with the store's non-functioning inventory as much as possible, although instrument amps were not really where he was grounded. Jack agreed and the arrangement continued for the next year or so.

1963
Although it soon became clear that an in-store repairman seemed ideal in principle, the man in question was having problems keeping up as dead amps and speakers began forming mute pyramids outside his room. Thankfully however the winds of change were about to blow.
Pete Traynor was a Long & McQuade customer in his early twenties. The son of an electrical engineer, Pete had been repairing amps for his friends and playing bass in local bands since highschool. He would hang around the store for hours, like many young musicians, and frequently mentioned to Jack that he could do a good job of fixing amps if given a chance, a claim which Jack recalled when the repairman eventually sought less frustrating pastures elsewhere.
It was agreed that Pete would perform the store's repairs on a piecework basis whenever he had time and Jack settled back, prepared to hold impatient customers at bay a little longer. But to everyone’s astonishment, nearly the whole mess - several month's backlog - was cleaned up in very short order. Pete continued to repair things part time for a couple of weeks, then he was hired full-time.
Pete Traynor proved to be a frenetic worker with little regard for "factory original" parts. More accurately he lacked the patience to wait for them. But so did the customers. If something wouldn't work with off-the-shelf components he'd modify it so that it did, a trick that required more than the average amount of technical acumen. But occasionally a power transformer had to be ordered from the manufacturer resulting in a long-term wait. This left Pete grumbling and vowing that if he were ever to design an amplifier, his power transformer would be virtually bullet-proof.
Pete was developing a growing list of retail parts suppliers - Alpha Arakon, Electrosonic, etc. - and eventually he even found a speaker manufacturer, Marsland Engineering, who would sell to him. It was seldom difficult for Pete to obtain speakers, parts, tools, test equipment, etc.; he was spending Jack Long's money and Jack had trouble
saying no.
In time Toronto began awakening to the fact that there was someone at Long & McQuade with the ability to fix almost anything. High-caliber audio/video repairmen were around back then, but few knew or cared enough about instrument amps to work any wonders. By comparison, Pete Traynor seemed like Merlin with a soldering iron. As if to further such notions, he took on the added task of modifying things. In this pre-fuzzbox, pre-master-volume-control era, he could make guitar amps provide the distortion and sustain popularized by ex-band-mate Robbie Robertson. Pete even sawed someone’s Hammond L100 organ in half to make it portable (Ray Harrison – that
was his solo on Del Shannon’s “Runaway”). Such legendary stuff, along with the magnetic pull of Long & McQuade, drew even more customers to the little shop on Yonge Street.
A few weeks after Pete started working at the store full time, a customer requested that he design and build a pair of portable PA speakers for him. This appears to have prompted one of those ‘lightbulb’ moments. Incredibly, no-one seemed to be building portable speakers for public address, nor portable amplifiers, nor anything else. There were commercial PA amps which ‘could’ be adopted for portable systems, but they were clumsy to set up and offered only one or two mic inputs, and who cares - there were no speakers to use with them anyway. Meanwhile, the systems built into most playing venues were awful antiques that squealed and distorted or didn't work at all.
The dreaded no-PA syndrome may have spared dance bands fits of grief; their music is generally around ninety per-cent instrumental. But rock & roll is about ninety per-cent vocal and that’s what most of the store’s customers were playing. So what did rock & roll bands do when there was no PA? Too often they played the handful of instrumentals they knew, over and over until the audience threatened violence. Then they packed up and fled into the night, often penniless. Obviously portable PA could solve some nagging problems.
After puzzling over possible designs, Pete took a page from one of his reference books and conjured up something called a "sound column" based on a principle developed by RCA in the mid nineteen-thirties. The first two columns each contained six eight-inch speakers and two ten-inch speakers which made them better than six feet tall, hence they could get sound out to the back of a hall or club even from a low stage. As well, that vertical speaker alignment promised to spread sound over a large area.
The finished columns were covered with dark purple material to match the band's suits and placed in a corner of the store, awaiting the group’s return from a tour. That's when the customer enquiries started. People would ask,”What are those things?" and Jack would reply, "Sound columns. You know - portable PA speakers". This prompted reactions generally typified by a brief pause (while their lightbulbs turned on) followed by, “Do you have any more?”.
Pete soon found himself building columns whenever he had a free night. These ones contained six eight-inch speakers, no tens, that just made them too tall for station wagons (Econoline-style vans were still rare 1963). They were covered in black vinyl -more durable and subtle than purple cloth - had metal corner pieces, quarter-inch jacks for quick connections, strap handles and steel glides to stand on. Best of all, Pete had located a metal fabricator to cast script-style "Traynor" logos out of aluminum (ah, instant immortality). The only accessory needed was a pair of speaker wires, 30 ft. long with a 1/4-inch plug at one end and bare wires at the other so that it could be connected to the screw terminals on a commercial PA amp. Pete made these too and called them “column lines”.
Now Pete wanted to design a bass amp. They were always out of stock for rentals and he'd roughly calculated that, even paying retail prices for parts and raw materials plus whatever a machine shop would charge to make the chassis, he could still build the amp and price it reasonably, with enough margin left to cover operating costs including labor. Jack agreed to fund the project and further asked Pete if he could build a few rather than just one. Pete agreed.
Initially dubbed "Dynabass" (40 watts sine-wave rms @ 8 Ohms) and later to be renamed “Bass Master”, this amplifier head (no speakers built in - the kind with speakers are called “combos”) was designed with both bass and guitar players in mind. There were two pairs of input jacks, each with its own volume control and sound, with
channel two being brighter for guitar. An internal wiring gimmick provided a little extra distortion for guitar players if they patched a short cable between one of the jacks in each channel then turned up both volume controls.
There were also bass, treble, low and high (midrange & treble) “expander” controls. Perhaps reflecting on the oath he'd grumbled earlier, Pete included a third transformer in the Dynabass to act as a buffer for the power transformer. This he deemed important because tube amplifiers will self-destruct if you neglect to plug in a speaker or if your speaker goes dead. Usually the musician switches off the amp as soon as he/she notices there is no sound hence the damage is hopefully limited to the output tube sockets and possibly the output transformer, components which can generally be obtained from retail electronic supply shops. But if the amp doesn’t get shut off in time, the power transformer is next to go and that’s always a custom-made part available only from the amp manufacturer. Pete’s buffer transformer would sacrifice itself to save the power transformer which is bigger, more costly and much harder to get. Replacing the buffer transformer was still an expensive proposition, but a repairman had the option of simply wiring around the burned out component which would cost very little, albeit the safety margin would be removed.
*About Traynor amplifier power ratings. Distortion analyzers were rare and expensive in the early 1960s so Pete’s power test method utilized basic repairman’s gear - a dummy load (a big resistor), an oscilloscope, an oscillator and a voltmeter. The oscillator was set at 1kHz sine wave and plugged into the amp’s input while the amp’s speaker output jack was connected to the other three things. The volume was turned up until the sine waves on the oscilloscope evidenced some squaring-off at the tops and bottoms then it was turned back down a little until the wave forms rounded off again. Finally the output voltage was measured and converted into watts mathematically. When you encounter “rms” after amplifier power ratings herein, it is power measured under these test conditions.
Of course amps put out considerably more power than this when they’re turned up full and roaring with distortion, in some cases nearly twice as much. But those ratings don’t count to bass players who need to know the maximum clean output only. It’s interesting to note that this conservative sine-wave criterion was adopted for bass players, by a bass player.
Competitors were often quite liberal with their power ratings. Some used fully distorted maximum Watt ratings - double the sine wave rating - and called them “rms” which is perfectly legal since “rms” (root mean square) has no bearing on distortion. Others used “peak” ratings which are even less meaningful. But Pete couldn’t do this. Having established a “clean” criterion for bass amp power ratings, he naturally later carried it into PA and guitar amp power ratings. Why not use two types of ratings, a clean one for bass amps and PA, and a “dirty” one for guitar amps? Because Yorkville could end up with “90-watt” guitar amps that were clearly no more powerful than “45-watt” bass amps
- a major ratings jumble, especially considering that guitar players were using Bass Masters almost from day one. So, not surprisingly, Traynor literature contained no power specifications well into the 1970s. And when the numbers did finally appear in literature, for years thereafter people would say,“There are Watts and then there are ‘Traynor Watts,’” implying that the Traynor Watts were somehow bigger. (But now you know the rest of the story.)
Today, thanks to the Audio Engineering Society’s hard-fought efforts, amplifier power ratings have been standardized and are much more reliable.

About Traynor speaker power ratings:
Up until the 1980’s, Yorkville’s method for determining a speaker’s maximum power capacity involved the use of an oscillator, an oscilloscope, a voltmeter and an amplifier. The oscillator would be set for sine wave and plugged into an amplifier’s input, then the other things plus the speaker to be tested, in its intended enclosure, would be connected to the amp’s output. The oscillator would be set on slow sweep from 20Hz to

20kHz and the amp would be turned up to the first power level which was whatever the manufacturer claimed. If they said it handled 50 Watts rms, the amp would be turned up until the voltmeter read the equivalent of 50 Watts in volts depending on the rated impedance of the speaker. The scope would then be checked to make sure the amp wasn’t clipping and the whole works would be left going bwoooooeeeep-bwooooeeeepbwooooeeeep for a few hours. If the speaker survived, the power would be increased and the process repeated until the speaker finally burned out. The last safe power level would then be chosen as Yorkville’s “rms” rating for that cabinet.
Of course, if the oscillator sweep rate was sped up (bweepbweepbweep) the speaker would be able to survive higher power levels because it spent less time at any particular frequency. Later, when pink noise (sounds like Niagara Falls) was invented and used as a signal source, speakers could handle even more power. As a result there was a long period wherein nobody was really sure how much power a given speaker could take with actual music as the source because there were so many different test methods all netting different results (and what’s worse, the nature of the music itself can kill a speaker). Here again Yorkville opted to avoid the problem by not publishing power specs. That too continued into the seventies.
Today, thanks in part to the advent of CDs with their lifelike dynamic range, there are “program” (pgm) power test procedures which represent the speaker’s ability to survive power levels under a wide range of real music conditions. Of course even these procedures are open to interpretation depending on the type of music used. For example, due to its wide swings in dynamic range, classical music is far less likely to damage speakers than compressed, heavy rock which keeps the speakers almost constantly at the same operating levels. Here, Yorkville has again chosen to be conservative by using very dense, compressed rock CDs as well as pink noise. Yorkville speaker power specifications have been “pgm” since the mid-1980’s.
Six Dynabass heads were completed in October and put with bass cabinets which Pete had also built, each containing a single fifteen-inch speaker. As legend has it, everything was immediately sold, not rented, leaving rentals in the same fix. Another legend indicates that the speakers were over-powered by the amps, blew out quickly and the whole works came back for repair (both rumors are disputed). In any case, everything seems to have ended happily because Pete needed to build more right away and that’s how it went for the next while - small batches every few weeks.
Between columns, bass amps and cabinets, building things had become more and more demanding on Pete’s time. A helper, Pete’s pal Tex Taylor, had been working alongside him since September ‘63 and a third man, Don Fisher, was added in October at which time it occurred to Pete that this operation might be worth turning into a company. He offered to put up one thousand dollars of his own money if Jack Long would come in with him. Jack agreed and a partnership was formed with Pete owning one third and Jack the other two.
Before year end 1963, a batch of twenty-four Dynabass amps was produced. These had a new feature, a small black-on-copper back plate bearing a serial number from "0001" to "0024” (such optimism), also the electrical ratings and the words "Bass Amp, mfg. by YORKVILLE SOUND, Toronto, Canada". Voila - the principles had agreed on a company name and, just like that, Yorkville Sound was born. Amazing! Only six months had passed.
To set the record straight with some self-acclaimed Traynor historians, it’s worth noting that at no time was there ever a “Traynor Amp Co.”, or “Traynor Sound” or whatever. The operation went from a repairman building things for customers in his spare time, right to Yorkville Sound, all during this brief 6-month period in 1963 and all within the confines of Long & McQuade Music. And, once again, it was Pete’s idea to form Yorkville Sound with Jack agreeing to put up the bulk of cash - as he’d been doing all along.
1964
The little back repair room had become horribly cramped by roughly mid-1964, forcing the operation to relocate in the store’s attic. A few more employees were added and so Jack asked Fred Theriault who had a keen eye for details, to manage the little operation and perhaps buffer the occasional differences he and Pete were having. Never one to take challenges lightly, Fred ended up managing Yorkville Sound's day-to-day operations through several years of hectic early growth. Finally, Pete was free to concentrate on his first love, tinkering and designing
things.
"Dynabass" became "Bass Master" in 1964, and on the amp's back plate, "Bass Amp" was replaced by model designation "YBA-1" - Yorkville Bass Amp #1. About this time power was increased slightly to 45 Watts @ 8 Ohms. 12AX7 preamp tubes were mated at first with 7027A output tubes, but later 6CA7’s were standardized.
Columns now had back plates too. They read "Model: YSC-1" (Yorkville Sound Column #1) and bore 4-digit serial numbers. Ratings were 150 Watts, 5.3 Ohms. Columns, it turns out, were about to become the foundation of the 1960s PA revolution.
Later in 1964 the YBA-1's cube-shaped bass cabinet officially became the YS-15 (Yorkville single-fifteen, 50 Watts rms, 8 Ohms) and some new products were introduced including the YBA-2 "Bass Mate" combo (20 Watts rms). Fundamentally this was the cube-shaped YS-15 cabinet but with a rear-mounted amplifier chassis featuring volume bass and treble controls and a square opening in the back where the power cord could be stashed.
Also bowing in this year were the YSC-2 column (48 Watts rms, 8 Ohms) with four twelve-inch speakers for customers who wanted more bass, and the YSC-3 (100 Watts rms, 8 Ohms - yes, twice the power capacity of the bigger YSC-2) with just four of the YSC-1's eight-inch speakers, to please customers who said that the YSC-1 and -2 were too long to fit in their cars.
As well, two "Hi Tone", high-powered, twin-twelve guitar amps (no known specifications) were test-built. A sloping top to make it butt-proof (smokes just rolled off) and drinkproof (so did drinks) failed to help the Hi Tone's self-destructive electronic design and it never went into production. Perhaps discouraged by this setback, Pete did not attempt to design anything similar for several years.

1965
On January 1st, 1965, Jack Long and Pete Traynor officially became President, Vice President and sole shareholders of "Yorkville Sound Limited.". Now the little operation settled into its new role as a real company complete with invoices on which the product chronology herein is partially based, and soon a mandate to move out of Long & McQuade's cramped attic. This was accomplished later in the year when the company relocated to the second floor of an elderly industrial building in Toronto at 431 Dundas Street East near Parliament Street. This facility had room for added people and machines plus a design lab which would later house a small but growing technical staff. There was even office space for Jack Long whose direct guidance was needed more regularly as the company grew.
Jack McQuade opted out of the store to devote his full time to playing drums in 1965. For business and personal reasons, Jack Long decided not to change the store name. Early in ‘65, Jack was approached by a traveling salesman named Murray Cooney who thought that other music stores might be interested in buying Yorkville Sound's Traynor products. With the major U.S and British competition around at the time - Fender, Ampeg, Gibson, Vox, et al - it didn't seem likely that there would be much interest in an obscure home-grown line. Still, Jack agreed to pay Murray a commission on whatever business he could dig up and that's how it was left.
Moving the factory may have blunted Pete Traynor's creative thrust temporarily. Only three new products debuted this year. The first was another guitar amp, the YGA-1, "Signature" head (45 Watts rms @ 8 Ohms). Here, the trusty YBA-1's electronics were adopted with its Low and High Range Expander tone controls replaced by Tremolo Speed and Depth controls.
The Signature did not have reverb, ergo an unusual companion product was developed, the YHI-1, "Amp Mate Reverb" comprising a single twelve-inch guitar speaker and spring reverb unit all in one box – basically an extension speaker with built-in reverb. It was designed to be used with a regular guitar cabinet as the footswitch cut the whole unit in and out including the speaker.
The YT-12, (50 Watts rms, 16 Ohms) was introduced to go with the YHI-1. This was a twin-twelve guitar cabinet featuring Phillips "Norelco" speakers and was a mate to either the YGA-1 or YBA-1. The speakers each featured a small center cone for added high frequency response (technically a “parasitic radiator”) and a cylindrical alnico magnet. Luscious-sounding, the YT-12 lived on for several years while the Signature head remained in production until 1969. The curious YHI-1 survived only until late 1966 when the TR-1 reverb was introduced.
1966
New product design got back on track in ‘66. The YT-15 (100 Watts rms, 16 Ohms), a twin-fifteen bass enclosure designed for use with the YBA-1, had been built randomly earlier (like other things), but now went into regular production. This also applied to the YS-15L (100 Watts rms, 8 Ohms), a *Lansing D-130-equipped version of the YS-15, also the YTL-15 (200 Watts rms, 16 Ohms), dual Lansing-equipped cabinet.
*Shortly afterwards Lansing changed their name to JBL and it appears that the D140 was subbed in to replace the D130s which were underpowered and blew in the YS-15L.

The YSC-4 (48 Watts rms, 8 Ohms) made its appearance in 1966. This square, four-twelve PA cabinet utilized the YSC-2’s 12-inch speakers and went up on a robust stand making it a "first" for Yorkville and apparently in North America - no other stand-mounted portable speakers were available at the time. It also came without a stand adaptor as the YSC-4A, a guitar cabinet, two of which could be stacked up for use with the YGA-1 or YBA-1 (those twelves sounded nice but could only handle 12 Watts rms apiece, hence two YSC-4As were required to handle the amp’s maximum potential output of roughly 80 Watts).
The YF-10 (100 Watts rms, 8 Ohms) four-ten bass cabinet bowed in with the distinction of being suitable for either bass or guitar. Also new in 1966 were the TR-1 tube reverb unit which replaced the YHI-1 Amp Mate Reverb speaker, also the YGA-1A, (45 watts rms @ 8 ohms) a combo version of the Signature head with a 15-inch guitar speaker built in, and the YSC-5 (100 Watts rms, 8 Ohms), another stand-mounted PA enclosure, this one containing a single 12-inch Lansing D120. The YSC-5 further had the distinction of being one of the first internally horn-loaded reflex enclosures on the market.
The YVM-1 Voice Master (45 Watts rms @ 4 or 8 Ohms) appeared in 1966. Another "first", the Voice Master was a tube-type, four-channel portable PA amplifier roughly based on the YBA-1. This cornerstone product inspired a whole generation of mixer/amplifiers referred to as “PA Heads”. It featured four channel volume controls, a master volume control, master bass, middle and treble controls and a pair of reverb send and return jacks for patching the TR-1.
The competition was quick to respond. Even a popular microphone manufacturer was inspired to introduce a portable PA system complete with column-type speakers and with the word "Master" in its title.
1967
No need to go deeply into financing, but it’s worth mentioning that L&M and Yorkville worked from a bank loan and still do. Like the operating loans of most companies that are growing, they need to be increased occasionally in order to obtain more of this and/or a new one of those and/or to hire additional staff, etc. The process of obtaining more money can be dicey when a company is growing as fast as these two were, especially Yorkville. It seems hard to believe, but banks get nervous about rapid growth and Jack had run into a brick wall trying to obtain additional funding. Thankfully this was resolved by a beneficent bank manager in 1967, saving Jack the necessity of signing over 25% of the two companies to a prospective lender who owned a major chain of burger joints (whew!). Now there would be ample funds available - for the time being -and expansion was becoming more of a necessity every day.
Jack decided to investigate establishing a second L&M store in 1967, this one in booming, bustling Vancouver. Two Traynor dealers out there had run into trouble leaving Yorkville’s products with no retail representation in the area. As well, Jack could see that an expanding market base was going to be important to both companies.
Pat Coffey, a key salesman at Long & McQuade, was an ideal candidate to go there, scout it out, then run the store if things looked good. Pat reported back favorably then returned to Vancouver with wife Judy and son Brett to begin the process of setting up the store in their new environment.
Less than two years after growing out of Long & McQuade's attic, Yorkville had now grown out of 431 Dundas St. East. Mid-1967 the company moved several blocks down the road to number 744 Dundas St. East, a two-story building perched by the Don Valley. Yorkville occupied all of the second floor plus the north and east sections of
the first floor (the building had a center courtyard and so was roughly U-shaped). Overall floorspace was sufficient to allow for an expanded woodshop, an all-new machine shop (no more getting chassis built outside), greater lab space and even a sound room which could double as a recording studio. As well, Jack decided to hire a production manager so that Fred Theriault could concentrate more on sales management. He also had an office built there for himself. Henceforth Jack would make Yorkville his home base and visit the store rather than vice-versa.
Murray Cooney's efforts had resulted in a number of Canadian music stores buying Traynor products which made the opportunity to take on additional salesmen more attractive. This happened in 1967 when US-based Peter Fremd added the US eastern seaboard down to Maryland to the market base. Murray had developed Traynor dealers in the western parts of New England plus New York, and the northern parts of Michigan, Ohio & Illinois the previous year so Yorkville's products were already making their way across the border as early as 1966.
Laub Warehouse in Buffalo was contracted in 1967 to facilitate US distribution. This was an operation where you paid for a block of floorspace by the square foot and their employees would both receive and ship for you. Yorkville would ship in quantity to Laub then US orders could be called in there directly by the dealers. Laub employees would answer the phone in the Yorkville area “Yorkville Sound” and take the orders. Shipping followed a quick credit check and it all worked quite nicely. In future, Yorkville would rent a larger block of space there and hire two employees to work in it, one for repair service.
New products for '67 included the MX-1 which was unique in two ways; it was a very small, 4-channel mic mixer - such things were quite rare then - and it was powered by a 9-volt battery. There were four 1/4” inputs each with a volume control, also an output jack and a master volume control which doubled as an on-off switch. The MX-1 had another distinction; it was Pete Traynor's first solid-state product (it contained one transistor - a humble beginning).
The little YBA-2A Bass Mate head (24 Watts rms @ 8 Ohms) was added so that bassists wishing a lightweight, 2-piece outfit rather than a combo amp could be satisfied. Usually coupled with the YS-15, the YBA-2A’s controls included volume, bass and treble.
Going the opposite way size-wise, the YBA-3 "Custom Special" was a "first" in terms of power. At 130 watts sine-wave rms @ 4 Ohms (potentially over 200 Watts full-out), this head was the most powerful bass amp then on the North American market. It also contained a fan for the four 6CA7 output tubes and a large bolt which went through a hole in a round steel plate in the bottom of the box. The YC-810 cabinet had a similar plate ontop which was tapped to take the bolt. YBA-3 controls included volume, bass, treble, low and high (mid) range expanders and there were bass and treble boost switches. A master volume control was added in 1971 making the Custom Special a really formidable guitar head.
The colossal YC-810 "Big B" speaker enclosure, (200 Watts rms, 4 Ohms) was another "first" and was the YBA-3's bass cabinet. In this case it was the number of speakers -eight tens - which distinguished the product. Initially, the YC-810 came mounted on a tube-steel swivel dolly with massive wing bolts on the sides so that the cabinet could be pivoted up or down (hence the bolt in the YBA-3 to hold it in place). Later this was replaced by a regular dolly and the hold-down bolt arrangement was removed. The YR-412 "Rogue" guitar cabinet was also for use with the YBA-3. Initially, it featured two high frequency horns as well as four robust twelves. Later the horns were dropped.
The 20-watt YGM-1 "Guitar Mate" (20 Watts rms @ 8 Ohms) filled the need for a compact combo, but more significantly it represented a bona-fide guitar amp (the Signature was the only other guitar amp in production at the time and it was actually a modified Bass Master). The YGM-1 featured volume, bass and treble controls as
well as reverb, tremolo and a 12-inch speaker. Later the YGM-2 Guitar Mate (25 Watts rms @ 8 Ohms) came out. This was virtually the same amp as the YGM-1 minus reverb to reduce the price, but with 5 watts more power. It too appeared in 1967.
A unique "first" proved to be farthest ahead of its time in 1967 - the LS-1. This portable lighting system featured two sets of four, differently colored, swivel-mounted floodlamps attached to crossbars which went up on speaker stands. A console-style switchboard controlled the system simply by turning the power on or off to the various bulbs. Primitive perhaps, but it worked reliably and there would not be any club size lighting systems on the market for years to come.
Then there was the TRC-2A "Roto-Master" - basically the top part of an organ cabinet with a spinning high frequency horn inside. This could be used with a guitar combo or stack in place of the delicate Leslie cabinets previously in use.

1968
On September first 1968, Long and McQuade Music opened its doors on Vancouver’s Granville Street with three employees including manager Pat Coffee. Today there’s still an L&M store on Granville, the second largest of all the L&M stores and with considerably more than three employees. Things have gone well - the store is at more of an uptown address these days, and Pat Coffey still runs it.
Product-wise, someone must have pointed out to Pete Traynor that there was a rather large gap in power between the 45 Watt YBA-1 and the 130 Watt YBA-3. In any case, the YBA-1A "Bass Master Mark II" (90 Watts rms @ 4 Ohms) was ushered in during 1968. Looking identical to the YBA-1 except for its name and a telltale fan built into one end, the Mark II delivered around double the YBA-1's power from the same two 6CA7 output tubes, a fact which still leaves vintage amp collectors dumbfounded. Soon after its introduction the YBA-1A encountered growing use by guitar players.

The YC-610 (150 Watts rms, 5.3 Ohms) had six of the ten-inch speakers from the YC-
810. It could be used for bass or guitar and was developed for the YBA-1A. And so was the YB-18 (apx. 80 Watts rms, 8 Ohms), a compact cube-shaped cabinet containing an 18-inch Goodman speaker, and the YN-412 guitar cabinet (100 Watts rms, 8 Ohms). Although the YN-412 came loaded with a quartet of the gorgeous-sounding Phillips Norelco twelves, it had a more punchy midrange tone than the YT-12.
A new reverb unit made its debut in 1968 - the TR-2. The TR-2 was solid-state and worked equally well for PA or guitar, unlike the tube-type TR-1 which was designed for use with the YVM-1 and was not suitable for direct guitar plug-in.
There was great demand for a bona-fide guitar amp in the 45-Watt range. Voila, the YSR-1, Custom Reverb head (45 Watts rms @ 8 Ohms). It featured the same dual sets of inputs and volume controls as the YBA-1 plus controls for bass, treble, reverb and tremolo speed and intensity. Interestingly, a year after its introduction, a YSR- 1 was ordered by a shop in California who needed one desperately for a customer. When told that the amps were out of stock the owner said “But it’s for Elvis. He’s opening in Las Vegas in two weeks”. Shortly afterwards, a lone YSR-1 came down the production line amid excited whispers from the staff. It was later rumoured that when Elvis opened there were a number of Traynor products onstage.
“Psychedelia” - a word which struck joy into the hearts of drug-culture fans - had found its way to the rock stage. But you couldn’t put on a really psychedelic show without the right lighting. A strobe was essential. Thus Long & McQuade customers brought pressure to bear, Yorkville responded and voila, the YSM-1 Strobe Master. This was a smallish black box with a clear plastic screen on one side, a strobe bulb and reflector inside and a small control panel on the left side containing the speed control, footswitch jack and on/off switch. Little did Yorkville designers recall this (less than) landmark model number when naming a studio monitor twenty-three years later. Ah well, the strobe fad was soon “up in smoke” and with it went the Strobe Master.
1969
This was the year Woodstock happened - a musi-cultural explosion with aftershocks that shook war-weary North America to its roots. In Woodstock’s wake, things changed in the music business. Jimi Hendrix, Joe Cocker and Janis Joplin suddenly became household names. Comedians Cheech and Chong became overnight recording stars as did sitarist Ravi Shankar and numerous equally obscure acts who might otherwise have remained unknowns.
On the music supply front, Fender Stratocaster guitars suddenly refused to stay on music store shelves, Jim Marshall's guitar amp stacks began chugging regularly across the Atlantic from England and Pete Traynor began getting the strangest phone calls. Promoters and musicians alike wanted to put on Woodstock-style concerts and
Pete was the only one they knew with any chance of providing the sound. Some “chance” - Pete was a designer, not a live sound engineer. And why all the fuss? After all Elvis, the Beatles and countless other major acts had performed without "big PA”, so what was the difference now? The difference was that Elvis and the Beatles got drowned out by screaming fans and what little you could hear was squawky with some instruments, especially bass, being totally inaudible. At Woodstock, dozens of microphones, a multi-channel mixing console, numerous amplifiers and piles of movie theatre speaker systems made everything audible. The basic sound quality was infinitely better than anyone had ever heard from a PA system. So, like it or not, live sound was a whole new ball game and Pete Traynor, it seemed, had been picked as the starting pitcher.
There was good news and bad news about Pete getting into this field in 1969. While it promised to provide a tremendous showcase for Yorkville's products, Pete knew virtually nothing about contract sound, neither the contract part nor the technicalities. Nor was there a body of knowledge for him to draw upon - big PA had just been born, who knew? Of course his product design efforts were needed at Yorkville and this endeavor was bound to interfere with that process so, on the surface of it, the cons appeared to outnumber the pros here. But Pete Traynor had a tendency to tackle anything that resembled a larger-than-life challenge and this one further promised a certain amount of reflected spotlight. It must all have seemed quite irresistible.
In later years, Pete stated that promoters were offering him tens of thousands of dollars per show. And if that news hadn't swayed Jack Long sufficiently, Pete claimed that he even offered to guarantee no losses out of his own pocket (which Jack would have suspected was empty thanks to a big car, a big motorcycle and a cabin cruiser). But there were certain positives to the whole thing and Jack still had trouble saying no, so the project progressed.
It made sense for Yorkville to build Pete’s system. Recording studio mixers were terribly expensive and delicate, often having to be aligned after they were moved, a process which could take several hours if not days. Studio style amplifiers of the day were prone to breakdown if not treated with kid gloves and theatre speaker systems weren’t really designed for traveling the countryside. On the other hand, it appeared that Yorkville only needed to engineer three things for the system; a power amplifier, a mixer and a horn-loaded bass bin. The new YSC-6 (see below) would suffice as a midrange cabinet loaded with JBL speakers and there would be no trouble hunting down some big high-frequency horns and compression drivers. Pete said he could design the power amp while lab chief, Paul Hallam, worked on the bass bin. Only the mixer remained a problem. Pete's solid-state design experience was still a bit limited for something this big, but he knew a designer who could handle it.
Brian Lord, an independent electronics speciallist, was contracted to design Pete's big mixer. Meanwhile Pete had set to work designing the MX-8 - a mono, 8-channel, non-powered mixer in a black case with a removable hinged lid. It featured volume, bass, treble and reverb controls on each channel plus masters for volume, "monitor" volume (a parallel main mix master with its own output jack), reverb and reverb tone. The MX-8 represents probably another "first" for Yorkville and worked so well that Cerwin-Vega eventually ordered a modified version branded for them.
Pete's power amplifier, the YPM-1 (100 Watts rms at 4 Ohms) was also mono and, like the MX-8, came in a box with a removable hinged lid. It featured two parallel input jacks, two parallel output jacks and a volume control. The MX-8/YPM-1 combination represented another "first" for Yorkville - a 100 Watt, channel club PA.

The bass bin too was designed in fairly short order - sound jobs had already been confirmed. This was a large folded-horn enclosure (a.k.a. "W bin") designed to take the YB-18's 18-inch Goodman speaker. Designated YB-18A (80 Watts rms, 8 Ohms), it could be sold or rented as a high-powered bass cabinet for use with the YBA-1A or in pairs with the YBA-3. Later on, the Goodman was replaced by a heftier Celestion speaker and eventually the cabinet was adopted by sound men putting their own big PA's together.
Those dual-cone Norelco twelves used in the YT-12 and YF-12 guitar cabinets were so versatile they ended up in the YSC-6 (50 Watts rms, 16 Ohms), a large twin-twelve PA cabinet featuring the YSC-5's horn-loaded reflex format. As mentioned earlier, YSC-6s were loaded with JBL speakers for Pete’s system.
Design work proceeded on a 16-channel mixer for Pete, but it would not be finished in time. His first job – the "Strawberry Fields” festival at MOSPORT race track - had to be mixed with three MX-8's stuffed into a long wooden box. They were inter-connected to work as much like one 24-channel mixer as possible and the reverb pans were
removed so that the channel reverb controls could function as monitor level controls with the reverb footswitch jacks connected to YPM-1s driving the stage monitors (YSC-6s *lying on their sides, propped at an angle with bricks, etc.).
*Eventually Yorkville built Pete some angled “wedge” monitor cabinets - another “first”. Finally a big truck was acquired along with scaffolding and even a few sound crew technicians where Yorkville employees were not available. Two of them, Larry McCabe and Dirk Vandersleen, later became full-time Yorkville employees who went on to design products for the company.
By now, Jack must have been wondering what he'd let Yorkville get into. On top of everything else, Pete had instructed Brian Lord to start designing a bigger mixer. Sixteen channels were clearly not going to be enough, twenty-four was now the magic number (meanwhile a completed 16-channel board with pushbuttons that lit up
was left to molder). Pete also wanted four main mixdown buses, two monitor buses with pre and post-EQ channel send controls, a solo bus, input phase-reversal buttons (a Yorkville “first”, handy for defeating feedback - tape two identical mics together side-byside, plug them into separate channels then reverse the phase on one of them).
There were also separate input attenuation and volume controls on each channel, dual built-in graphic equalizers (another Yorkville “first”) and multi-function VU meters. Pete also specified that all input and output connections be duplicated at a large multi-pin connector on the back panel so that he could hook the mixer to the stage junction box with a single, multi-element *cable, another Yorkville “first”.
*Today, PA "snakes” are commonplace, but they’re still not quite as sophisticated as this one with its massive, multi-pin Elco connectors and rapid hookup capability. Compared to recording mixers, the MX-24 lacked slide-type level controls. Pete had insisted on rotary level controls because he believed they would be less prone to fouling and noisy performance. But otherwise the mixer was a PA sound man’s dream and so thought other people. Before long, bands began asking if Yorkville could build them a mixer like that. Warnings that it would cost thousands usually went unheeded - they could smell stardom in the air. Naturally the idea was resisted. Pete's mixer had been hand assembled by a small number of people, but in production, the huge boards could tie up Yorkville’s manufacturing for weeks meaning thirty-odd other products might not get built. The idea of making everybody do without stock so that a few people could have big mixers didn't sit well with anybody and the MX-24 did not go into production (in 1969, that is).
The little U.S. operation at Laub Warehouse in Buffalo (see 1967) changed its status in 1969. Yorkville had been marketing into the US long enough to possibly incur a surtax since it was a foreign company trading directly into the States. In order to smooth out that situation, Jack formed Yorkville Sound Inc. Now there was an American Yorkville Sound, a fact which would prove to be of great benefit in future.
Pete Traynor obviously had his hands full in the latter half of 1969, so it comes as no surprise that new consumer products were a tad sparse. However a few were developed including the YBA-2B, Bass Mate (25 Watts sine wave rms @ 8 Ohms), a slimmed-down, closed-back replacement for the cube-shaped YBA-2 with 5 Watts more power and with controls - volume, bass & treble - located on the front rather than at the back.
The YGM-3, Guitar Mate (25 Watts rms @ 8 Ohms) added reverb to the YGM-2's extra power and replaced the YGM-1. YGM-3 would soon become Yorkville’s most popular guitar amp and remained at the top in unit sales until 1980 when tube amp production ceased.
At the absolute opposite end of the power spectrum was the YBA-3A, Super Custom Special head (250 Watts rms @ 4 Ohms). There is some dispute about its year of introduction; Long & McQuade’s Pat Coffey used one before going out to Vancouver in 1968, maybe it was an early prototype. In any case, this amp was another “first” - first to put out over 250 watts sine-wave. Weighing in at roughly 100lbs(!!) the YBA-3A looked identical to the YBA-3 except for the name and the type of output tubes. Unable to find audio tubes that would do the job unless used in large numbers (eg. eight 6CA7s) Pete decided on four 6KG6A TV vertical hold valves which looked like overgrown preamp tubes with metal caps. The Super Custom Special was actually capable of putting out over *400 Watts, but no bass or guitar pickups were powerful enough to drive it that hard. The good news was, it was virtually impossible to distort - great for bass players. The bad news was, guitar players generally did not like it and for exactly the same reason - no distortion. There was at least one exception; guitarist Jeff (Skunk) Baxter of the Doobie Brothers had one custom-built with no controls, just an on/off switch.
*To ensure the safety of the speakers, Super Custom Specials had to be used with two of the mammoth YC-810 or YR-412 cabinets, otherwise the warranty was void.
The YSR-2, Signature Reverb guitar combo (45 Watts rms @ 8 Ohms) was not what you might think. The name implies that it was a Signature amp (see 1965) with reverb added, but this was a totally new design and solid state at that - Pete’s first solid state instrument amp. It had four ten-inch speakers and two channels, one with volume bass and treble, the other with those controls plus reverb and tremolo. There was another control as well, another Yorkville “first” in fact - a master volume. However, despite having this rock- essential feature, the YSR-2 was almost incurably clean sounding. Guitarists looked elsewhere and the YSR-2 was discontinued a year later.

Yorkville dealers wanted a compact, lightweight PA amp as an alternative to the YVM-1. The 4-channel, solid-state YVM-2, Voice Mate (25 Watts rms @ 4 Ohms), was designed by Phil Simone, a technician hired during the lab expansion. Engineer/lab chief Paul Hallam provided advice and approved the final wiring diagrams - this now became standard practice.
And finally, something sought-after by certain guitarists was introduced in 1969 - a dual-horn version of the TRC-2A Roto-Master dubbed the TRC-2B. It too behaved like the top part of a Leslie cabinet and rather like a phase shifter, an effect pedal which appeared on the market about that time (oops). A year later both the TRC-2A and 2B were discontinued. Life goes on.
1970
This was the year when everything changed but hardly anything new was introduced. Confused? Well what happened was the external cabinet design went from rounded edges and metal corner pieces to straight edges protected by black and chrome bumper strip material. Strap handles on the larger speaker boxes were replaced by rectangular holes, one on each side of the cabinet, with force-fit metal trim top and bottom. A plastic cup was affixed to the inside of the cabinet to make the hand hole air-tight.
The ”Traynor” logo went through change number two this year. Going back to the beginning, the first version – a script-style cast aluminum affair - had been replaced in the mid-1960s by a plastic emblem sometimes referred to as the “rayno” sign. In this case the letters were angled and free-standing, all joined at the bottom to a narrow bar with the mounting screw holes through the bar just after the “T” and just ahead of the “r”. These holes were weak spots and whenever the products were subjected to the tortures they were so good at surviving, the logos would end up missing their T’s and r’s with “rayno” remaining stoically in place. Replacements were offered free of charge, but few people had the ambition to replace them.
The 1970 logo utillized the same angled letters, but with a reflective texture and molded into a black parallelogram with a silver border. There were two reasons for the change. Aside from the obvious need to replace “rayno”, the new ones would be used to pull off the grills on speaker cabinets. It soon proved necessary to back them up with a metal plate for this application, but the good news was that this indicates another 1970 product change and a good one at that. Now the speaker cabinets had solid backs (no more big access panels with a zillion screws holding them on) and the speakers were all front-mounted. With the grill screen now being pull-removable via the new logo (preferably reinforced), you could change a blown speaker in a fraction of the time it once took.
Another thing changed in 1970. Serial numbers went from four or five digits to seven digits with the manufacturing date coded into the first three. This system is still in use and might be worth noting. The first digit is the last digit of the year and the next two are the month. For example, serial number 0060001 would be from 1970, month number 06 (June). What about 1980 or 1990 or 2000? No problem. Yorkville usually changes the model designation or the product within ten years.

Talk about a “dry well”, new products for 1970 consisted of the YSC-7 (100 Watts rms, 8 Ohms) a four-twelve column, period! It featured two of the 12” Norelcos for midrange to high-frequency reproduction and two Eminence twelves for bass as well as some added power capacity. This marked Yorkville’s first use of the US-based Eminence speakers. It would not be the last.
The YPM-1 power module went into regular production in 1970 along with the MX-8 mixer. Now Yorkville dealers would have access to an eight-channel, 100-Watt PA system, something nobody else could claim at the time. Unfortunately the occasional neophyte dealer (not Long & McQuade) might sell an MX-8 without a YPM-1 leading the customer to think that it was broken because the speakers made no sound when plugged into it. But they soon learned how it all worked, purchased the necessary amplifier and the ground breaking system did well almost right from the outset. The YB-18A bass horn was also introduced to dealers in 1970 and it too was something very new, however it worked very well paired with a YBA-1A and sold briskly to rock bassists.
Pete’s sound contracting operation rolled along its bumpy road in 1970. Keep in mind, this may have been North America’s very first mobile concert sound system. With few or no precedents to guide them, Pete and his crew had to invent solutions on the spot. Sometimes they worked, sometimes not. Of course things broke down or got broken from time to time so everybody got to play repairman. Sometimes bands tried to use Pete and/or a crew member as a gofor - go for beer, go for pizza, etc. - and then there were the “road managers” and “personal managers” and “agents” and swarms of groupies and hangers-on all of whom put pressure on the sound guys to do this or that, or complained to them (or about them) regarding who knows what - all of which had absolutely nothing to do with the sound system. This job was turning out to be not nearly as much fun as Pete expected - and the contracts kept rolling in.
In time the grind began to take its toll. One of the worst things for Pete had to be starstruck performers who once treated him as a friend and guru now treating him like dirt. Added to all the other grief, this may have pushed him to the brink. The coup-de-grace was inadvertently dealt by one of the nicest people in music, Steve Miller. Pete had custom-designed him some YBA-3s with master volume controls, along with several 4x12” Cerwin Vega cabinets.
Previously Pete had demonstrated the YBA-3’s ruggedness by throwing one out a second-story window onto the street below. He then brought it back upstairs, shook out the broken glass, replaced the tubes, plugged it into a cabinet and it worked perfectly, a scenario that Steve Miller talked about for years afterwards. Pete was also contracted to do the sound for Steve’s Toronto gig, but on the big night, the new amps mysteriously cut out, one by one. It was later discovered that someone at Yorkville had installed the wrong fuses but that was of no help to Pete who disappeared, later to be found locked in a truck incoherently screaming oaths.
Worst of all possible things for Pete, Jack Long was there – he wasn’t as a rule. Pete must have been mortified beyond words, but however humiliating this may have been for him, it was actually a good thing for Yorkville Sound. Now Jack was fully involved in the situation.
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

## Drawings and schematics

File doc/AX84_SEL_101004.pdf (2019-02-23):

## WARNING! - Please Read this Information Carefully:

The project described in these pages utilizes POTENTIALLY FATAL HIGH VOLTAGES. If you are in any way unfamiliar with high voltage circuits or are uncomfortable working around high voltages, PLEASE DO NOT RISK YOUR LIFE BY BUILDING THEM. Seek help from a competent technician before building any unfamiliar electronics circuit. While efforts are made to ensure accuracy of these circuits, no guarantee is provided, of any kind!

USE AT YOUR OWN RISK: THE WEBMASTER, PROJECT COORDINATOR, PROJECT CONTRIBUTORS AND WEB SPACE PROVIDER EXPRESSLY DISCLAIM ALL LIABILITY FOR INJURY OR PROPERTY DAMAGE RESULTING FROM THIS INFORMATION! ALL INFORMATION IS PROVIDED 'AS-IS' AND WITHOUT WARRANTY OF ANY KIND.

## COPYRIGHT AND INTELLECTUAL PROPERTY NOTICE:

The content of this document is protected by the copyright laws of the United States of America and the international copyright laws and agreements.

Except where specifically noted, Cliff Chappell or Chris Hurley owns (or has permission to use) all intellectual property rights in relation to this document and its content (including, but not limited to, all trademarks and copyright).

No part of the document may be reproduced, displayed, copied, translated, adapted, downloaded, broadcast, used or republished in any form including (without limitation) distribution, or storage in a system for retrieval.

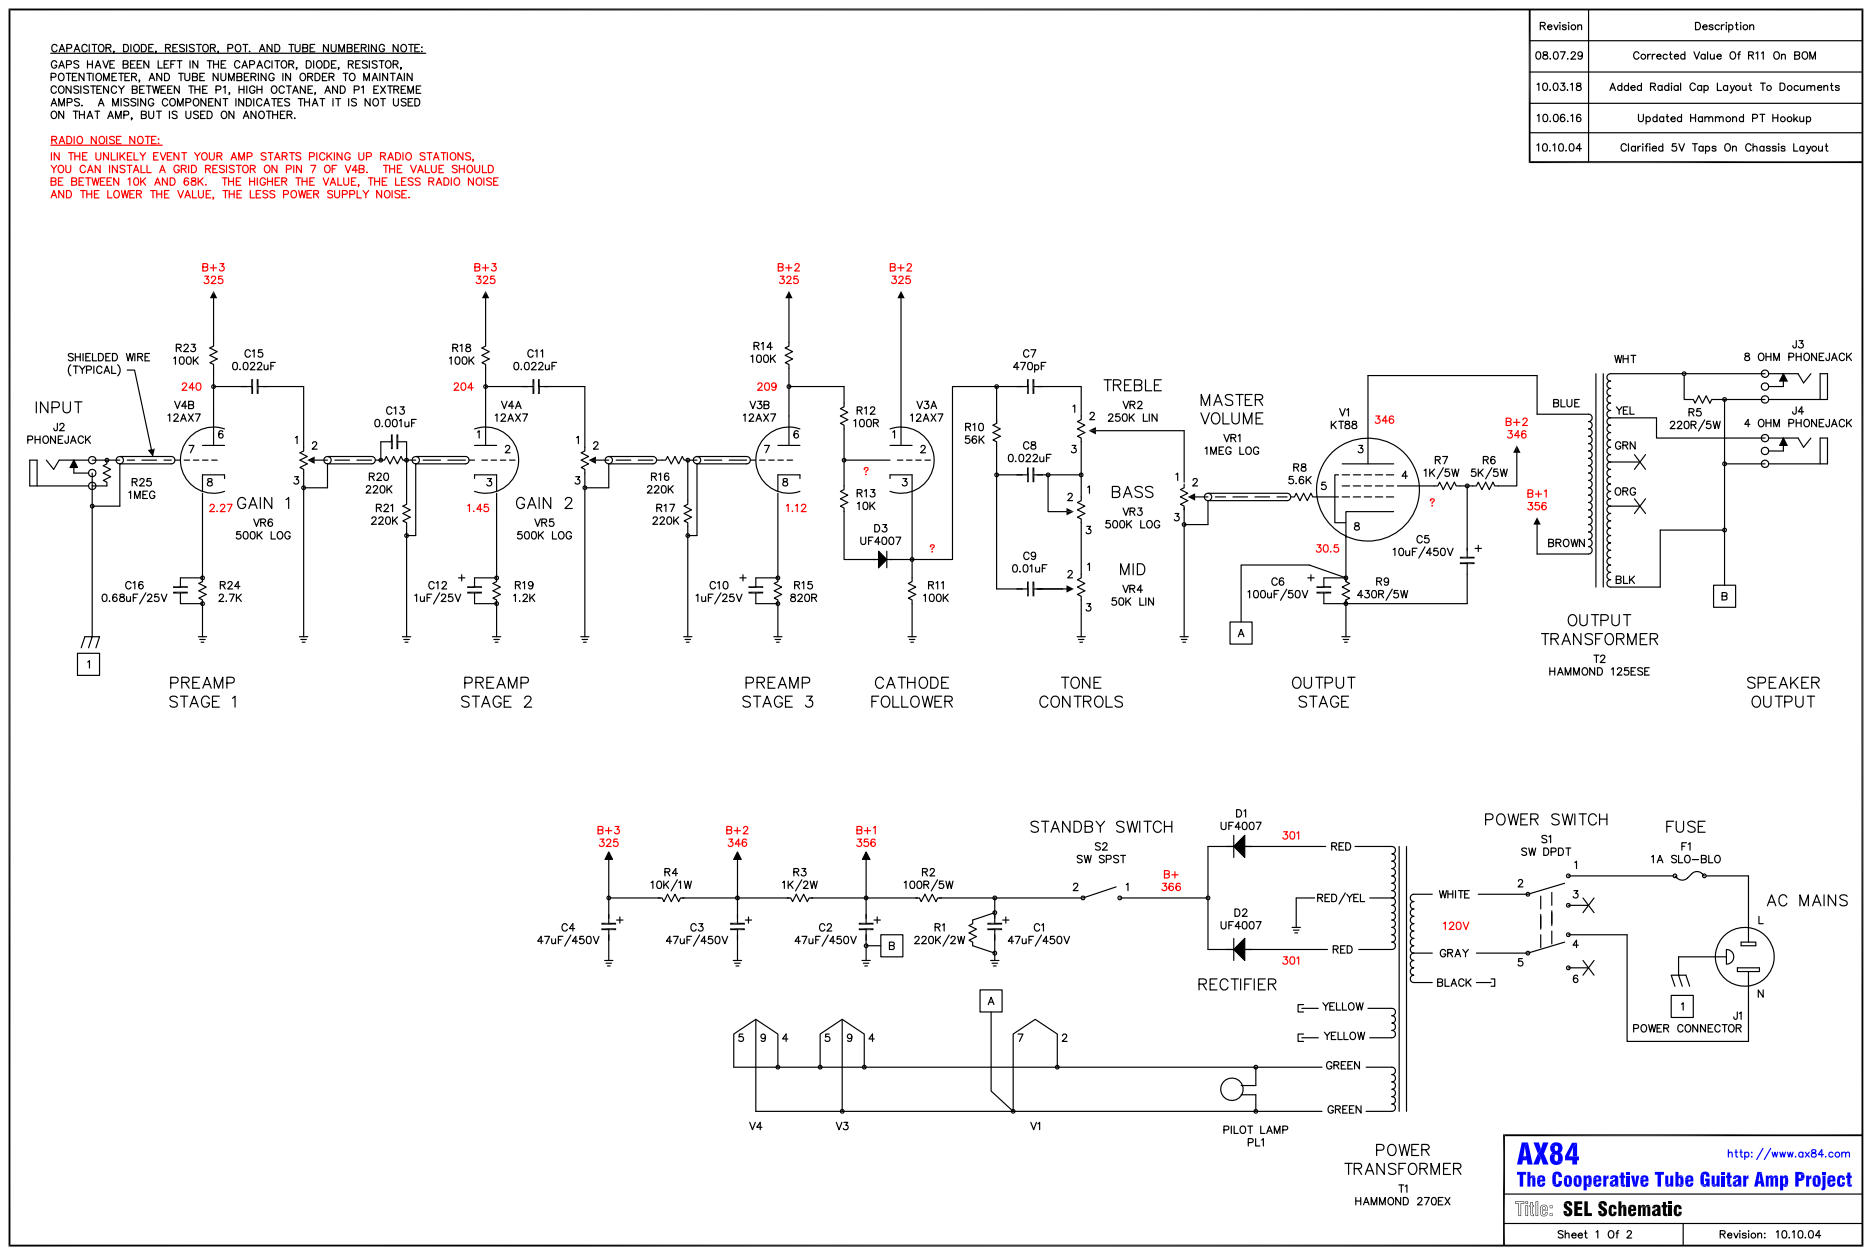
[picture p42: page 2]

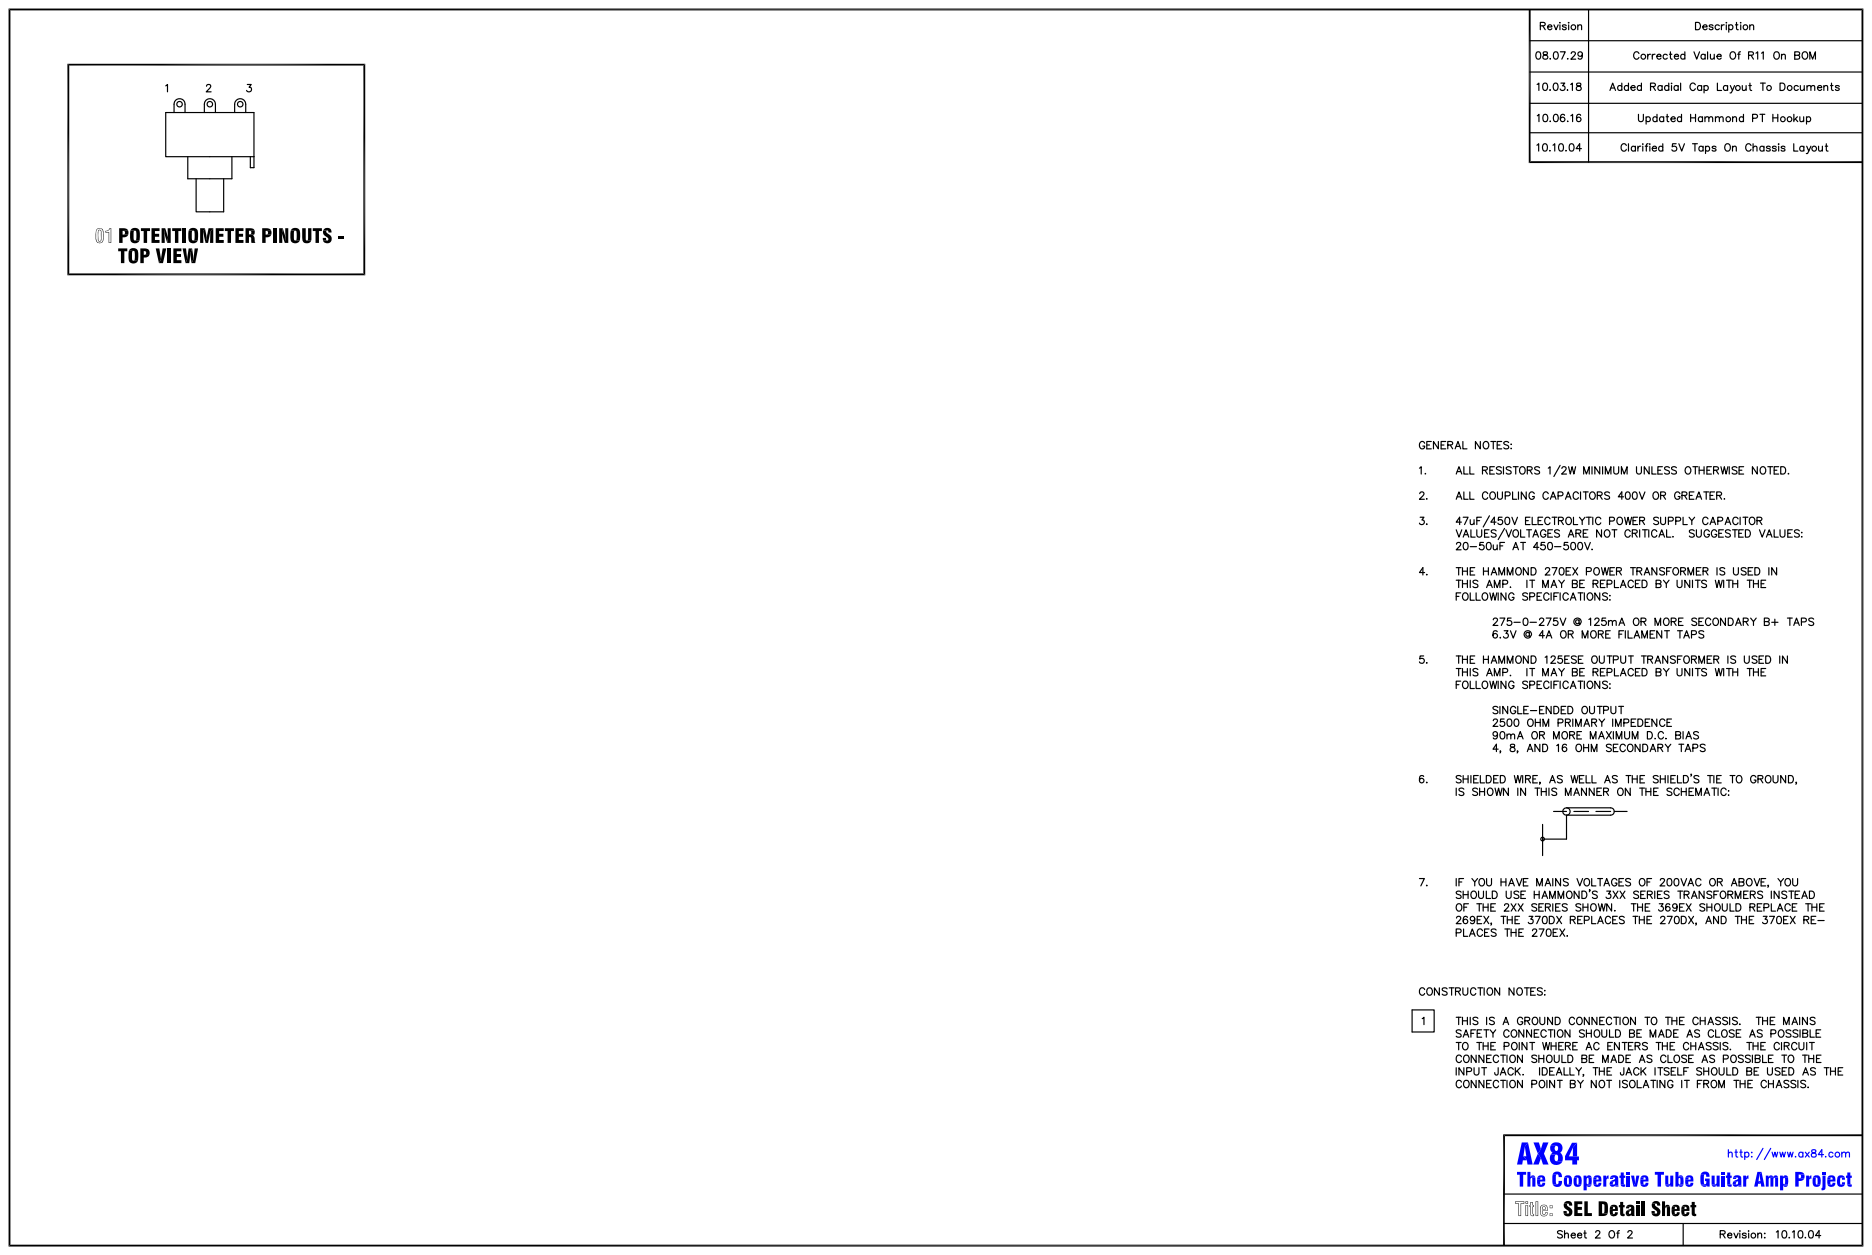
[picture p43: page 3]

AX84 SEL Amplifier BOM
Revision: 10.10.04
NOTE: Parts for options are not included on this bill of materials.
Item | Quantity | Reference | Value
1 | 4 | C1, C2, C3, C4 | 47uF/450V
2 | 1 | C5 | 10uF/450V
3 | 1 | C6 | 100uF/50V
4 | 1 | C7 | 470pF
5 | 3 | C8, C11, C15 | 0.022uF
6 | 1 | C9 | 0.01uF
7 | 2 | C10, C12 | 1uF/25V
8 | 1 | C13 | 0.001uF
9 | 0 | C14 | Not Used
10 | 1 | C16 | 0.68uF/25V
11 | 1 | R1 | 220K/2W
12 | 1 | R2 | 100R/5W
13 | 1 | R3 | 1K/2W
14 | 1 | R4 | 10K/1W
15 | 1 | R5 | 220R/5W
16 | 1 | R6 | 5K/5W
17 | 1 | R7 | 1K/5W
18 | 1 | R8 | 5.6K
19 | 1 | R9 | 430R/5W
20 | 1 | R10 | 56K
21 | 4 | R11, R14, R18, R23 | 100K
22 | 1 | R12 | 100R
23 | 1 | R13 | 10K
24 | 1 | R15 | 820R
25 | 4 | R16, R17, R20, R21 | 220K
26 | 1 | R19 | 1.2K
27 | 0 | R22 | Not Used
28 | 1 | R24 | 2.7K
29 | 1 | R25 | 1 Meg
30 | 1 | F1 | 2A SLO-BLO
31 | 1 | FH1 | Fuse Holder
32 | 1 | J1 | Power Connector
33 | 4 | J2, J3, J4, J5 | Phonejack
34 | 4 | JW1, JW2, JW3, JW4 | Phonejack Isolation Washer (if needed)
35 | 1 | S1 | SW DPDT
36 | 1 | S2 | SW SPST
37 | 3 | D1, D2, D3 | UF4007
38 | 1 | PL1 | Pilot Lamp Assembly And Bulb
39 | 1 | T1 | Hammond 270EX
40 | 1 | T2 | Hammond 125ESE
41 | 2 | SK3, SK4 | 9 Pin Tube Sockets
42 | 1 | SK1 | 8 Pin Octal Socket
43 | 1 | V1 | KT88
44 | 2 | V3, V4 | 12AX7
45 | 1 | VR1 | 1Meg LOG

46 | 1 | VR2 | 250K LIN
47 | 3 | VR3, VR5, VR6 | 500K LOG
48 | 1 | VR4 | 50K LIN
49 | 6 | K1, K2, K3, K4, K5, K6 | Knobs
50 | 1 | CH1 | Chassis

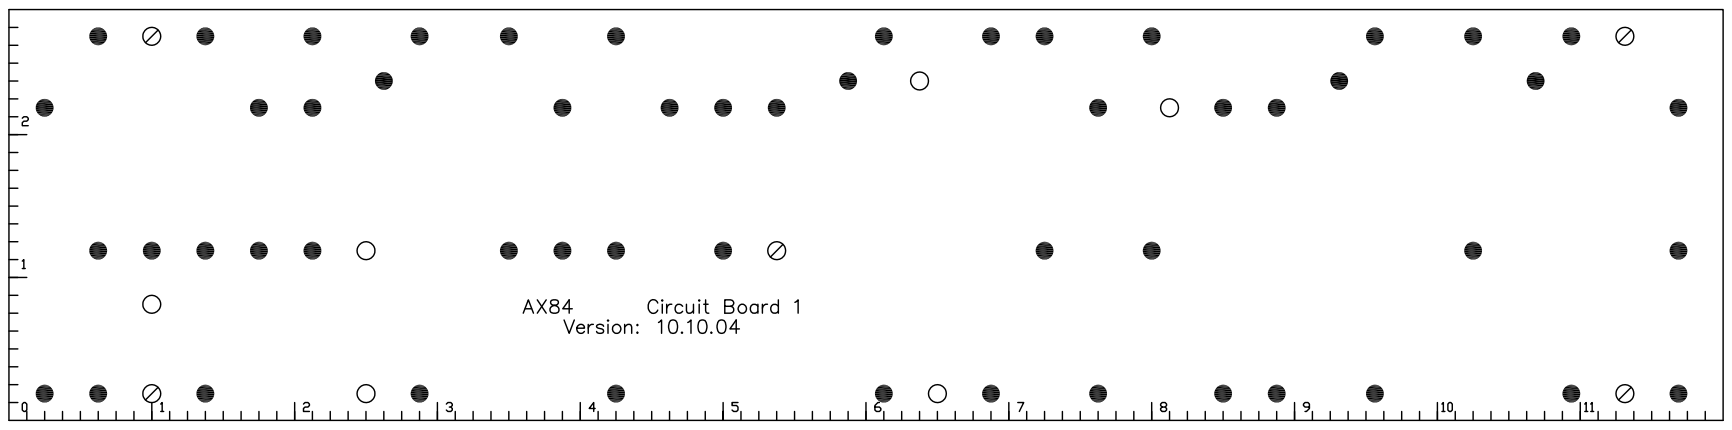
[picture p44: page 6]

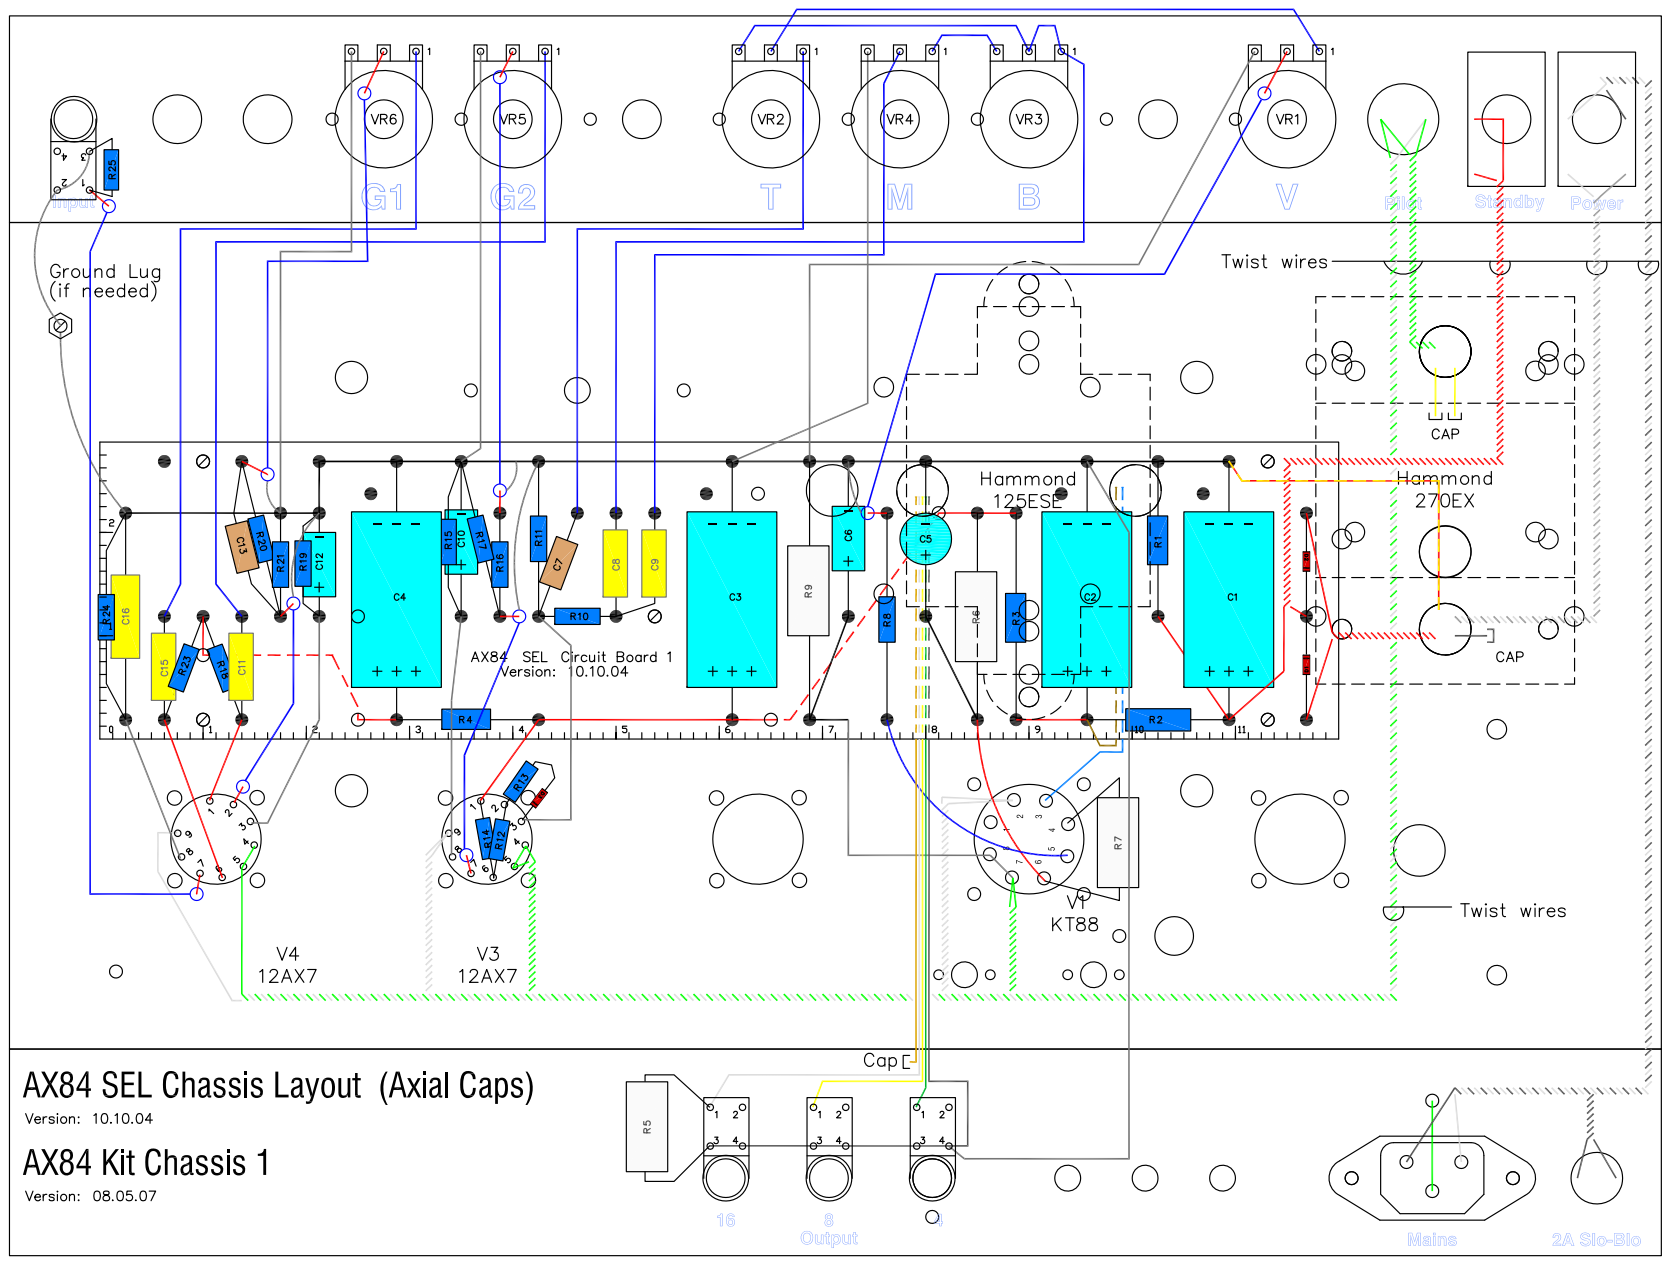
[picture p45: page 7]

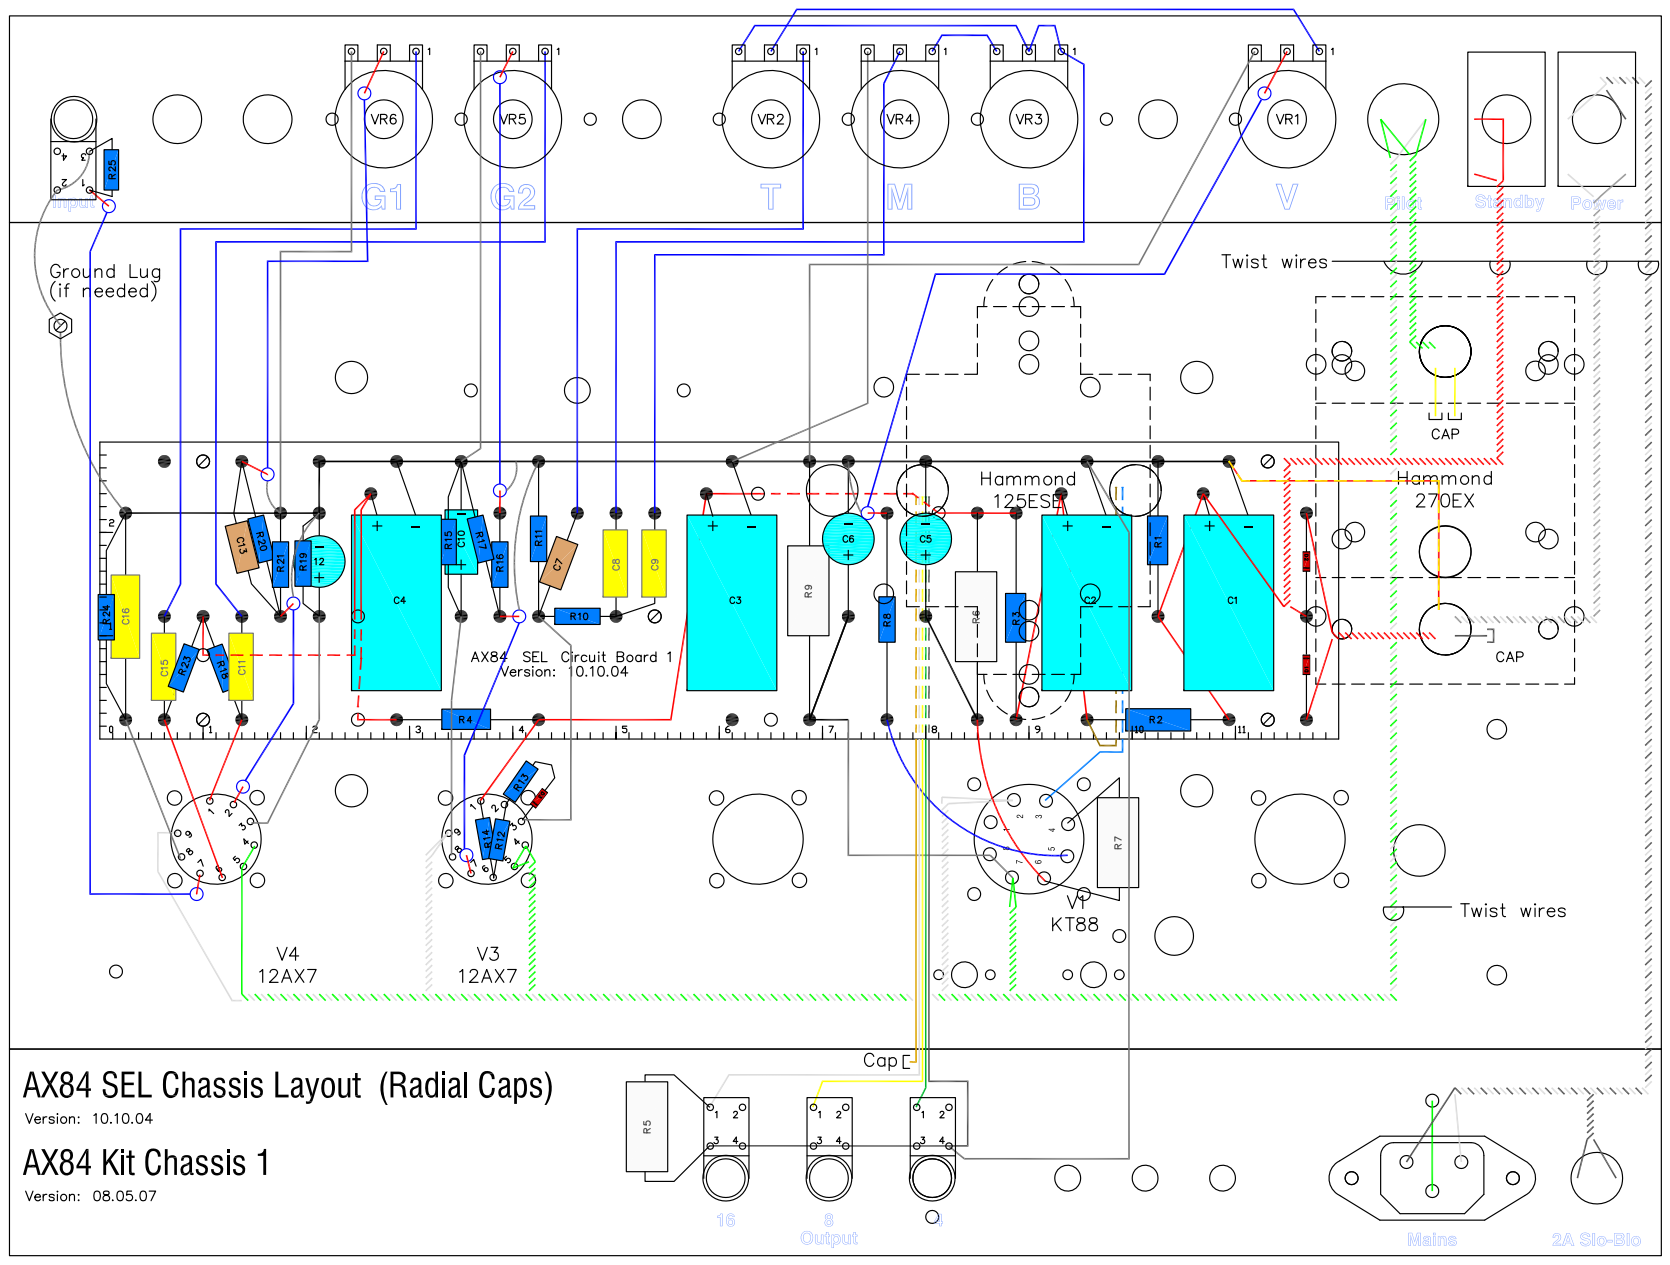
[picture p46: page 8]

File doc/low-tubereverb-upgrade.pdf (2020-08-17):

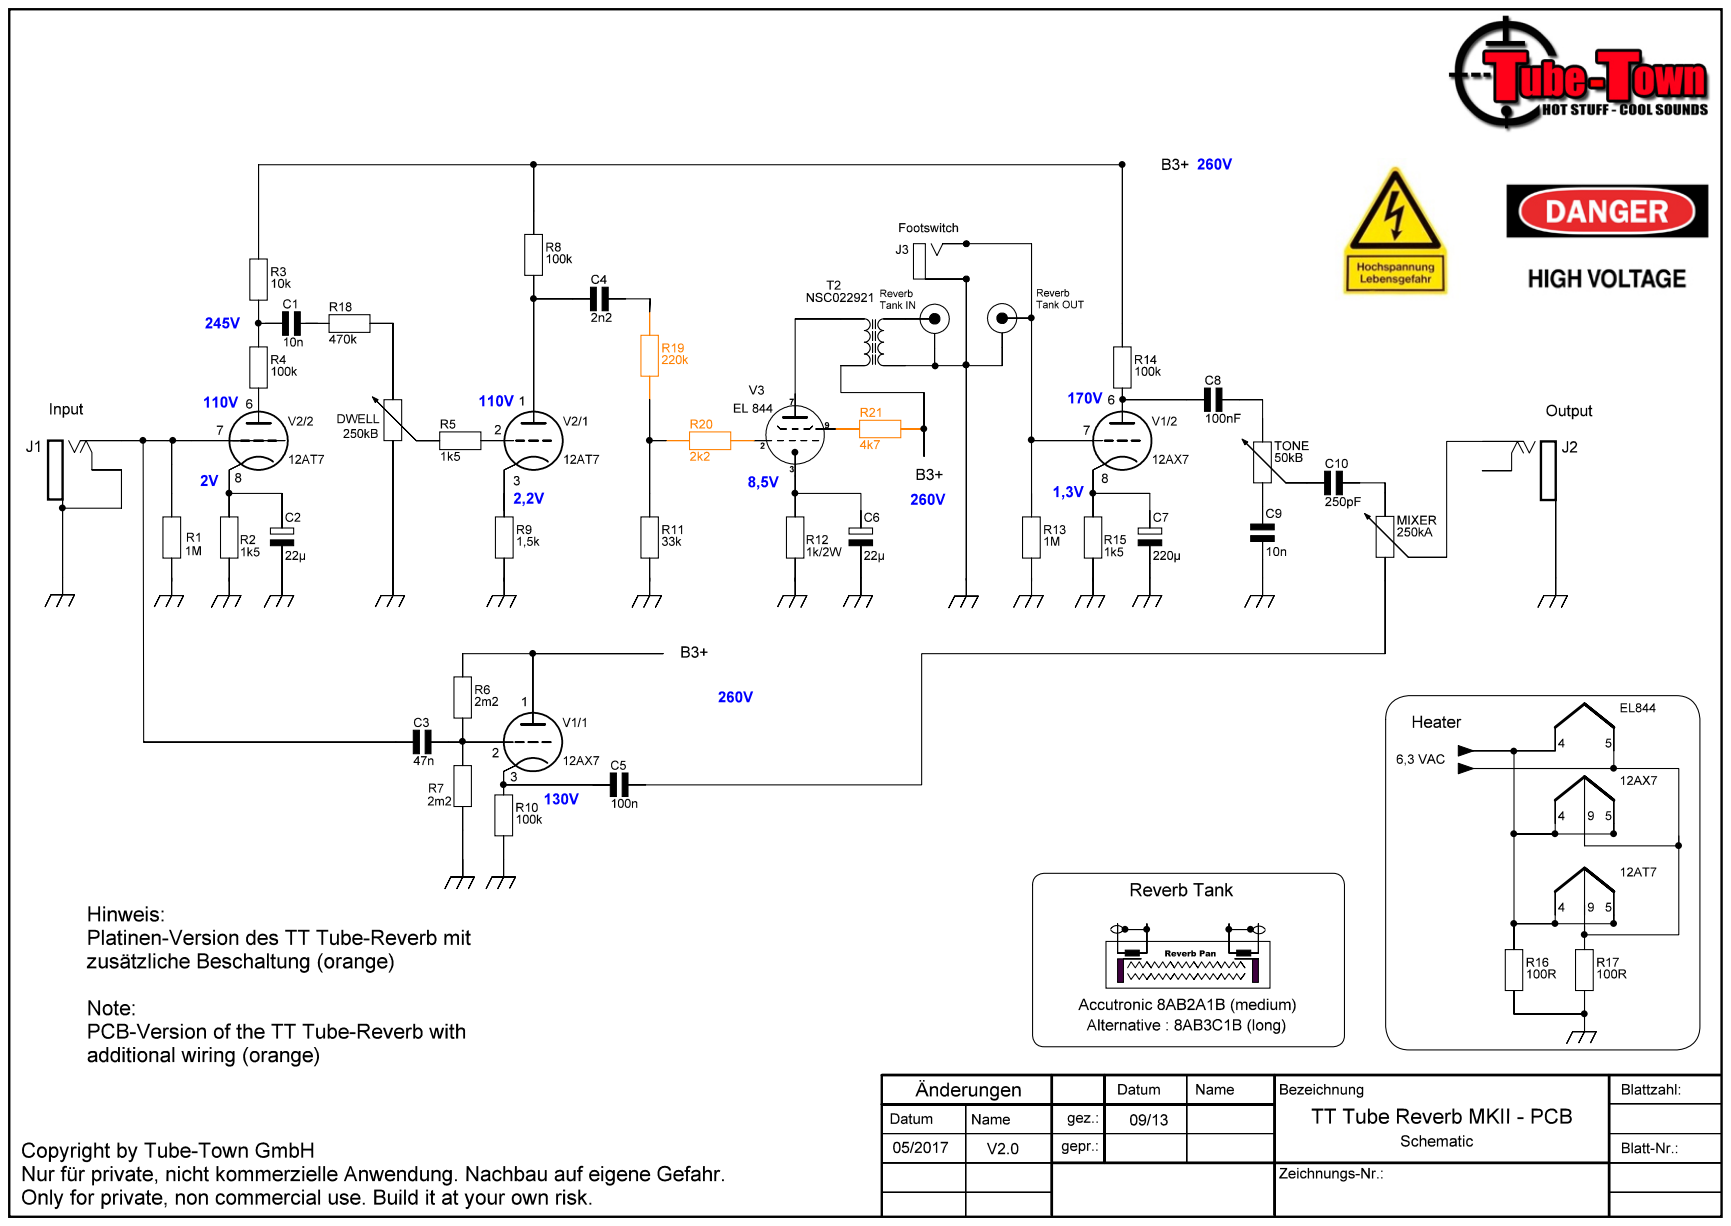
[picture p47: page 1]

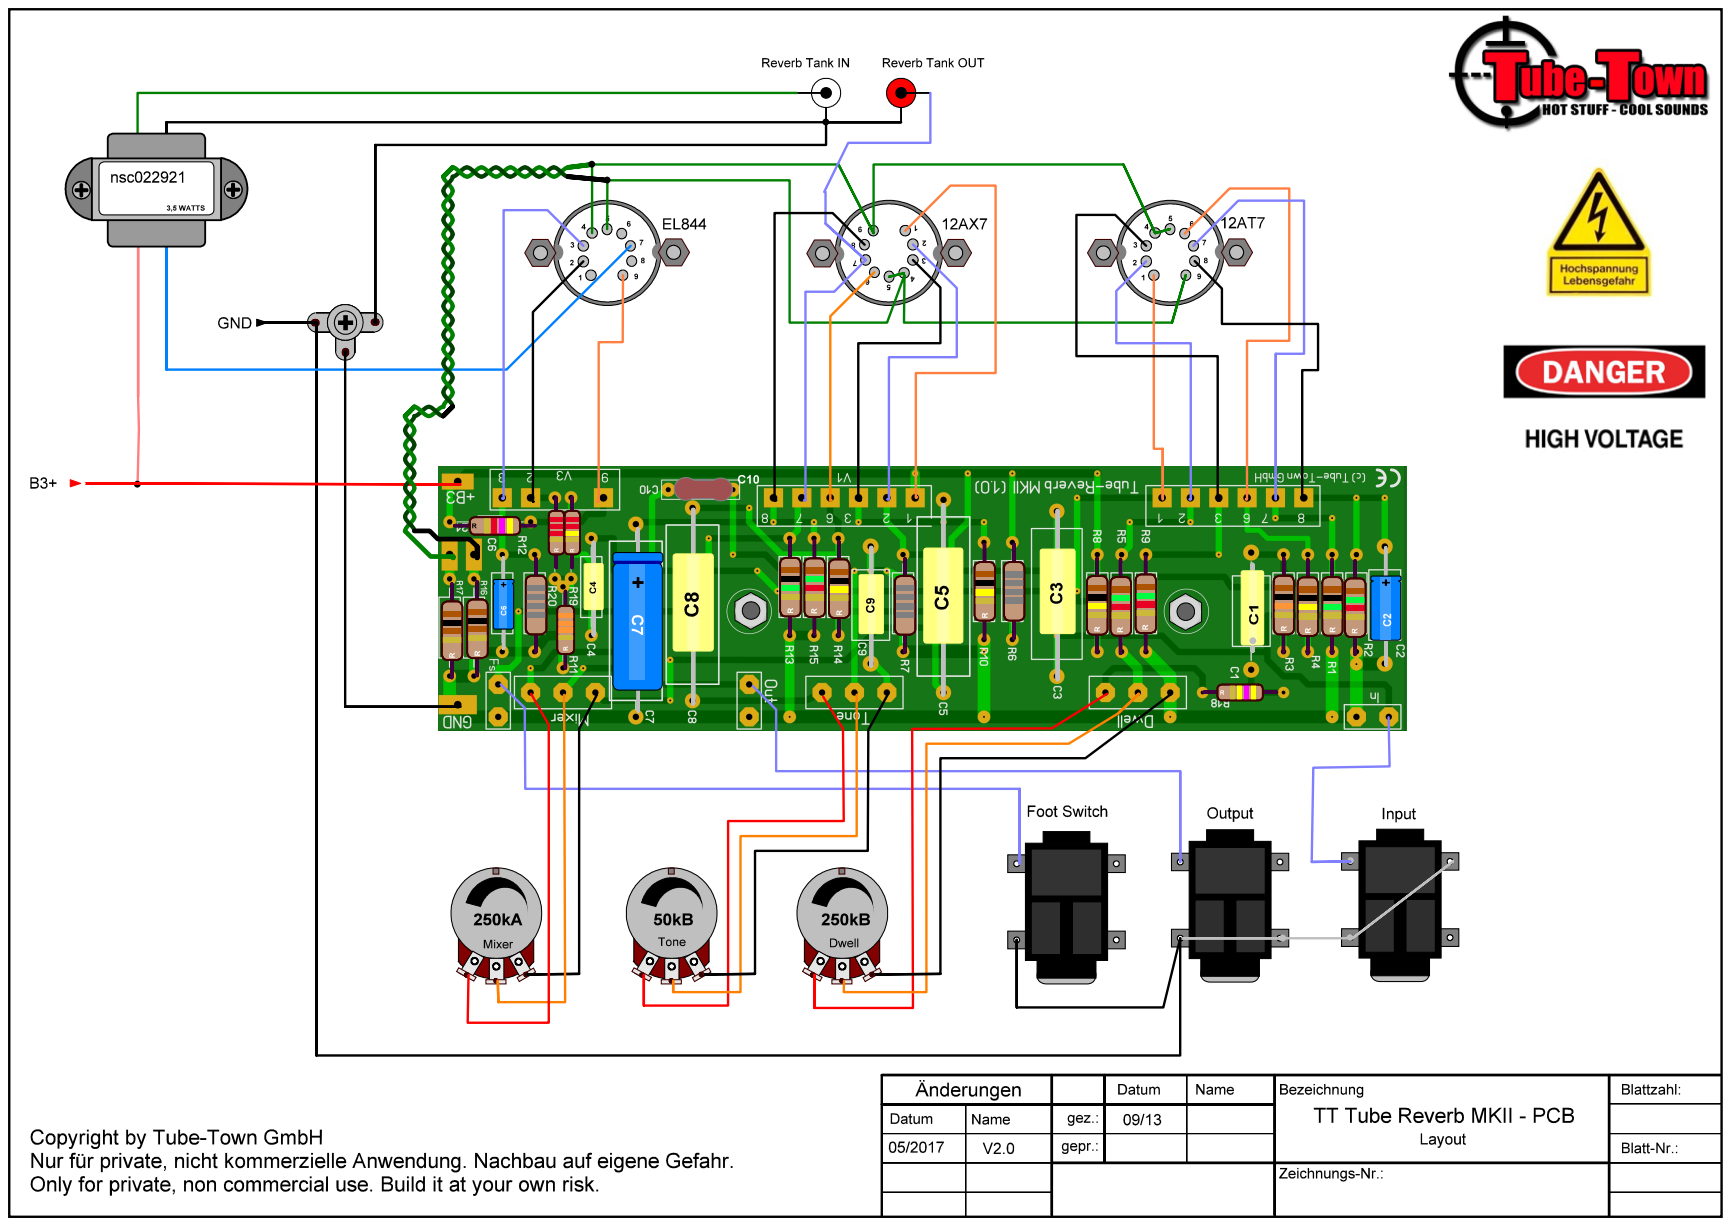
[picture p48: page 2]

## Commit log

2019-01-31 v1 as built
    [traynor_power_supply.kicad_pcb, traynor_power_supply.sch]
2019-01-31 change the 100uF capacitor to be 2 47uF capacitors
    find there was a capacitor without a footprint on the schematic too, so we were missing it before.
    [traynor_power_supply.kicad_pcb, traynor_power_supply.sch]
2019-02-01 pcb layout for v1.1
    [traynor_power_supply.kicad_pcb]
2019-02-01 original schematic
2019-02-01 create schematics for each module
    using the original schematic break it apart into pieces to analyze
    [inputs.kicad_pcb, inputs.sch, power_stage.kicad_pcb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]
2019-02-01 create a mapping of our schematics to original schematic
    the part reference numbers are different in my schematics from the original one because I am using a schematic per module.
    This helped me to make sure I had all the parts ordered, and so when I can see where I am using a different part.
    [parts_reference.ods]
2019-02-02 Hacking for Feb 1st, 2019
    [actual.kicad_pcb, actual.sch, preamp.sch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]
2019-02-02 add picture of the new bass tone stack capacitor
2019-02-02 move discussion of power supply module to hacking file
    I want the readme to be the description of how the amp works as it was designed.
2019-02-02 refine tone control schematic
    some things are chassis mounted
    [tone_control.sch]
2019-02-02 thoughts on tone control hacking
    probably won't bother here. The kind of modular setup I am looking for needs a different chassis. Like card slot or something.
2019-02-04 Update documentation
    Measure the voltages at the different points.
2019-02-04 Refine schematics
    Describe the parts that are mounted on the chassis
    [traynor_power_supply.sch, vibrato.sch]
2019-02-04 Install IEC power connector
2019-02-06 Rebuild the tone control circuits
2019-02-06 Replace tremolo circuits.
2019-02-08 Replace the output stage components.
2019-02-08 start a schematic for an external preamp
    wanting a separate module as an overdrive unit.
    This amp seems to be designed for clean tone, full bass response. Overdriving the tubes in the amp as it is wired just does not sound very good at all.
    Inspired by "tube driver" guitar pedal, and a preamp circuit from ax86.com
    [external_preamp.kicad_pcb, external_preamp.sch]
2019-02-13 Monday night hacking
    [actual.sch, external_preamp-2019-02-08-22-07-09.sch, external_preamp.sch]
2019-02-23 power supply module
    assemble circuit board after it arrived.
    update schematic to fix bugs and small improvements we observed while wiring it up.
    [traynor_power_supply.kicad_pcb, traynor_power_supply.sch]
2019-02-23 start designing a different preamp
    one channel with two stages. Similar to what the preamp on ax84 site.
    [ax84_preamp_mod.kicad_pcb, ax84_preamp_mod.sch, ax84_preamp_mod_bom.ods]
2019-02-26 schematic and analysis for ax84 preamp mod
    Replacing the two separate inputs with a single two stage input to attempt to get nice overdrive tones.
    [ax84_preamp_mod.sch, external_preamp.sch]
2019-03-01 put it back together
    change the preamp triode. new power tubes.
    back in its case and installed as a feature in my room.
2019-03-11 tinkering
    remove tone cap.
    update schematic.
    combine status with changelog
    [ax84_preamp_mod.sch]
2020-08-17 Update schematic and design reverb unit
    Create a schematic to capture all the changes that have been done. There have been many small fiddle things but not even an electronic version of the full schematic.
    Find a schematic for a reverb unit and add it to the amp schematic.
    [actual.sch, preamp_module.sch]
2020-08-17 parts list and order for reverb driver circuit
    [actual.sch, bom.ods]
2020-08-17 add documentation
    it was not convenient to see the schematic from the git repo.
    Now have picture screen caps from kicad and a readme to explain things.
2020-08-18 more tinkering
    [actual.sch]
2020-08-22 update schematic after assembling reverb unit
    [actual.sch]
2020-08-22 swap V2 for 12AT7
    [actual.sch]
2020-08-29 Major renovations
    * Replace phase inverter with op-amp phase inverter.
    * Create a dual rail DC op-amp power supply driven off the filament supply lines.
    * Replace 7027 tubes with 6L6GC tubes.
    * Add switched IEC outlet.
    [actual.sch]
2020-08-30 add bypass capacitors to tube gain stage following op-amp phase inverter.
    [actual.sch]
2020-09-08 fixing bugs
    [actual.sch]
2020-09-24 evening hacking
    fix more buzz by rewiring the V2 socket.
    Install RG-178 coax on most of the signal path. Reduce a bit more noise.
    Remove the preamp circuit all together. Going to work on designing a better sounding one that handles overdrive better.
    Debbug the reverb mix knob setting oscillation issues.
    [actual.sch]
2020-09-26 build a new preamp
    having both 12AX7 and EF86 as switchable option for first stage.
    [actual.sch]
2020-10-14 weekend hacking
    [actual.sch]
